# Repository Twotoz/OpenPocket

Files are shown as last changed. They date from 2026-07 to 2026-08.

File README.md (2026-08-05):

<p align="center">
  OpenPocket — an ESP32-S3 handheld FPV controller with an AMT630A display
</p>

<p align="center">
  
  
  
  
  
  
</p>

<p align="center">
  <strong>A compact all-in-one ESP32-S3 handheld PCB combining RivetTX, ExpressLRS, RX5808 video, AT7456E OSD, and an AMT630A-driven 5-inch TFT.</strong>
</p>

<p align="center">
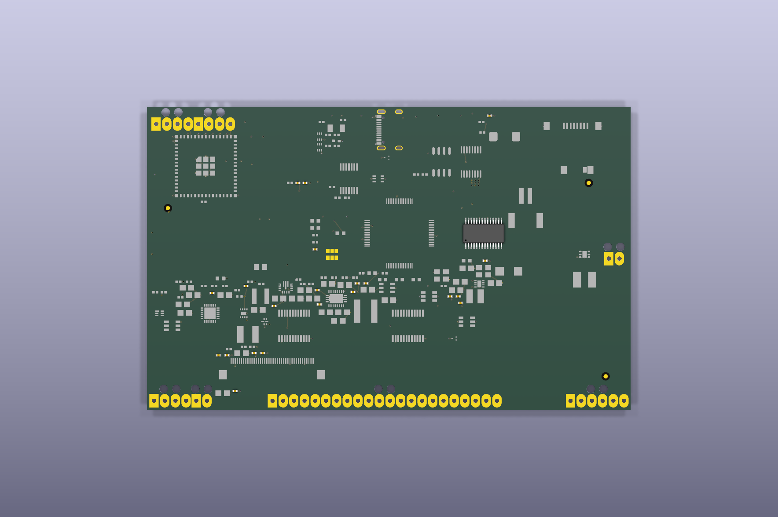
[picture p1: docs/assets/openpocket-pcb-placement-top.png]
OpenPocket Revision-A top-side component placement without board text or signal traces
  
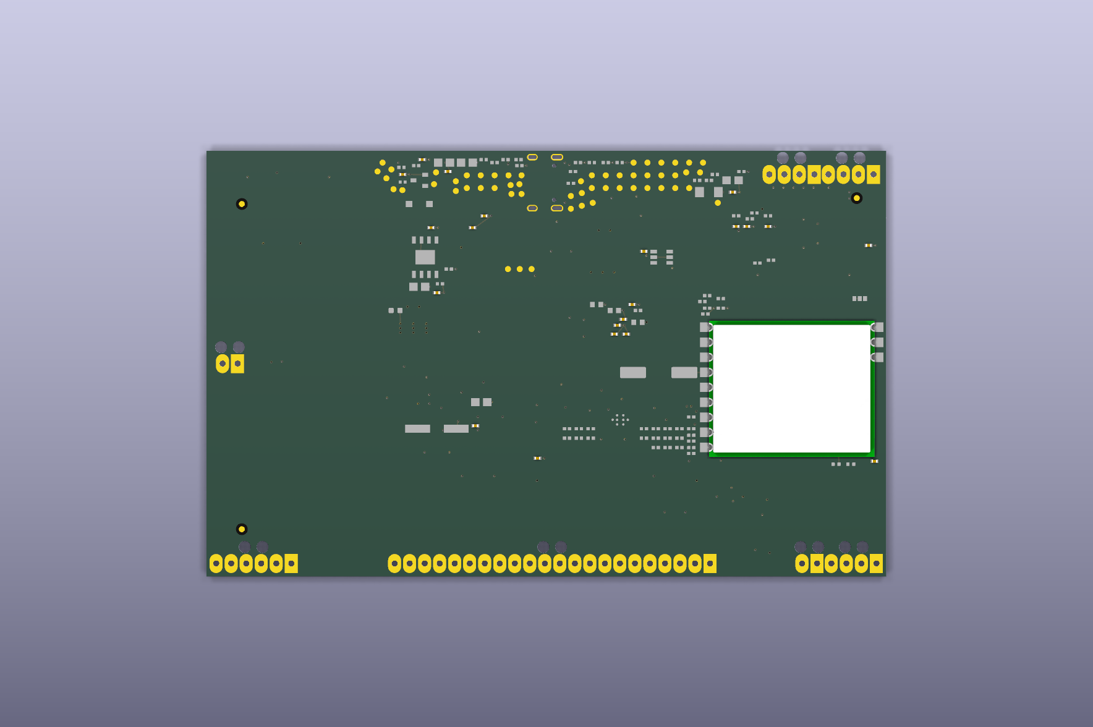
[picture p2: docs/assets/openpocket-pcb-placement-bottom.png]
OpenPocket Revision-A bottom-side component placement without board text or signal traces
  
</p>

<p align="center"><em>Revision-A top and bottom placement previews — production-board text and signal routing intentionally omitted.</em></p>

<p align="center">
  <a href="#why-openpocket">Why OpenPocket</a> ·
  <a href="#architecture">Architecture</a> ·
  <a href="#hardware">Hardware</a> ·
  <a href="#build-path">Build path</a> ·
  <a href="#firmware">Firmware</a> ·
  <a href="#documentation">Documentation</a>
</p>

> [!CAUTION]
> OpenPocket is an engineering prototype, not a flight-proven product. Build
> the first revision on a current-limited bench supply. Keep propellers removed
> and mechanisms safe until your exact transmitter, failsafe, power system,
> RF link, and video chain have passed hardware-in-the-loop validation.

## Why OpenPocket

OpenPocket puts the controls, live analog FPV picture, and transmitter menus in
one compact handheld. It uses the existing RivetTX OpenPocket character
compositor unchanged and connects it to a physical AT7456E video-overlay
backend. The ESP32 never has to capture or process video pixels.

| | |
|---|---|
| **One handheld** | Gimbals, switches, ExpressLRS control, telemetry, video, and menus in a single enclosure. |
| **Purpose-built MCU** | ESP32-S3 provides the GPIO, native USB, and task separation needed by the complete controller. |
| **Low-latency video** | RX5808 composite video passes through the AT7456E into an AMT630A TFT controller without digital capture. |
| **Integrated snow-screen display** | The PCB-installed AMT630A keeps weak or lost analog video visible as noise instead of hiding it behind a blue screen. |
| **Native analog OSD** | PAL/NTSC autodetection, a 30×16 character grid, custom glyphs, delta updates, and video-loss recovery. |
| **Bounded background work** | OSD and receiver services cannot delay control, CRSF, or telemetry processing. |
| **Open development path** | Wiring, BOM decisions, bring-up evidence, and future KiCad sources live in this repository. |

## Architecture

The flight-control path stays short while video and presentation work run as
bounded services.

```mermaid
flowchart LR
    A[Gimbals + switches] --> B[ESP32-S3<br/>RivetTX]
    B --> C[CRSF UART]
    C --> D[ExpressLRS<br/>TX module]

    E[5.8 GHz antenna] --> F[RX5808]
    F -->|composite video| G[AT7456E]
    G -->|internal PCB trace| H[AMT630A<br/>on the same PCB]
    H -->|24-bit RGB + sync| I[AT050TN33 V.1<br/>40-pin TFT]

    B -->|tune + RSSI| F
    B -->|bounded SPI| G
    D -->|telemetry| B

    classDef control fill:#102a43,stroke:#38bdf8,color:#f8fafc;
    classDef video fill:#26163f,stroke:#a78bfa,color:#f5f3ff;
    class A,B,C,D control;
    class E,F,G,H,I video;
```

The 250 Hz control task owns channel output and safety. The OSD driver advances
a non-blocking state machine and writes only changed character runs. Video
loss, PAL/NTSC changes, or an absent OSD chip must never hold up the control
path.

## Hardware

| Component | Role |
|---|---|
| ESP32-S3-MINI-1U-N8 | PCB-installed RivetTX MCU, native USB, 8 MiB flash, no PSRAM |
| user-installed ExpressLRS nano receiver | four-wire full-duplex CRSF control and telemetry link |
| PCBWay-installed RX5808 module | tunable 5.8 GHz analog receiver, internal composite video, and RSSI |
| PCB-installed AT7456E | PAL/NTSC character overlay in the internal video path |
| PCB-installed AMT630A and flash | PAL/NTSC composite decoding and direct 24-bit RGB panel drive |
| AT050TN33 V.1-compatible TFT | user-plugged 40-pin panel; arbitrary 40-pin TFTs are unsupported |
| two dual-axis gimbals | four primary analog control axes |
| switches, menu buttons, and optional encoder | arming, AUX controls, navigation, and editing |
| validated regulators and protection | clean supplies sized for RF, display, video, and logic peaks |

The ESP32-S3 is the OpenPocket target. RivetTX may support smaller ESP32-C3
transmitters, but the C3 is not the reference platform for this handheld. See
[ADR-0001](docs/decisions/0001-esp32-s3.md) for the decision record.

## Analog OSD

The existing RivetTX compositor produces a hardware-independent 30-column by
16-row character frame. The AT7456E backend then provides:

- PAL/NTSC autodetection and safe standard changes without a reboot
- all 30×16 cells in PAL, with essential content held inside 30×13 for NTSC
- custom character uploads for icons, selection markers, and warnings
- shadow-frame comparison so unchanged cells generate no SPI traffic
- bounded asynchronous transfers instead of full-screen blocking redraws
- communication retry/backoff and redraw after video loss or recovery

The RX5808 feeds baseband video to the AT7456E over an internal PCB trace; the
AT7456E overlays text and passes it internally to the AMT630A, which drives the
edge-connected TFT directly. The user never wires composite video. The
AMT630A's internal OSD is not used for OpenPocket menus. See the
[complete wiring guide](docs/wiring.md).

## Build path

Bring up one subsystem at a time:

1. Review the [Revision-A engineering package](hardware/rev-a/README.md) and
   resolve every machine-readable release blocker.
2. Complete independent schematic, layout, sourcing, and Gerber reviews.
3. Assemble first articles through PCBWay with the RX5808 consigned/manual
   operation and no unapproved substitutions.
4. Power the board from a current-limited source and validate rails before
   inserting the TFT, battery, or ExpressLRS receiver.
5. Complete the factory and HIL gates before any propeller-on use.

The [bench build guide](docs/build-guide.md) contains the full sequence and
stop conditions. Do not order from provisional files or bypass the release
gate in `hardware/rev-a`.

## Firmware

OpenPocket runs the `main` branch of
[Twotoz/RivetTX](https://github.com/Twotoz/RivetTX):

```bash
git clone https://github.com/Twotoz/RivetTX.git
cd RivetTX
idf.py set-target esp32s3
idf.py menuconfig
idf.py build
idf.py flash monitor
```

Use RivetTX's checked-in `sdkconfig.openpocket-rev-a.defaults`; it contains the
authoritative no-PSRAM, 8 MiB flash configuration and GPIO map matching this
board. See the [firmware guide](docs/firmware.md) for the complete configuration.

## Documentation

| Document | Contents |
|---|---|
| [Bill of materials](docs/bom.md) | prototype parts, electrical requirements, and unresolved selections |
| [Wiring](docs/wiring.md) | ESP32-S3, RX5808, AT7456E, AMT630A, TFT, and ExpressLRS interconnects |
| [Bench build guide](docs/build-guide.md) | staged assembly sequence and stop conditions |
| [Firmware](docs/firmware.md) | ESP32-S3 target setup and RivetTX OSD configuration |
| [Bring-up checklist](docs/bring-up.md) | electrical, control, PAL/NTSC, failure-recovery, and endurance tests |
| [Architecture](docs/architecture.md) | task boundaries, character presentation, and video path |
| [ESP32-S3 decision](docs/decisions/0001-esp32-s3.md) | why OpenPocket standardizes on the S3 |
| [AMT630A display decision](docs/decisions/0002-amt630a-snow-screen.md) | why the display stage uses a snow-screen AMT630A board |
| [Hardware sources](hardware/README.md) | scope and release policy for future KiCad and production files |
| [Revision-A package](hardware/rev-a/README.md) | integrated board constraints, GPIO, power, BOM, factory test, and release gates |
| [AMT630A firmware](display/amt630a/README.md) | target behavior, provenance requirements, and deterministic build gate |

## Project status

RivetTX contains the character OSD and physical RX5808/AT7456E services, with
host coverage for PAL, NTSC, UI, tuning, scanning, RSSI, delta updates, glyphs,
loss/recovery, and failure isolation. Revision-A startup ordering, board power
policy, and the no-PSRAM pin/partition profile are under review.

No PCB order package is released yet. The exact panel datasheet, AMT630A
firmware rights/provenance, selected RX5808 consigned module, sourcing review,
KiCad ERC/DRC, Gerber inspection, and physical HIL evidence remain open. This
is intentionally an engineering prototype, not a production-ready product.

## Contributing

Issues, schematic reviews, module measurements, and focused pull requests are
welcome. Hardware findings must identify the exact module revision, voltage,
firmware commit, measurement point, and PAL/NTSC source. See
[CONTRIBUTING.md](CONTRIBUTING.md).

## License

OpenPocket documentation and future hardware sources are released under the
[MIT License](LICENSE). RivetTX is maintained in its own repository under its
own license.

---

<p align="center">
  <sub>Built for open hardware experimentation, low-latency analog FPV, and careful validation.</sub>
</p>

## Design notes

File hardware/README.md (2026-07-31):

# Hardware sources

The [Revision-A engineering package](rev-a/README.md) is the authoritative
location for the integrated board's requirements, controlled selections, and
release evidence. It will contain the releasable sources for:

- KiCad schematic and PCB files
- controlled BOM with manufacturer part numbers
- integrated AMT630A circuit, licensed flash revision, and matched TFT panel
- Gerber, drill, and pick-and-place files
- mechanical drawings and enclosure interfaces
- test points and fixture documentation

No production files have been released yet. `rev-a/tools/release_gate.py`
refuses artifact generation while primary-source, sourcing, review, or HIL
evidence is missing. Use first articles only on a current-limited bench until
all formal and physical gates pass.

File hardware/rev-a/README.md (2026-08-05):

# OpenPocket Revision A — Engineering Prototype

Revision A is a 115 mm × 72 mm, eight-layer, all-in-one transmitter board based
on the ESP32-S3-MINI-1U-N8. The intended assembled signal path is:

```text
5.8 GHz antenna -> RX5808 -> AT7456E -> AMT630A -> 40-pin ER-TFT050A3-2
```

Composite video never leaves the PCB. JLCPCB Standard PCBA is the primary
assembly target, with pre-order and consigned-RX5808 variants; the design is
vendor-neutral. The user installs
only the TFT panel, controls, one wired protected 1S battery connection,
antennas, a pre-flashed ExpressLRS nano receiver, and the enclosure.

## Release state

This directory is an engineering-review package, not an order package. The
release script intentionally refuses to generate Gerbers or a manufacturing
ZIP until every blocking item in `release-status.json` is resolved with a
reviewed source artifact.

The generated KiCad draft has a clean ERC and a completed L2 ground fanout,
but signal routing and final DRC remain incomplete. It is therefore not a
fabrication/order package. The source-built AMT630A firmware and circuit
research may be reviewed independently, but they do not waive schematic,
layout, Gerber and first-article gates. Software tests are not hardware
validation.

## Design constraints

- 115 mm × 72 mm fixed outline.
- Eight layers, 1.0 mm finished thickness, 1 oz copper, ENIG.
- L1/L8 components and critical routing, uninterrupted L2/L7 ground, and six
  available routing layers for signals and width-controlled power routes.
- RX5808 on the bottom side with shield, solder-joint, antenna and inspection
  clearances; J11 U.FL/MHF1 is also bottom-side for a via-free 5.8 GHz feed.
- AMT630A next to the edge-mounted TFT connector; AT7456E on the short analog
  path between RX5808 and AMT630A.
- Backlight switching and power converters stay outside the analog/RF region.
- Separate ESP32, ELRS 2.4 GHz, and RX5808 5.8 GHz antenna regions.
- Dedicated user-accessible push-push microSD at 1-bit/20 MHz maximum, with
  switched power and enclosure finger/eject clearance.
- Board marking: `OpenPocket Rev A` and `Engineering Prototype`.

## Contents

| File | Purpose |
|---|---|
| `gpio-map.md` | authoritative ESP32 and expander allocation |
| `microsd.md` | SDMMC circuit, socket audit, limits and acceptance tests |
| `wiring.md` | internal and user-installed connections |
| `power-budget.md` | preliminary worst-case and thermal calculations |
| `routing-constraints.md` | KiCad netclasses, widths, vias and routing order |
| `stackup.md` | nominal 1.0 mm eight-layer construction and impedance sign-off gate |
| `bom.csv` | controlled component selection and verification state |
| `dnp.csv` | optional/DNP items |
| `consigned-parts.csv` | RX5808 manual-assembly requirement |
| `release-status.json` | machine-readable evidence and blockers |
| `factory-test.md` | pass/fail protocol and first-article sequence |
| `pcbway-notes.md` | stack-up, assembly, inspection, and substitution rules |
| `tools/release_gate.py` | refuses an unsafe manufacturing release |

Fabrication outputs and a versioned release ZIP must only be generated after
the KiCad sources pass review, ERC, DRC and independent Gerber inspection.

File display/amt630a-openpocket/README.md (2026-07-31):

# OpenPocket AMT630A firmware

This directory contains an original MIT-licensed SDCC/mcs51 firmware for the
AMT630A used by OpenPocket Revision A. It is built from register documentation,
the AMT630A product specification, and public reference-circuit observations;
it is not a monitor-board dump and contains no vendor firmware.

`make test` builds a deterministic 64 KiB W25X05 image and verifies panel
timing, PAL/NTSC state handling, sync-loss recovery, CVBS1 selection, RGB pin
muxing, and that documented snow/blue-substitution controls are disabled. The
controller keeps TFT timing active during video loss and pulses decoder resync
until video returns. Whether a particular weak RF signal visibly produces the
desired snow texture remains a first-article acceptance measurement.

The RivetTX factory service holds AMT RESET low, selects the ESP32 side of U19
(SN74CB3Q3257PWR), checks JEDEC ID `EF 30 10`, erases/programs/reads every byte,
compares SHA-256, restores AMT ownership, releases reset, then waits for I2C
status before enabling the backlight.

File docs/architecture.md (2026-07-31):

# Architecture

OpenPocket separates flight-critical control from slower presentation and
hardware services.

```text
high priority: inputs -> mixer -> safety -> CRSF channels -> ExpressLRS
low priority:  UI snapshots -> character compositor -> AT7456E SPI
low priority:  RX5808 tune/scan + RSSI
services:      telemetry, storage, audio, USB, and maintenance
```

The 250 Hz control task owns channel output and the watchdog. OSD, video scan,
file I/O, and network services must not block that task. The AT7456E driver is
therefore a bounded state machine that starts or completes at most one short
SPI transaction per tick.

## Presentation

RivetTX provides a hardware-independent grid of 30 columns and 16 rows. The
AT7456E backend detects PAL/NTSC, maintains a shadow frame, and writes only
changed runs. PAL uses all 16 rows; NTSC uses the safe first 13 rows. Character
uploads are maintenance operations and are not written to NVM on every boot.

## Video

The RX5808 produces baseband composite video. The AT7456E separates sync and
mixes in characters. Its composite output enters the selected AMT630A
snow-screen controller board, which decodes and scales the picture for its
matched parallel-RGB TFT panel. The ESP32 does not process pixels and is not
part of the analog video path.

The AMT630A's built-in OSD is not part of the OpenPocket presentation path.
RivetTX continues to render through the AT7456E so menus have one compositor,
one character set, and one tested failure model. The display board must be a
no-blue-screen firmware variant: weak or absent RX5808 video remains visible as
noise rather than being hidden by a solid fallback color.

## Open design work

- exact ESP32-S3 module and GPIO map
- RX5808 revision, tuning interface, and RSSI calibration
- power tree, charger, battery protection, and power latch
- exact AMT630A board revision, matching TFT panel, and connectors
- KiCad schematic, PCB zones, and mechanical integration
- production test points and HIL fixture

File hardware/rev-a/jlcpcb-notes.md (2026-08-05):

# JLCPCB Standard PCBA order notes

Product marking: **OpenPocket Rev A — Engineering Prototype**.

- PCB: 115.00 mm × 72.00 mm, eight layers, 1.0 mm finished thickness, 1 oz on
  every copper layer, ENIG, green solder mask unless the quote specifies
  another colour.
- L2 and L7 are uninterrupted ground references. Do not substitute split
  planes. Request JLC's controlled-impedance review for
  native USB and the short 50 Ω RX5808 antenna feed before order approval.
- Assembly service: Standard PCBA, both sides. No substitutions are permitted
  for power ICs, AT7456E, AMT630A, translators, crystals, display connector,
  protection IC/MOSFET, buzzer or speaker amplifier without a schematic-owner
  ECO.
- Use either `OPENPOCKET-REV-A-JLC-PREORDER` with RX5808 `C2908157`, or
  `OPENPOCKET-REV-A-JLC-CONSIGNED-RX5808`. Both variants use the same PCB.
- For the consigned variant, MOD1 must already have the documented RTC6715 SPI
  enable modification. Align pin 1 and shield outline, use the fixture/manual
  placement drawing, inspect every elongated joint, and continuity-test DATA,
  LE, CLK, RSSI, VIDEO, 5 V and all grounds before electrical test.
- JP1 is a hand-soldered diagnostic feature. Factory NORMAL state bridges
  pads 1–2 and 4–5 only. Never bridge BYPASS without cutting both NORMAL
  bridges. This prevents driver contention and removes the OSD input
  termination in bypass mode.
- Do not populate DNP designators. Integral user solder pads and ENIG test
  pads appear in the DNP list but are PCB features, not missing components.
- Program the ESP32 factory image over native USB-C using the supplied flash
  arguments. It verifies/programs the approved AMT630A image through the
  isolated flash mux while AMT reset is asserted, then reports newline-delimited
  JSON. Ship only a unit whose mandatory summary record is `passed:true`.
- J1 is a bottom-contact FH12-40S-0.5SH(55). Inspect pin 1, actuator operation,
  FPC insertion direction and absence of solder bridges at 20× magnification.
- Populate J11 (Hirose U.FL-R-SMT-1(10)) on the bottom side. Inspect its centre
  contact and ground tabs at magnification; J10 intentionally does not exist,
  because a second antenna branch would form a 5.8 GHz stub.
- Keep RX5808, ESP32 U.FL/coax, ELRS and buzzer/speaker acoustic regions free of
  labels, fixture clamps, adhesive and packing material.

The release ZIP is also vendor-neutral. PCBWay or another assembler can use
the generic BOM/position files and the same Gerbers without schematic changes.

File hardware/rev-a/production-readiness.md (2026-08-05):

# OpenPocket Revision-A production-readiness review

Review date: 2026-08-05
Classification: **engineering prototype — manufacturing release blocked**

This document records the pre-fabrication checks performed on the generated
KiCad 9 sources. It is not an order approval. release_gate.py remains the
authoritative fail-closed release control.

## Release decision

Revision A is not yet production-ready. The current 115 x 72 mm eight-layer
PCB contains deterministic L2/L7 ground fanout, but the new signal route has
not yet been accepted. KiCad still reaches its 499-item unconnected-report
limit on this clean routing seed. L2 and L7 are explicit uninterrupted ground
planes; F.Cu, SIG1-SIG4, and B.Cu are available for routing. Earlier four- and
six-layer experiments were not imported.

Do not upload the generated Gerbers to a fabricator until routing, impedance,
mechanical, independent schematic/layout, custom-part, and first-article gates
are closed.

## Verified results

| Check | Result | Evidence / disposition |
|---|---:|---|
| KiCad 9 ERC | 0 errors, 0 warnings | kicad-cli sch erc |
| KiCad 9 geometric DRC | 0 errors, 1 warning | One location-less F.Cu copper-sliver warning; connectivity separately reaches the 499-item report limit |
| PCB stack | 8 copper layers, 1.0 mm, 115 x 72 mm | KiCad PCB source and Gerber job data |
| Assembly fiducials | 3 top, 3 bottom | 1.0 mm copper / 2.0 mm mask opening |
| Exposed-pad thermal vias | U2: 9, U11: 9, U21: 9 | 0.45/0.20 mm tented, footprint-embedded vias to GND |
| L2/L7 ground fanout | stored pad fanout plus two plane fills, 0 open GND items | No signal copper is permitted on L2/L7 |
| BOM completeness | 229 populated components, 95 populated line items | Every populated line has manufacturer, MPN, LCSC code, and package |
| BOM/CPL population set | exact match | DNP entries are excluded from assembly placement |
| LCSC snapshot | 85 exact matches with stock; 2 custom codes unresolved | 87 unique non-CONS codes checked against the LCSC/JLC search API |
| AMT firmware tests | 5 passed | deterministic rebuild, manifest, timing, register integrity, state machine |
| Manufacturing generator | completed | Gerbers, drill, BOM/CPL, drawings, board-only STEP, firmware, checksums, and ZIPs |
| ZIP integrity | passed | JLCPCB and PCBWay ZIPs tested with unzip -t |

The two unresolved supplier codes are C2908157 (modified RX5808 module) and
C9900018923 (AMT630A). They are intentionally covered by preorder/consigned
assembly instructions; current API lookup did not return either code.

## Analyzer results and limits

- Full PCB analysis: 370 findings — 234 errors, 18 warnings, and 118 information
  items. Of the errors, 233 are the unrouted-net findings; the remaining
  board-edge finding is the intentional edge-mounted microSD connector and
  still requires enclosure/mechanical sign-off.
- EMC pre-compliance analysis: score 79.0/100, with 0 errors and 19 warnings.
  The warnings concern decoupling-via proximity and heuristic switching
  regulator/filter estimates. The report has low trust because extracted
  datasheet coverage is absent and 233 signal nets are not routed.
- Gerber analysis: 0 errors and 1 alignment warning. Copper/edge extents differ
  while routing copper is absent, so this is not a fabrication approval.
- Schematic analysis: 5 heuristic voltage-domain errors and 27 warnings.
  Four domain findings are around the intentional SN74AHCT125 3.3 V-to-5 V
  input stage; the backlight PWM finding also needs datasheet-backed review.
  These findings are not closed merely because ERC passes.
- Thermal analysis was skipped by the analyzer because no extracted
  per-MPN power/thermal dataset was available.
- SPICE validation was not run because ngspice, Xyce, and LTspice were not
  installed in the review environment.
- The LCSC-only lifecycle audit returned unknown for all 87 unique MPNs by
  construction; it is a stock lookup source, not lifecycle evidence.

## Required work before release

1. Route every net and hand-review USB, RX5808 RF, analog video, switching
   nodes, high-current paths, clocks, RGB, and return paths.
2. Obtain clean KiCad DRC with zero unconnected items; rerun PCB, cross-domain,
   EMC, thermal, Gerber, BOM/CPL, and release-gate checks on that exact route.
3. Perform the ER-TFT050A3-2 flex pin-1 and enclosure-stack overlay and approve
   the edge-mounted USB-C and microSD mechanical clearances.
4. Complete independent pin-by-pin schematic and layout reviews.
5. Obtain assembler acceptance for AMT630A and modified RX5808
   preorder/consignment, including the SPI-enable work instruction and an
   inspected sample.
6. Complete the independent AMT630A clean-room/license review.
7. Approve the final JLCPCB/PCBWay stack-up and controlled-impedance geometry.
8. Build and electrically validate first articles using factory-test.md and
   first-power-up.md; only then update release-status.json.

Generated manufacturing output is deliberately ignored by Git. Regenerate it
from the reviewed source with:

~~~sh
python3 hardware/rev-a/tools/generate_manufacturing.py
python3 hardware/rev-a/tools/release_gate.py
~~~

The second command must remain blocked until all evidence above is attached
and every release-status gate is explicitly resolved.

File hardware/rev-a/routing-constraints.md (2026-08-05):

# Revision-A routing constraints

These KiCad netclasses are mandatory engineering constraints for placement and
routing. They prevent a generic-width autoroute from being confused with a
reviewed layout. Widths for USB and RF are preliminary until the assembler
confirms the exact 1.0 mm eight-layer stack-up and returns an impedance review.

L2 (`GND1`) and L7 (`GND2`) are uninterrupted reference planes and must never
carry signal tracks. Ordinary signals and width-controlled power routes may
use F.Cu, SIG1, SIG2, SIG3, SIG4, and B.Cu subject to the critical-route order
below.

| Netclass | Clearance | Track | Via / drill | Intended use |
|---|---:|---:|---:|---|
| `FinePitch` | 0.10 mm | 0.12 mm | 0.45 / 0.20 mm | AMT630A RGB escape and panel bus |
| `DigitalFast` | 0.12 mm | 0.15 mm | 0.50 / 0.25 mm | SPI, SDMMC, I2S and RX control |
| `USB_Preliminary` | 0.15 mm | 0.15 mm | 0.45 / 0.20 mm | native USB D+/D-; hand-route as a pair |
| `AnalogVideo` | 0.15 mm | 0.25 mm | 0.60 / 0.30 mm | RX5808, AT7456E and AMT630A CVBS path |
| `RF_Preliminary` | 0.30 mm | 0.25 mm | 0.60 / 0.30 mm | short RX5808-to-coax feed; hand-route |
| `PowerLogic` | 0.15 mm | 0.40 mm | 0.70 / 0.35 mm | 3.3 V domains, speaker and local rails |
| `Power` | 0.15 mm | 0.80 mm | 0.80 / 0.40 mm | switched 5 V distribution |
| `HighCurrent` | 0.20 mm | 1.20 mm | 1.00 / 0.50 mm | battery, USB, charger and main rails |
| `SwitchNode` | 0.20 mm | 0.80 mm | 0.80 / 0.40 mm | converter switch loops; keep short |
| `BacklightHV` | 0.20 mm | 0.40 mm | 0.70 / 0.35 mm | boosted LED anode/cathode path |
| `Ground` | 0.10 mm | 0.50 mm | 0.70 / 0.35 mm | L2/L7 plane fan-out and stitching |
| `Default` | 0.10 mm | 0.20 mm | 0.60 / 0.30 mm | low-speed control and sensing |

## Routing order

1. Lock the reviewed component placement and mechanical keep-outs.
2. Hand-route switch loops, crystal loops, CVBS, RX RF and USB.
3. Route main power and ground fan-out, then verify return paths on L2/L7.
4. Route RGB, SDMMC, SPI/I2S and remaining low-speed controls.
5. Add ground stitching without breaking the RF, video or USB return paths.
6. Refill zones and require clean KiCad ERC/DRC with zero unconnected pads.

Autorouting may be used only as a seed for non-critical nets. Its imported
session must preserve these netclasses and is never evidence of impedance,
thermal, EMI or manufacturing approval by itself.

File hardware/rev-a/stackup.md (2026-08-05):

# Revision-A eight-layer stack-up

The KiCad source and Gerber job file carry this symmetric nominal 1.00 mm
construction. It is an order target; the fabricator must substitute its
available pressed materials while preserving 1.00 mm finished thickness and
confirming the impedance geometries before fabrication.

| Order | Layer/material | Nominal thickness |
|---:|---|---:|
| 1 | Top solder mask, green | 0.010 mm |
| 2 | L1 `F.Cu`, 1 oz | 0.035 mm |
| 3 | FR-4 prepreg | 0.100 mm |
| 4 | L2 `GND1`, 1 oz, continuous reference | 0.035 mm |
| 5 | FR-4 core | 0.100 mm |
| 6 | L3 `SIG1`, 1 oz | 0.035 mm |
| 7 | FR-4 prepreg | 0.100 mm |
| 8 | L4 `SIG2`, 1 oz | 0.035 mm |
| 9 | FR-4 core | 0.100 mm |
| 10 | L5 `SIG3`, 1 oz | 0.035 mm |
| 11 | FR-4 prepreg | 0.100 mm |
| 12 | L6 `SIG4`, 1 oz | 0.035 mm |
| 13 | FR-4 core | 0.100 mm |
| 14 | L7 `GND2`, 1 oz, continuous reference | 0.035 mm |
| 15 | FR-4 prepreg | 0.100 mm |
| 16 | L8 `B.Cu`, 1 oz | 0.035 mm |
| 17 | Bottom solder mask, green | 0.010 mm |

Nominal total: `2 × 0.010 + 8 × 0.035 + 7 × 0.100 = 1.000 mm`.
Surface finish is ENIG. L2 and L7 are uninterrupted ground-reference planes
and must not carry signal tracks. Signal and routed power distribution may use
L1/L3/L4/L5/L6/L8 subject to the netclass widths and return-path review.

Before order approval, request and record:

- the fabricator's exact low-cost 8-layer/1.0 mm pressed stack and tolerance;
- 90 ohm differential geometry for USB D+/D- on L1 referenced to L2;
- 50 ohm grounded-coplanar geometry for `RX_RF` on L1 referenced to L2;
- any required width/spacing ECO, followed by KiCad DRC and fresh Gerbers.

Manufacturer references checked on 2026-08-05:

- JLCPCB PCB capabilities: <https://jlcpcb.com/capabilities/Capabilities?type=1>
- JLCPCB multilayer overview: <https://jlcpcb.com/resources/multiple-layer-pcb>
- JLCPCB impedance-calculator guide:
  <https://jlcpcb.com/help/article/user-guide-to-the-jlcpcb-impedance-calculator>

JLCPCB lists FR-4 thicknesses including 1.0 mm and multilayer production, but
the order configurator/fabricator review remains authoritative for the exact
8-layer stack code. Do not freeze controlled-impedance widths without that
order-specific confirmation.

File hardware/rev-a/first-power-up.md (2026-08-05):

# Revision-A first power-up and acceptance limits

This procedure is for `OpenPocket Rev A — Engineering Prototype`. It defines
the measurements to perform on every first article; it does not claim that an
unbuilt board has passed them.

## Equipment and initial state

Use a current-limited 5.00 V laboratory supply or USB current injector, a
4-channel oscilloscope of at least 200 MHz with short ground springs, a DMM,
thermal camera, programmable 0–4.2 V battery emulator, PAL/NTSC pattern source,
and an electronic load. Fit no cell, TFT, ELRS receiver or antenna for the
first stage. Leave the external latching power switch open.

Before applying power, microscope-inspect polarity and pin 1 on U2/U3/Q1/U5/
U6/U10/U11/U14/U17/U20, both crystals, J1 and MOD1. Resistance from VBUS_USB,
SYS_ALWAYS, SYS_SWITCHED, 3V3_LOGIC and SYS_SWITCHED_5V to ground must exceed
10 kΩ after capacitors charge; any steady reading below 100 Ω is a hard fail.

## Controlled sequence

1. Set 5.00 V, 100 mA current limit and apply USB with the master switch open.
   `SYS_ALWAYS` must rise to 3.50–4.55 V within 100 ms, while `SYS_SWITCHED`,
   `3V3_LOGIC` and `SYS_SWITCHED_5V` remain below 0.20 V. Expected settled USB
   current is 1–10 mA; reaching the limit is a fail.
2. Raise the limit to 500 mA and close the master switch. `POWER_GOOD` must go
   high after the TPS22992 controlled rise, `3V3_LOGIC` must be 3.20–3.40 V,
   and native USB must enumerate within 3 s. Expected ESP32 boot current is
   40–300 mA from USB; a sustained value above 400 mA with all 5 V domains off
   is a fail.
3. The safe boot state is `5V_VIDEO`, `5V_DISPLAY`, `5V_ELRS`, `3V3_SD`,
   `LCD_DISP`, backlight PWM, NS4168 enable and buzzer PWM all low. AMT reset is
   asserted until display power is valid. Any enabled RF rail or audible output
   before firmware requests it is a fail.
4. Raise the supply limit to 2.5 A. Enable video, then display logic, release
   AMT reset, assert DISP, and finally ramp backlight. Nominal delays are
   10 ms after a load-switch rise, 20 ms after display 3.3 V Power Good,
   100 ms maximum for AMT ready, and at least 20 ms from valid panel timing to
   the first non-zero backlight PWM. Shutdown is the reverse order.
5. Enable ELRS only after simulator mode is confirmed off and ARM/CH5 is low.
   The factory image never enables ELRS automatically.

## Test-point limits

| Test point | Expected enabled voltage | Ripple/step limit | Disabled limit |
|---|---:|---:|---:|
| `SYS_ALWAYS` | 3.50–4.55 V | 150 mV p-p | present for charging |
| `SYS_SWITCHED` | within 100 mV of SYS_ALWAYS | 150 mV p-p | <0.20 V |
| `3V3_LOGIC` | 3.20–3.40 V | 75 mV p-p | <0.20 V |
| `SYS_SWITCHED_5V` | 4.85–5.15 V | 100 mV p-p | <0.20 V |
| `5V_VIDEO` | 4.80–5.15 V | 75 mV p-p | <0.20 V |
| `5V_DISPLAY` | 4.80–5.15 V | 100 mV p-p | <0.20 V |
| `5V_ELRS` | 4.75–5.15 V | 150 mV p-p | <0.20 V |
| `DISPLAY_3V3` | 3.20–3.40 V | 50 mV p-p | <0.20 V |
| `PANEL_3V3` | 3.15–3.40 V | 50 mV p-p | <0.20 V |
| `3V3_SD` | 3.135–3.465 V | 100 mV p-p | <0.20 V |
| `BL_LED_A` | 15–22 V with panel | 300 mV p-p | <1.0 V |

Use the adjacent ground test point and a ground spring for every ripple test.
No switch node may overshoot its component absolute maximum. Backlight LED
current must be 38.4–41.6 mA at 100% command; 42 mA is the production stop
limit. The hardware 4.99 Ω feedback resistor, not firmware, sets the ceiling.

## Subsystem current increments

At 5.0 V, expected current added by video is 190–300 mA, display logic
120–300 mA, 100% backlight 160–230 mA, ELRS 50–500 mA depending on its declared
power table, buzzer 60–110 mA while sounding, and the optional 8 Ω/1 W speaker
up to 280 mA. An increment outside its interval is a fail and the affected
load switch must be disabled immediately. The firmware prevents simultaneous
full-power speaker and continuous buzzer operation and limits Revision-A PCM
output to 1 W nominal.

## Fault response

A missing video, display, SD or ELRS subsystem produces a bounded timeout,
disables only its rail, records a machine-readable fault and leaves controls/
CRSF running. A rail short must trip the bench limit or local load protection;
firmware then latches that domain off until an explicit factory retry. A short
on `SYS_SWITCHED`, 3.3 V or main 5 V is a whole-board fail. USB removal while a
battery is present and battery insertion/removal while USB is present must not
reset the controller or pulse ELRS/backlight on. Repeated brownout booting is a
fail; low battery instead disables ELRS, dims the backlight and performs the
documented orderly shutdown.

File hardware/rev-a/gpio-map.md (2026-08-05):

# Revision-A GPIO allocation

Target module: ESP32-S3-MINI-1U-N8, 8 MiB flash, no PSRAM. GPIO19/20 are native
USB. GPIO0 is retained as a boot/recovery strap and is available at an ENIG
factory test point; ESP_EN/RESET is exposed the same way. The attached NS4168
I2S inputs are high impedance while GPIO45/GPIO46 strap levels are sampled,
then become ordinary I2S outputs after boot. Analog controls
and RX5808 RSSI use ADC1 only.

| GPIO | Direction | Function | Electrical notes |
|---:|---|---|---|
| 0 | input/strap | ESP boot/recovery | external 10 kΩ pull-up; accessible ENIG test pad |
| 1 | input | left gimbal X | ADC1, 3.3 V maximum, RC filter |
| 2 | input | left gimbal Y | ADC1, 3.3 V maximum, RC filter |
| 3 | input | right gimbal X | ADC1, 3.3 V maximum, RC filter |
| 4 | input | right gimbal Y | ADC1, 3.3 V maximum, RC filter |
| 5 | input | RX5808 RSSI | ADC1, filtered and clamped |
| 6 | output | NS4168 enable | direct, hardware default-low |
| 7 | output | RX5808 DATA | 3.3 V RTC6715 SPI-like bus |
| 8 | output | RX5808 LE | latch enable |
| 9 | output | RX5808 CLK | bounded GPIO state machine |
| 10 | input | TCA9535 INT | active low, 3.3 V pull-up |
| 11 | output | AT7456E SCLK | through SN74AHCT125 |
| 12 | output | AT7456E MOSI | through SN74AHCT125 |
| 13 | input | AT7456E MISO | guaranteed 5 V-to-3.3 V translator |
| 14 | output | AT7456E CS | through SN74AHCT125; hardware pull-up |
| 15 | bidirectional | board I2C SDA | BQ25895, MAX17048, two TCA9535 |
| 16 | output | board I2C SCL | 400 kHz maximum |
| 17 | output | ELRS_RX | ESP32 CRSF TX through series resistor |
| 18 | input | ELRS_TX | ESP32 CRSF RX through series resistor |
| 19 | bidirectional | USB D- | native USB only |
| 20 | bidirectional | USB D+ | native USB only |
| 21 | output | AT7456E RESET | active low, level shifted |
| 26 | output | AMT flash CS | factory/recovery ownership only |
| 33 | output | AMT flash CLK | factory/recovery ownership only |
| 34 | output | AMT flash MOSI | factory/recovery ownership only |
| 35 | output | buzzer/haptic driver | transistor input, not direct load |
| 36 | output | AMT flash ownership | break-before-make bus switch control |
| 37 | input | AMT flash MISO | factory/recovery ownership only |
| 38 | output | AMT630A RESET | active low |
| 39 | output | NS4168 I2S BCLK | direct DMA-driven I2S |
| 40 | output | SD_CLK | native SDMMC, 27 Ω source resistor |
| 41 | bidirectional | SD_CMD | native SDMMC, 27 Ω source resistor |
| 42 | bidirectional | SD_D0 | native SDMMC 1-bit, 27 Ω source resistor |
| 43 | input | BQ25895 INT | active low |
| 44 | input | MAX17048 ALERT | active low |
| 45 | output | NS4168 I2S WS | direct DMA-driven I2S |
| 46 | output | NS4168 I2S DATA | direct DMA-driven I2S |
| 47 | output | TPS61165 PWM/EN | 20 kHz, default off |
| 48 | input | USB VBUS sense | protected resistor divider |

## TCA9535 control allocation

Both expanders are assembler-installed on the board I2C bus. Inputs are active
low with external pull-ups. Their I2C reads occur in `board_io_task`; the 250 Hz
control task consumes only the cached atomic snapshot.

| Snapshot bit | Input |
|---:|---|
| 0–3 | UP, DOWN, ENTER, BACK |
| 4 | ARM / AUX1 |
| 5–6 | AUX2 high / low |
| 7–8 | AUX3 high / low |
| 9–10 | AUX4 high / low |
| 11 | encoder press |
| 12–19 | AIL-, AIL+, ELE-, ELE+, THR-, THR+, RUD-, RUD+ |
| 20–21 | encoder A / B |
| 22 | microSD card detect, active low; inserted card closes switch to GND |
| 23 | `3V3_SD` TPS22918 enable, active high, external 100 kΩ pull-down |
| 24 | `5V_VIDEO` enable, active high, external pull-down |
| 25 | `5V_DISPLAY` enable, active high, external pull-down |
| 26 | `5V_ELRS` enable, active high, external pull-down |
| 27 | TFT `DISP`, active high; held low until AMT630A timing is ready |
| 28–31 | spare test capacity |

The matching firmware defaults are maintained in RivetTX
`sdkconfig.openpocket-rev-a.defaults`. Pin duplication, invalid outputs, and
RX5808 conflicts fail startup validation.

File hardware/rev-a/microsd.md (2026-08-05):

# Revision-A microSD subsystem

Revision A uses the SOFNG TF-001A-P3 push-push socket (`J12`, JLC/LCSC
`C3021282`) in dedicated ESP32-S3 SDMMC 1-bit mode. It is not connected to the
AT7456E SPI bus or AMT630A flash mux. The card ejects toward the top enclosure
edge; the card body, locked/ejected positions, finger access and push-push
travel are mechanical keep-outs.

## Electrical implementation

| Item | Selection / limit |
|---|---|
| Socket | SOFNG TF-001A-P3, 14.55 × 15.80 × 1.9 mm maximum envelope, normally-open card switch |
| Power switch | `U22` TPS22918DBVR, JLC/LCSC `C131941`, VIN=`3V3_LOGIC`, VOUT=`3V3_SD` |
| Card transient allowance | 300 mA minimum |
| Local capacitance | `C24` 100 nF 10 V 0402 + `C25` 10 µF 25 V 0805 + optional `C26` 47 µF 10 V 1206 |
| SD pull-ups | 10 kΩ to `3V3_SD` on CMD and DAT0/DAT1/DAT2/DAT3 |
| Card detect | socket switch to GND, 10 kΩ to `3V3_LOGIC`; logic 0 = card fully inserted |
| Series damping | 27 Ω on CLK, CMD and DAT0, placed at the ESP32 end |
| ESD | two TI TPD4E001DRLR arrays, JLC `C527516`, 1.5 pF/channel |
| Bus mode | SDMMC, 1-bit (`slot.width = 1`) |
| Clock | 400 kHz identification; 20 MHz maximum for Revision A |

TPS22918 worst-case room-temperature on-resistance is budgeted at 52 mΩ. At
300 mA this gives 15.6 mV drop and 4.7 mW dissipation. The 47 µF footprint is
provided because the effective capacitance of X5R MLCCs falls under DC bias;
with a conservative 33 µF combined effective capacitance, a 100 mA/10 µs load
edge produces approximately 30 mV capacitive droop before regulator response.
The acceptance limit at `TP_3V3_SD` is 3.135–3.465 V steady-state and less than
100 mV peak-to-peak ripple/step excursion during initialization and writes.

The 27 Ω resistors plus the ESP32 output impedance provide source damping for
the short 20 MHz traces. CLK/CMD/DAT0 must each be under 45 mm, remain on L1
over continuous L2 ground, use no stubs other than the adjacent ESD/test pad,
and avoid vias where possible. They must stay outside the CVBS, RSSI,
TPS61165, class-D, USB and all antenna exclusion regions. The 1.5 pF ESD load
adds roughly 75 ps at a 50 Ω source and is acceptable at the capped clock;
40 MHz remains firmware-disabled pending first-article eye/edge testing.

Test points are `TP_3V3_SD`, `TP_SD_CLK`, `TP_SD_CMD`, `TP_SD_D0`,
`TP_SD_DETECT`, and an adjacent ground pad. The socket shell uses four short
ground pads with local stitching into the uninterrupted L2 plane.

## Socket pin audit

| Socket pin | microSD function | Revision-A net |
|---:|---|---|
| 1 | DAT2 | `SD_DAT2`, 10 kΩ pull-up, ESD, no ESP32 connection |
| 2 | DAT3 / CS | `SD_DAT3`, 10 kΩ pull-up, ESD, no ESP32 connection |
| 3 | CMD | `SD_CMD`, GPIO41 through 27 Ω, 10 kΩ pull-up, ESD |
| 4 | VDD | `3V3_SD` |
| 5 | CLK | `SD_CLK`, GPIO40 through 27 Ω, ESD |
| 6 | VSS | GND |
| 7 | DAT0 | `SD_D0`, GPIO42 through 27 Ω, 10 kΩ pull-up, ESD |
| 8 | DAT1 | `SD_DAT1`, 10 kΩ pull-up, ESD, no ESP32 connection |
| 9 | card switch | `SD_CARD_DETECT`, closes to GND when inserted |
| shell | shield/retention | GND at four short pads |

The custom KiCad land pattern is derived from the SOFNG vertical-view drawing:
P1–P8 use 0.80 mm pitch, P9 is the independent card-switch pad, and all four
retention pads are present. Before fabrication release, the plotted pads and
card/eject outlines must be overlaid 1:1 against that drawing and inspected in
the enclosure STEP assembly.

## Factory and first-article acceptance

Use a 500 MHz or faster oscilloscope with a short ground spring and a
current-limited supply. With the radio master switch closed:

1. No card: detect high, `3V3_SD` below 0.20 V, radio controls and CRSF run for
   ten minutes with zero deadline misses.
2. Insert card: detect goes below 0.30 V and remains stable for the 80 ms
   debounce interval; `3V3_SD` reaches 90% within 5 ms and stays within
   3.135–3.465 V.
3. Initialization/write: rail excursion below 100 mV p-p, CLK has no
   overshoot above 3.6 V or below -0.3 V, and the card mounts as FAT32 at
   20 MHz or below.
4. Removal during continuous telemetry logging: the service unmounts and
   disables `3V3_SD`; control remains at 250 Hz, CRSF has no missed frame, and
   re-insertion recovers without reboot.
5. Corrupt BPB, FAT16, exFAT and unreadable media: no automatic format, update
   or flash action; the UI reports unavailable/corrupt and radio safety is
   unchanged.
6. Power-cycle the card 100 times and run 10,000 bounded log writes without a
   control deadline miss or a boot-critical configuration change.

Required card matrix (FAT32, one specimen each) is SanDisk Industrial 8 GB
`SDSDQAF3-008G-I`, Kingston Canvas Select Plus 16 GB `SDCS2/16GB`, and Samsung
PRO Endurance 32 GB `MB-MJ32KA`. Compatibility is not claimed until these
exact tests run on first articles; exFAT and arbitrary cards are outside the
Revision-A claim.

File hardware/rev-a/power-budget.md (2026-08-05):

# Revision-A power, ripple and runtime design budget

All values below are pre-fabrication calculations and conservative electrical
acceptance limits. First-article measurements must meet the already frozen
limits in `first-power-up.md`; they are not represented here as measured data.

## Load allocation

| Load | Rail | Normal | Design peak | Power at peak |
|---|---:|---:|---:|---:|
| RX5808 | 5V_VIDEO | 170 mA | 200 mA | 1.00 W |
| AT7456E + translators | 5V_VIDEO | 60 mA | 100 mA | 0.50 W |
| AMT630A + flash | DISPLAY_3V3 | 100 mA | 150 mA | 0.50 W |
| ER-TFT050A3-2 logic | PANEL_3V3 | 120 mA | 220 mA | 0.73 W |
| backlight, 2P6S | 5V_DISPLAY | 185 mA | 230 mA | 1.15 W |
| ELRS receiver-as-TX | 5V_ELRS | 100 mA | 500 mA | 2.50 W |
| PCB buzzer | switched 5 V | intermittent | 110 mA | 0.55 W |
| optional NS4168, 8 Ω/1 W limit | switched 5 V | off | 280 mA | 1.40 W |
| ESP32-S3 + board logic | 3V3_LOGIC | 180 mA | 800 mA | 2.64 W |
| microSD | 3V3_SD | 40 mA | 300 mA | 0.99 W |

The firmware keeps the speaker off unless explicitly requested, disables ELRS
in simulator mode, and does not schedule a continuous buzzer tone with maximum
speaker output. The 5 V continuous design point is 2.0 A and the bounded
transient point is 2.5 A. At 5 V/2.0 A plus a simultaneous 3.3 V/0.8 A load,
90% and 88% conversion efficiencies respectively, a 3.0 V cell supplies
approximately 4.33 A. The 2.5 A 5 V transient would reach 5.25 A and is limited
to converter/load transient duration; supported cells are rated at least 5 A
continuous with welded tabs and low-resistance wiring.

## Converter calculations

### TPS61088 main 5 V boost

R20=316 kΩ and R21=100 kΩ with the 1.204 V feedback reference produce
`1.204 × (1 + 316/100) = 5.008 V`. R51=330 kΩ selects approximately 1 MHz.
L3 is Coilcraft XAL6030-182MEC, 1.8 µH, 10 A-class shielded inductor. At
VIN=3.0 V, VOUT=5.008 V, IOUT=2.0 A and 90% efficiency, average input current
is 3.71 A, duty cycle is 40.1%, and ideal inductor ripple is about 0.67 A p-p;
the calculated peak is 4.05 A. This leaves more than 2:1 margin to the selected
inductor's saturation class and substantial margin to the programmed/device
switch limit. Six 22 µF/10 V output MLCCs are budgeted as at least 55 µF total
effective capacitance after 5 V DC bias. Capacitive ripple is about 15 mV p-p;
including ESR/layout/transient allowance, the release limit is 100 mV p-p.

### TPS63070 3.3 V logic buck-boost

R22=1.00 MΩ and R23=316 kΩ produce approximately 3.332 V. L2 is
SWPA4020S1R0MT, 1.0 µH. At 3.0 V input, 3.3 V/0.8 A output and 88% efficiency,
average input current is 1.00 A. At the approximately 2.4 MHz switching rate,
ideal ripple is 0.12 A p-p and peak inductor current is about 1.06 A, below the
device's 3.05 A minimum positive average-current limit and below the selected
inductor rating. Two 22 µF/10 V output capacitors are treated as 20 µF total
effective minimum; ripple plus load-step acceptance is 75 mV p-p.

### TPS62162 display 3.3 V buck

U10 is the fixed 3.3 V variant and uses L5 SWPA3015S2R2MT, 2.2 µH, with
22 µF output capacitance. From 5.0 V at the 2.25 MHz nominal frequency and
370 mA worst-case display load, ideal inductor ripple is about 0.10 A p-p and
peak current about 0.42 A. This is inside the 1 A converter rating and the
inductor margin. The display-domain limit is 50 mV p-p. FB2/FB3/FB4 isolate
AMT analog, AMT digital and panel return-current loops without splitting L2.

### TPS61165 backlight

The panel is two parallel strings of six LEDs. At the 19.6 V cold maximum and
40.08 mA set by `200 mV / 4.99 Ω`, LED output is 0.786 W. At 85% efficiency,
5 V input current is 185 mA. With 1.2 MHz, L4=10 µH and about 74.5% boost duty,
ideal input/inductor current is 0.185 A and ripple approximately 0.31 A p-p;
peak is about 0.34 A, well below the 1.2 A switch limit and selected inductor
saturation rating. D1 is B240A-13-F (40 V/2 A). Two 1 µF/50 V output MLCCs
provide DC-bias margin; permitted output ripple is 300 mV p-p. The 4.99 Ω,
1% resistor fixes normal current below the 42 mA production stop limit even at
100% PWM. CTRL is hardware pulled off during reset.

### BQ25895 power path and charging

R42=750 Ω sets an ILIM hardware ceiling near 2 A; firmware also applies the
negotiated/input register limit and never commands more than 1 A charge. The
device supports a 3.25 A programmable input limit, but Revision A budgets 2 A
at a 5 V USB source unless the factory fixture explicitly advertises more.
Charge current is reduced to 500 mA when display/video is active and to zero
when measured system demand, input droop or temperature would exceed the
budget. USB-only startup is therefore supported with ELRS hard-gated and
display/video optional. The charger exposed pad and recommended copper/vias
are mandatory; a calculated 0.8 W worst local dissipation at θJA=45 °C/W on
the implemented copper implies about 36 °C junction rise. Firmware begins
thermal reduction at 75 °C reported die temperature and disables charging at
90 °C or on NTC fault.

### Protection and physical switch

U3 is the fixed BQ29700DSER: 4.275 V overvoltage and 2.8 V undervoltage
thresholds, suitable for a 4.2 V Li-ion cell. Q1 is the dual FS8205A; the
back-to-back topology provides charge/discharge/short isolation. U20
TPS22992SRXNR disconnects all radio electronics while charger, protection and
gauge remain alive. C23=10 nF controls the rise; factory acceptance requires
no SYS_SWITCHED overshoot and peak inrush below 2.5 A. Off leakage at the
switched rails must keep each below 0.20 V.

## Thermal allocation

With recommended copper and thermal vias, pre-fabrication dissipation limits
are 0.8 W BQ25895, 0.75 W TPS61088, 0.35 W TPS63070, 0.20 W TPS62162, 0.15 W
TPS61165, 0.20 W Q1, and 0.10 W per load switch. At 40 °C ambient the predicted
worst junction values are respectively below 116, 95, 62, 53, 72, 70 and
55 °C using datasheet board-level θJA values and the implemented copper area.
The first-article stop limits are 110 °C IC case estimate, 85 °C PCB surface,
and 70 °C touch-accessible enclosure surface; exceeding one disables charging
and the affected load and requires an ECO, not a firmware-limit increase.

## Runtime model

The model reserves 15% of nameplate capacity for cutoff, ageing and gauge
uncertainty and uses 3.6 V nominal cell energy. Representative battery-input
powers are: simulator 1.0 W; video/50% backlight/10 mW ELRS 4.9 W;
video/100%/10 mW 5.5 W; video/100%/100 mW 6.2 W; scanning 5.8 W; Wi-Fi
maintenance with video off 2.0 W. Estimated 3000 mAh/new-cell runtimes are
9.2 h, 1.87 h, 1.67 h, 1.48 h, 1.58 h and 4.59 h respectively. Scale by
0.833/1.167 for 2500/3500 mAh; an 80%-health cell yields 80% of those values.
Cold-operation planning applies a further 20% reduction. These figures are
engineering estimates; the endurance mode records real rail states, voltage,
SOC, resets, deadline misses, brightness and RX channel for first-article
comparison.

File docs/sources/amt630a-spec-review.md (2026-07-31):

# AMT630A source review

- Filename: `AMT630A_Spec_V1.2.pdf`
- Internal document revision: Version 1.1, 2014-10
- SHA-256: `4647d609b51416862bd7e3913a625b21d66032c5ab3abe157a4e034b1ce215f7`
- Reviewed pages: all supplied pages (PDF pages 1–9)

The source PDF is not redistributed by this repository.

## Independently derived pin table

| Pin | Function | Pin | Function | Pin | Function | Pin | Function |
|---:|---|---:|---|---:|---|---:|---|
| 1 | CVBS1 | 17 | SPI_CS | 33 | G1 | 49 | B6 |
| 2 | CVBS2 | 18 | SPI_SI | 34 | G2 | 50 | B7 |
| 3 | CVBS3 | 19 | SPI_SO | 35 | G3 | 51 | DCLK |
| 4 | VCOM_ADC | 20 | SPI_CLK | 36 | G4 | 52 | DE |
| 5 | AVSS_ADC | 21 | DVDD 3.3 V | 37 | G5 | 53 | HSYNC |
| 6 | P0.3 / remote | 22 | internal 1.2 V regulator output | 38 | G6 | 54 | VSYNC |
| 7 | SAR2 | 23 | GND | 39 | G7 | 55 | PWM/diagnostic |
| 8 | SAR1 | 24 | R0 | 40 | DVDD 3.3 V | 56 | PWM/diagnostic |
| 9 | SAR0 | 25 | R1 | 41 | internal 1.2 V regulator output | 57 | UART/diagnostic |
| 10 | DVDD 3.3 V | 26 | R2 | 42 | GND | 58 | UART/diagnostic |
| 11 | internal 1.2 V regulator output | 27 | R3 | 43 | B0 | 59 | diagnostic |
| 12 | GND | 28 | R4 | 44 | B1 | 60 | SDA |
| 13 | AGND | 29 | R5 | 45 | B2 | 61 | SCL |
| 14 | XTAL_OUT | 30 | R6 | 46 | B3 | 62 | DVDD 3.3 V |
| 15 | XTAL_IN | 31 | R7 | 47 | B4 | 63 | RESET |
| 16 | AVDD 3.3 V | 32 | G0 | 48 | B5 | 64 | AVDD_ADC 3.3 V |

## Schematic conclusions

- Pins 11, 22, and 41 are decoupled internal core-regulator outputs. They are
  not driven by an external rail.
- Digital 3.3 V feeds pins 10, 21, 40, and 62. Filtered analog 3.3 V feeds
  pins 16 and 64. All returns use the continuous L2 ground plane; analog return
  current is controlled by placement and filtering rather than a split plane.
- CVBS1 is the normal AT7456E output input. CVBS2, CVBS3, and pins 6–9 are
  diagnostic-only and do not select an alternate production signal path.
- Pins 17–20 connect to the W25X05 through a default-to-AMT four-channel mux.
  AMT reset is asserted before the ESP32 may select the recovery side.
- Pins 24–54 connect directly to the panel RGB888/TCON interface. Pins 55–59
  terminate only at diagnostic pads. Pins 60–61 provide runtime status I2C.
- The 27 MHz crystal network is separately calculated from the selected
  crystal load capacitance; it is not copied from the AT7456E network.
- The supplied excerpt is authoritative for package pinout and electrical
  domains. Public register notes are separately cited in `registers.md`; no
  firmware dump or executable reverse-engineering tool is included.

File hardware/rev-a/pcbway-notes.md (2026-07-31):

# PCBWay quote and assembly notes

Classification: **OpenPocket Rev A — Engineering Prototype**.

- Fabrication: four copper layers, 1.0 mm finished thickness, 1 oz all layers,
  ENIG, controlled USB differential pair, impedance coupon/report requested.
- L2 is a continuous ground plane. Do not split or remove ground beneath USB,
  video, RGB clock, or converters except documented RF antenna keep-outs.
- No component substitutions without written approval. Manufacturer part
  numbers, not descriptive values, control procurement.
- Standard assembly includes every electronic component except TFT panel,
  ExpressLRS receiver, gimbals, buttons/switches, battery, antennas, and
  enclosure.
- MOD1 is consigned/manual assembly. PCBWay performs and documents the selected
  SPI-enable resistor removal before installation. Return one modified loose
  witness module and microscope photographs with the lot.
- Program U16 only from the released AMT630A image and verify the published
  SHA-256. Do not use a monitor-board factory dump.
- Default analog-video jumper is NORMAL. BYPASS remains open.
- Backlight is hardware default-off. All 5 V load-switch enables have physical
  pull-downs. AMT630A and AT7456E resets have deterministic boot states.
- Verify J1 pin 1 with the assembly drawing and inspected panel flex before
  population. Connector is bottom contact with direct flex insertion.
- X-ray or microscope inspect exposed pads, charger/converter QFNs, fine-pitch
  AMT630A, AT7456E EP, USB-C anchors, J1 contacts, and MOD1 shield/pads.
- Mark the PCB `OpenPocket Rev A` and `Engineering Prototype`; include the
  manufacturing release ID and source commit in copper or permanent silk.

Quote is not accepted until PCBWay confirms the exact module/IC sourcing,
consigned MOD1 operation, no-substitution list, panel-connector footprint,
stack-up, impedance, and programmed-flash procedure in writing.

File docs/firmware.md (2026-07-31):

# RivetTX firmware for OpenPocket

OpenPocket uses the `main` branch of
[Twotoz/RivetTX](https://github.com/Twotoz/RivetTX).

## Build

Install and activate ESP-IDF 5.5.2:

```bash
git clone https://github.com/Twotoz/RivetTX.git
cd RivetTX
idf.py set-target esp32s3
idf.py menuconfig
```

Open this menu:

```text
Component config
└── RivetTX hardware
    ├── Use OpenPocket AT7456E analog OSD instead of SSD1306 = enabled
    ├── AT7456E SPI clock GPIO
    ├── AT7456E SPI MOSI / SDIN GPIO
    ├── AT7456E SPI MISO / SDOUT GPIO
    ├── AT7456E active-low chip-select GPIO
    └── AT7456E active-low reset GPIO
```

Configure CRSF, gimbals, buttons, switches, encoder, trims, battery ADC, and
buzzer from the pin table for your board. The OSD pins intentionally have no
universal defaults.

```bash
idf.py build
idf.py flash monitor
```

## Expected behavior

- PAL uses all 30×16 character cells.
- Essential content stays within 30×13 for NTSC.
- Only changed cells are written to the AT7456E.
- Video loss and PAL/NTSC changes trigger a safe redraw.
- SPI and character-NVM work runs outside control, CRSF, and telemetry.
- SSD1306 and AT7456E presentation backends never start together.

The AMT630A snow-screen board is an autonomous composite-to-TFT stage. It does
not require an ESP32 driver in the first hardware revision. Its onboard OSD is
used only for display setup; RivetTX continues to render every OpenPocket menu
through the AT7456E.

## Firmware boundary

The AT7456E backend is implemented. The physical RX5808 target driver, exact
AMT630A board/panel pair, and final OpenPocket pin assignment remain open until
the selected modules and reference schematic have been reviewed.

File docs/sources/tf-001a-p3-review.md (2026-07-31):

# TF-001A-P3 source review

- Reviewed filename: `TF-001A-P3.pdf` (downloaded as the public LCSC
  `C3021282` datasheet; not redistributed here)
- Manufacturer: SOFNG Electronic Technology Co., Ltd.
- Product: TF-001A-P3 push-push microSD socket
- SHA-256: `4bbff766385a2d4da414b91257904be0da96f1dc7bc8d545a459b4039cbfa012`
- Internal drawing identification: `TF-001A-P3`, 8+1 card-detect,
  normally-open, consumer-electronics revision shown by the public two-page
  drawing
- Reviewed pages: 1–2

## Independently derived conclusions

- P1 DAT2, P2 DAT3, P3 CMD, P4 VDD, P5 CLK, P6 VSS, P7 DAT0, P8 DAT1.
- The ninth electrical pad is a normally-open mechanical card-detect switch;
  a fully inserted card connects it to the grounded shell contact.
- P1–P8 are on 0.80 mm pitch. The footprint includes P9 and all four shell/
  retention lands shown in the vertical-view PCB drawing.
- The maximum body envelope used for collision checking is 14.55 mm wide,
  15.80 mm deep and 1.9 mm high.
- Push-in, locked and pushed-out offsets are 0.51 mm, 1.35 mm and 4.47 mm,
  respectively; the ejected position therefore extends 3.12 mm beyond the
  locked position.
- Contact rating is 50 mA at 24 V DC; this is a signal-contact rating, not a
  statement of the microSD card's transient supply demand. Revision A budgets
  the `3V3_SD` power path separately for at least 300 mA.

The final fabrication gate requires a 1:1 overlay of the plotted footprint,
card outlines and shell pads against this drawing. That overlay has not yet
passed while the parent PCB remains unrouted and fails DRC.

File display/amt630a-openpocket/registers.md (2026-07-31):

# Register derivation

The immutable table in `src/registers.c` selects the 480×272 24-bit RGB+DE
output (`FC00=00`, `FD34..FD43=22`, `FD50=0F`), the documented 480×272 PLL
tuple (`FD0A=A8`, `FD0F=09`, `FD16=0A`), CVBS1, and separate PAL/NTSC scaler
timings. `FED7[7,6,1,0]` and `FEDC[7,6,4]` remain clear: those documented bits
disable snow or request a blue/background substitute.

The selected input sequence is the older-reference CVBS1 mapping:
`FED7[4:3]=0`, `FED8[7:6]=2`, `FEDC[5:4]=0`, then `FED7[4:3]=3`. A fixture
test must confirm that CVBS1 corresponds to physical pin 1 on the assembled
AMT630A; this is an execution check against an already frozen circuit, not an
unresolved architecture choice.

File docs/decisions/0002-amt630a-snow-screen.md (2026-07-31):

# ADR-0002: AMT630A snow-screen display controller

- Status: accepted
- Date: 2026-07-31

## Decision

OpenPocket uses an AMT630A composite-to-TFT controller board after the
AT7456E. The selected board must run a no-blue-screen, or “snow-screen,”
firmware variant and must be supplied with a verified matching TFT panel.

The video chain is:

```text
RX5808 VIDEO OUT -> AT7456E VIN/VOUT -> AMT630A CVBS IN -> matched TFT
```

## Rationale

- the AMT630A accepts composite PAL and NTSC and drives small parallel-RGB TFTs
- a snow-screen variant preserves weak analog information instead of masking
  it with a blue or black no-signal screen
- keeping the AT7456E in front of the display board preserves the existing
  RivetTX 30×16 compositor, custom glyphs, delta updates, and failure handling
- the ESP32-S3 does not need to capture, scale, buffer, or output video pixels

## Constraints

- “AMT630A” is a controller IC, not a complete board specification
- input voltage, CVBS connector, panel pinout, backlight circuit, and flash
  firmware must be verified for the exact PCB revision
- the board and panel are a matched set; a similar 40-pin FFC is not proof of
  electrical or timing compatibility
- the board must demonstrate PAL/NTSC lock, snow on signal loss, prompt video
  recovery, acceptable latency, and clean AT7456E character rendering
- OpenPocket does not control or replace the AMT630A firmware in the first
  hardware revision

## References

- [AMT630A product specification v1.1](https://www.8bcraft.com/wp-content/uploads/2019/06/AMT630A_Brief_Spec_v1.1.pdf)
- [RivetTX AT7456E hardware guide](https://github.com/Twotoz/RivetTX/blob/main/docs/hardware.md)

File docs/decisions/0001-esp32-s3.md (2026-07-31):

# ADR-0001: ESP32-S3 as the main controller

- Status: accepted
- Date: 2026-07-31

## Decision

OpenPocket uses the ESP32-S3 as its main controller. RivetTX continues to
support the C3 for smaller standalone transmitters, but the C3 is not the
target platform for OpenPocket hardware.

## Rationale

- more GPIO for four to eight analog axes, switches, trims, and an encoder
- independent lines for CRSF, RX5808, and AT7456E
- dual-core separation between the control task and UI/services
- native USB for simulator/HID work and maintenance
- headroom for future display, storage, and diagnostic tooling

## Consequences

- firmware is built with `idf.py set-target esp32s3`
- the PCB must respect flash/PSRAM, USB, and strapping restrictions for the
  chosen ESP32-S3 module
- no GPIO map becomes final before the schematic and exact module variant are
  reviewed

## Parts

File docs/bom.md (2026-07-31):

# Bill of materials

This BOM describes a **bench prototype**. Do not order a PCB batch or battery
pack from this list. Exact connectors, regulator ratings, and mechanical
dimensions must follow from the reviewed schematic and enclosure.

## Core components

| Quantity | Component | Minimum requirement | Status / note |
|---:|---|---|---|
| 1 | ESP32-S3 development board or module | enough exposed GPIO, native USB, and at least 8 MB flash recommended | MCU family fixed; exact board still open |
| 1 | RX5808 5.8 GHz receiver module | VIDEO OUT, RSSI, and programmable DATA/LE/CLK available | verify the exact PCB revision and pinout |
| 1 | AT7456E OSD module | 30×16 character OSD, SPI, VIDEO IN/OUT, 27 MHz clock, and video passives fitted | module recommended for the first prototype |
| 1 | AMT630A snow-screen controller board | CVBS input, PAL/NTSC autodetection, no blue-screen squelch, and firmware matched to the panel | fixed display-controller family; record the exact PCB revision |
| 1 | matched TFT panel | exact resolution, RGB format, FFC pinout, voltage, and timing required by the AMT630A board firmware | never assume two 40-pin panels are interchangeable |
| 1 | AMT630A key board or resistor-button network | access to brightness, contrast, aspect, and factory-safe display settings | optional after settings are validated |
| 1 | ExpressLRS TX module | full-duplex, non-inverted 3.3 V CRSF UART | a normal ELRS receiver is not sufficient |
| 2 | dual-axis gimbal | analog outputs compatible with conditioned ESP32 ADC inputs | four primary axes total |
| 1 | dedicated ARM switch | maintained, two-position | never share it with menu controls |
| 3 | AUX switches | two- or three-position | optional for the first bench test |
| 4 | menu buttons | UP, DOWN, ENTER, and BACK | active-low GPIO with pull-up |
| 1 | pressable rotary encoder | quadrature A/B plus switch contact | optional but recommended |
| 1 | suitable 5.8 GHz antenna | 50 Ω with the correct connector and polarization | never test with a damaged or open RF connector |

## Power and signal integrity

| Quantity | Component | Purpose |
|---:|---|---|
| 1 | current-limited 5 V bench supply, at least 2 A | first bring-up without a battery |
| 1 | 3.3 V regulator if absent from the S3 board | ESP32-S3 and 3.3 V logic |
| 1 | 74AHCT125 or equivalent 3.3 V-to-5 V buffer | SCLK, MOSI/SDIN, and CS into bare 5 V OSD logic |
| 1 | unidirectional 5 V-to-3.3 V buffer | AT7456E SDOUT/MISO into the ESP32-S3 |
| 1 | open-drain transistor stage | optional AT7456E RESET control |
| several | 100 nF ceramic capacitors | each digital and analog supply pin |
| several | 10–470 µF low-ESR bulk capacitors | local to OSD, AMT630A board, panel backlight, RX5808, and ELRS, sized from measured peak load |
| several | 22–100 Ω series resistors | optional digital edge damping after measurement |
| 1 | fuse or resettable PTC | prototype supply fault limiting |

A ready-made AT7456E module may already contain level shifting, the clock, and
video passives. Verify its schematic; do not trust the product title alone.

AMT630A controller boards are sold with different input regulators, panel
timings, connectors, and SPI-flash images. “AMT630A” alone does not identify a
safe power input or a compatible panel. Buy the board and TFT as a verified
pair, and confirm that its firmware shows snow rather than a blue or black
screen when composite sync disappears.

## Mechanical and later product work

- shielded or carefully routed composite-video cable
- strain-relieved connectors for gimbals, TFT panel, and RF module
- main switch and controlled power latch
- protected battery, charger, cell monitoring, and suitable fuse
- passive piezo or haptic warning device
- enclosure, controls, sticks, neck-strap point, and antenna mount
- KiCad PCB with deliberate RF, video, digital, and power return paths

Battery chemistry, charger, and power architecture are deliberately not fixed.
That choice requires a separate thermal, charging, and fault analysis.

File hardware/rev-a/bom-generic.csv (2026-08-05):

Designator | Value | Manufacturer | MPN | LCSC | Package | Qty | DNP | Notes
U1 | ESP32-S3-MINI-1U-N8 | Espressif | ESP32-S3-MINI-1U-N8 | C2980299 | ESP32-S3-MINI-1U | 1 | no
J2 | USB-C | GCT | USB4105-GF-A | C3020560 | USB4105-GF-A | 1 | no
ESD1 | USB ESD | Texas Instruments | TPD2EUSB30DRTR | C97502 | SOT-9X3-3 | 1 | no
F1 | USB VBUS resettable fuse | Littelfuse | 1206L200PR | C151163 | 1206 | 1 | no
TVS1 | USB VBUS TVS | onsemi | ESD5Z5.0T1G | C82044 | SOD-523 | 1 | no
U2 | 1S charger/power path | Texas Instruments | BQ25895RTWR | C80200 | WQFN-24-EP | 1 | no
U3 | 1S protector | Texas Instruments | BQ29700DSER | C183096 | WSON-6 | 1 | no
Q1 | dual protection FET | FUXINSEMI | FS8205A | C908265 | SOT-23-6 | 1 | no
U4 | fuel gauge | Analog Devices | MAX17048G+T10 | C2682616 | TDFN-8-EP | 1 | no
U20 | master load switch | Texas Instruments | TPS22992SRXNR | C3229354 | WQFN-8 | 1 | no
U5 | 3V3 buck-boost | Texas Instruments | TPS63070RNMR | C109322 | VQFN-15 | 1 | no
U6 | 5V boost | Texas Instruments | TPS61088RHLR | C87357 | VQFN-20-EP | 1 | no
U7 | 5V_VIDEO load switch | Texas Instruments | TPS22918DBVR | C131941 | SOT-23-6 | 1 | no
U8 | 5V_DISPLAY load switch | Texas Instruments | TPS22918DBVR | C131941 | SOT-23-6 | 1 | no
U9 | 5V_ELRS load switch | Texas Instruments | TPS22918DBVR | C131941 | SOT-23-6 | 1 | no
U10 | display 3V3 buck | Texas Instruments | TPS62162DSGR | C40256 | WSON-8-EP | 1 | no
MOD1 | RX5808 SPI receiver | WREKD | RX5808 SPI-modified | C2908157 | SMD-12_23.0X28.0X2.54P | 1 | no | pre-order or consigned
U11 | analog OSD | Zhongkewei | AT7456E | C82351 | TSSOP-28-EP | 1 | no
U12 | OSD 3V3-to-5V | Texas Instruments | SN74AHCT125PWR | C36365 | TSSOP-14 | 1 | no
U13 | OSD 5V-to-3V3 | Texas Instruments | SN74LVC1T45DCKR | C9382 | SC70-6 | 1 | no
U14 | CVBS TFT controller | Actions Microelectronics | AMT630A | C9900018923 | LQFP-64_14x14_P0.4 | 1 | no
U15 | AMT boot flash | Winbond | W25X05CLSNIG | C2641187 | SOIC-8 | 1 | no
U16 | AMT flash mux | Texas Instruments | SN74CB3Q3257PWR | C397142 | TSSOP-16 | 1 | no
J1 | ER-TFT050A3-2 FFC | Hirose | FH12-40S-0.5SH(55) | C202114 | FH12-40S-0.5SH(55) | 1 | no
U17 | backlight boost | Texas Instruments | TPS61165DRVR | C122568 | WSON-6-EP | 1 | no
U18 | GPIO expander 0x20 | Texas Instruments | TCA9535PWR | C130204 | TSSOP-24 | 1 | no
U19 | GPIO expander 0x21 | Texas Instruments | TCA9535PWR | C130204 | TSSOP-24 | 1 | no
BZ1 | passive magnetic buzzer | Fengming | YS-SBZ7525C05R30 | C7421675 | SMD-7.5x7.5 | 1 | no
Q2 | Q_BUZZ buzzer MOSFET | Alpha & Omega | AO3400A | C20917 | SOT-23 | 1 | no
D2 | D_BUZZ buzzer flyback | LGE | 1N4148W | C81598 | SOD-123 | 1 | no
U21 | I2S speaker amplifier | Nsiway | NS4168 | C910588 | ESOP-8-EP | 1 | no
J4 | speaker connector | JST | S2B-PH-SM4-TB(LF)(SN) | C295747 | JST-PH-2-SMD | 1 | no
J13 | speaker solder pads | OpenPocket | SOLDER-PADS-2 | CONS | EDGE-PADS-2 | 1 | yes | integral differential speaker pads; neither pad is ground
U22 | 3V3_SD load switch | Texas Instruments | TPS22918DBVR | C131941 | SOT-23-6 | 1 | no
J12 | push-push microSD | SOFNG | TF-001A-P3 | C3021282 | TF-001A-P3 | 1 | no | card detect active-low; card ejects toward top edge
ESD2 | microSD ESD array A | Texas Instruments | TPD4E001DRLR | C527516 | SOT-563 | 1 | no
ESD3 | microSD ESD array B | Texas Instruments | TPD4E001DRLR | C527516 | SOT-563 | 1 | no
TP1 | 3V3_SD test pad | OpenPocket | PCB-TEST-PAD-1.0MM | N/A | TEST-PAD-1.0MM | 1 | yes | bare ENIG copper test feature; not an assembled component
TP2 | SD_CLK test pad | OpenPocket | PCB-TEST-PAD-1.0MM | N/A | TEST-PAD-1.0MM | 1 | yes | bare ENIG copper test feature; not an assembled component
TP3 | SD_CMD test pad | OpenPocket | PCB-TEST-PAD-1.0MM | N/A | TEST-PAD-1.0MM | 1 | yes | bare ENIG copper test feature; not an assembled component
TP4 | SD_D0 test pad | OpenPocket | PCB-TEST-PAD-1.0MM | N/A | TEST-PAD-1.0MM | 1 | yes | bare ENIG copper test feature; not an assembled component
TP5 | SD_CARD_DETECT test pad | OpenPocket | PCB-TEST-PAD-1.0MM | N/A | TEST-PAD-1.0MM | 1 | yes | bare ENIG copper test feature; not an assembled component
TP6 | GND test pad | OpenPocket | PCB-TEST-PAD-1.0MM | N/A | TEST-PAD-1.0MM | 1 | yes | bare ENIG copper test feature; not an assembled component
J3 | battery/NTC | OpenPocket | SOLDER-PADS-4 | CONS | EDGE-PADS-4 | 1 | yes | integral solder pads; user-wired, not an assembly item
J5 | master switch | OpenPocket | SOLDER-PADS-2 | CONS | EDGE-PADS-2 | 1 | yes | integral solder pads; user-wired, not an assembly item
J6 | ELRS | OpenPocket | SOLDER-PADS-6 | CONS | EDGE-PADS-6 | 1 | yes | integral solder pads; user-wired, not an assembly item
ESD4 | ELRS UART ESD | Texas Instruments | TPD2EUSB30DRTR | C97502 | SOT-9X3-3 | 1 | no
J7 | left gimbal | OpenPocket | SOLDER-PADS-4 | CONS | EDGE-PADS-4 | 1 | yes | integral solder pads; user-wired, not an assembly item
J8 | right gimbal | OpenPocket | SOLDER-PADS-4 | CONS | EDGE-PADS-4 | 1 | yes | integral solder pads; user-wired, not an assembly item
J9 | controls | OpenPocket | SOLDER-PADS-22 | CONS | EDGE-PADS-22 | 1 | yes | integral solder pads; user-wired, not an assembly item
J11 | 5.8 GHz antenna U.FL | Hirose | U.FL-R-SMT-1(10) | C88373 | U.FL | 1 | no | populate on bottom; accepts U.FL/MHF1 plug vertically; secure cable to enclosure
R1 | 5.1k | Yageo | RC0402FR-075K1L | C105872 | 0402 | 1 | no
R2 | 5.1k | Yageo | RC0402FR-075K1L | C105872 | 0402 | 1 | no
R3 | 10k | Yageo | RC0402FR-0710KL | C60490 | 0402 | 1 | no
R4 | 10k | Yageo | RC0402FR-0710KL | C60490 | 0402 | 1 | no
R5 | 100k | Yageo | RC0402FR-07100KL | C60491 | 0402 | 1 | no
R6 | 100 | Yageo | RC0402FR-07100RL | C106232 | 0402 | 1 | no
R7 | 100k | Yageo | RC0402FR-07100KL | C60491 | 0402 | 1 | no
R8 | 100k | Yageo | RC0402FR-07100KL | C60491 | 0402 | 1 | no
R9 | 4.99 | Yageo | RC0603FR-074R99L | C137704 | 0402 | 1 | no
R10 | 18 | Yageo | RC0603FR-0718RL | C245924 | 0402 | 1 | no
R11 | 56 | Yageo | RC0603FR-0756RL | C126360 | 0402 | 1 | no
R12 | 100k | Yageo | RC0402FR-07100KL | C60491 | 0402 | 1 | no
R13 | 100k | Yageo | RC0402FR-07100KL | C60491 | 0402 | 1 | no
R14 | 2.2k | Yageo | RC0402FR-072K2L | C114762 | 0402 | 1 | no
R15 | 2.2k | Yageo | RC0402FR-072K2L | C114762 | 0402 | 1 | no
R16 | 100k | Yageo | RC0402FR-07100KL | C60491 | 0402 | 1 | no
R18 | 1M | Yageo | RC0402FR-071ML | C138033 | 0402 | 1 | no
R20 | 316k | Yageo | RC0402FR-07316KL | C185427 | 0402 | 1 | no
R21 | 100k | Yageo | RC0402FR-07100KL | C60491 | 0402 | 1 | no
R22 | 1M | Yageo | RC0402FR-071ML | C138033 | 0402 | 1 | no
R23 | 316k | Yageo | RC0402FR-07316KL | C185427 | 0402 | 1 | no
R24 | 150k | Yageo | RC0402FR-07150KL | C93947 | 0402 | 1 | no
R25 | 1k | Yageo | RC0402FR-071KL | C106235 | 0402 | 1 | no
R26 | 12k | Yageo | RC0402FR-0712KL | C114760 | 0402 | 1 | no
R27 | 18k | Yageo | RC0402FR-0718KL | C138044 | 0402 | 1 | no
R28 | 27 | Yageo | RC0402FR-0727RL | C138021 | 0402 | 1 | no
R29 | 27 | Yageo | RC0402FR-0727RL | C138021 | 0402 | 1 | no
R30 | 10k | Yageo | RC0402FR-0710KL | C60490 | 0402 | 1 | no
R31 | 10k | Yageo | RC0402FR-0710KL | C60490 | 0402 | 1 | no
R32 | 10k | Yageo | RC0402FR-0710KL | C60490 | 0402 | 1 | no
R33 | 10k | Yageo | RC0402FR-0710KL | C60490 | 0402 | 1 | no
R34 | 10k | Yageo | RC0402FR-0710KL | C60490 | 0402 | 1 | no
R35 | 10k | Yageo | RC0402FR-0710KL | C60490 | 0402 | 1 | no
R36 | 100k | Yageo | RC0402FR-07100KL | C60491 | 0402 | 1 | no
R37 | 27 | Yageo | RC0402FR-0727RL | C138021 | 0402 | 1 | no
R38 | 27 | Yageo | RC0402FR-0727RL | C138021 | 0402 | 1 | no
R39 | 27 | Yageo | RC0402FR-0727RL | C138021 | 0402 | 1 | no
R40 | 100k | Yageo | RC0402FR-07100KL | C60491 | 0402 | 1 | no
R41 | 100k | Yageo | RC0402FR-07100KL | C60491 | 0402 | 1 | no
R42 | 750 | Yageo | RC0402FR-07750RL | C137936 | 0402 | 1 | no
R43 | 10k | Yageo | RC0402FR-0710KL | C60490 | 0402 | 1 | no
R44 | 10k | Yageo | RC0402FR-0710KL | C60490 | 0402 | 1 | no
R45 | 10k | Yageo | RC0402FR-0710KL | C60490 | 0402 | 1 | no
R46 | 5.23k | Yageo | RC0402FR-075K23L | C477746 | 0402 | 1 | no
R47 | 30.1k | Yageo | RC0402FR-0730K1L | C138009 | 0402 | 1 | no
R48 | 10k | Yageo | RC0402FR-0710KL | C60490 | 0402 | 1 | no
R49 | 10k | Yageo | RC0402FR-0710KL | C60490 | 0402 | 1 | no
R50 | 10k | Yageo | RC0402FR-0710KL | C60490 | 0402 | 1 | no
R51 | 330k | Yageo | RC0402FR-07330KL | C138006 | 0402 | 1 | no
R52 | 18.2k | Yageo | RC0402FR-0718K2L | C274351 | 0402 | 1 | no
R53 | 1k | Yageo | RC0402FR-071KL | C106235 | 0402 | 1 | no
R54 | 1M | Yageo | RC0402FR-071ML | C138033 | 0402 | 1 | no
R55 | 10 | Yageo | RC0402FR-0710RL | C138066 | 0402 | 1 | no
R56 | 330 | Uniroyal Electronics | 0402WGF3300TCE | C25104 | 0402 | 1 | no
R57 | 2.2k | Uniroyal Electronics | 0402WGF2201TCE | C25879 | 0402 | 1 | no
R58 | 33 | Yageo | RC0402FR-0733RL | C138002 | 0402 | 1 | no
R59 | 33 | Yageo | RC0402FR-0733RL | C138002 | 0402 | 1 | no
R60 | 33 | Yageo | RC0402FR-0733RL | C138002 | 0402 | 1 | no
R61 | 33 | Yageo | RC0402FR-0733RL | C138002 | 0402 | 1 | no
R62 | 5.1M | Uniroyal Electronics | 0402WGF5104TCE | C270595 | 0402 | 1 | no
R63 | 5.1M | Uniroyal Electronics | 0402WGF5104TCE | C270595 | 0402 | 1 | no
R64 | 1k | Yageo | RC0402FR-071KL | C106235 | 0402 | 1 | no
R65 | 1k | Yageo | RC0402FR-071KL | C106235 | 0402 | 1 | no
R66 | 100k | Yageo | RC0402FR-07100KL | C60491 | 0402 | 1 | no
R67 | 100k | Yageo | RC0402FR-07100KL | C60491 | 0402 | 1 | no
R68 | 100k | Yageo | RC0402FR-07100KL | C60491 | 0402 | 1 | no
R69 | 100k | Yageo | RC0402FR-07100KL | C60491 | 0402 | 1 | no
R70 | 10k | Yageo | RC0402FR-0710KL | C60490 | 0402 | 1 | no
R71 | 10k | Yageo | RC0402FR-0710KL | C60490 | 0402 | 1 | no
R72 | 10k | Yageo | RC0402FR-0710KL | C60490 | 0402 | 1 | no
R73 | 10k | Yageo | RC0402FR-0710KL | C60490 | 0402 | 1 | no
R74 | 10k | Yageo | RC0402FR-0710KL | C60490 | 0402 | 1 | no
R75 | 10k | Yageo | RC0402FR-0710KL | C60490 | 0402 | 1 | no
R76 | 10k | Yageo | RC0402FR-0710KL | C60490 | 0402 | 1 | no
R77 | 10k | Yageo | RC0402FR-0710KL | C60490 | 0402 | 1 | no
R78 | 10k | Yageo | RC0402FR-0710KL | C60490 | 0402 | 1 | no
R79 | 10k | Yageo | RC0402FR-0710KL | C60490 | 0402 | 1 | no
R80 | 10k | Yageo | RC0402FR-0710KL | C60490 | 0402 | 1 | no
R81 | 10k | Yageo | RC0402FR-0710KL | C60490 | 0402 | 1 | no
R82 | 10k | Yageo | RC0402FR-0710KL | C60490 | 0402 | 1 | no
R83 | 10k | Yageo | RC0402FR-0710KL | C60490 | 0402 | 1 | no
R84 | 10k | Yageo | RC0402FR-0710KL | C60490 | 0402 | 1 | no
R85 | 10k | Yageo | RC0402FR-0710KL | C60490 | 0402 | 1 | no
R86 | 10k | Yageo | RC0402FR-0710KL | C60490 | 0402 | 1 | no
R87 | 10k | Yageo | RC0402FR-0710KL | C60490 | 0402 | 1 | no
R88 | 10k | Yageo | RC0402FR-0710KL | C60490 | 0402 | 1 | no
R89 | 10k | Yageo | RC0402FR-0710KL | C60490 | 0402 | 1 | no
R90 | 10k | Yageo | RC0402FR-0710KL | C60490 | 0402 | 1 | no
R91 | 10k | Yageo | RC0402FR-0710KL | C60490 | 0402 | 1 | no
R92 | 10k | Yageo | RC0402FR-0710KL | C60490 | 0402 | 1 | no
R93 | 10k | Yageo | RC0402FR-0710KL | C60490 | 0402 | 1 | no
R94 | 10k | Yageo | RC0402FR-0710KL | C60490 | 0402 | 1 | no
R95 | 1k | Yageo | RC0402FR-071KL | C106235 | 0402 | 1 | no
R96 | 1k | Yageo | RC0402FR-071KL | C106235 | 0402 | 1 | no
R97 | 1k | Yageo | RC0402FR-071KL | C106235 | 0402 | 1 | no
R98 | 1k | Yageo | RC0402FR-071KL | C106235 | 0402 | 1 | no
R99 | 33 | Yageo | RC0402FR-0733RL | C138002 | 0402 | 1 | no
R100 | 33 | Yageo | RC0402FR-0733RL | C138002 | 0402 | 1 | no
R101 | 0 | Yageo | RC0402FR-070RL | C106231 | 0402 | 1 | no
R102 | 100 | Yageo | RC0402FR-07100RL | C106232 | 0402 | 1 | yes
R103 | 75 | Yageo | RC0603FR-0775RL | C112309 | 0603 | 1 | no
R104 | 10k | Yageo | RC0402FR-0710KL | C60490 | 0402 | 1 | no
C1 | 100n | Samsung Electro-Mechanics | CL05B104KO5NNNC | C1525 | 0402 | 1 | no
C2 | 10u | Samsung Electro-Mechanics | CL21A106KAYNNNE | C15850 | 0805 | 1 | no
C3 | 10u | Samsung Electro-Mechanics | CL21A106KAYNNNE | C15850 | 0805 | 1 | no
C4 | 100n | Samsung Electro-Mechanics | CL05B104KO5NNNC | C1525 | 0402 | 1 | no
C5 | 10u | Samsung Electro-Mechanics | CL21A106KAYNNNE | C15850 | 0805 | 1 | no
C6 | 470u | Lelon | VZH471M1ATR-1008 | C249929 | SMD-D10 | 1 | no
C7 | 100n | Samsung Electro-Mechanics | CL05B104KO5NNNC | C1525 | 0402 | 1 | no
C8 | 22n | Samsung Electro-Mechanics | CL05B223KB5NNNC | C337699 | 0402 | 1 | no
C9 | 100n | Samsung Electro-Mechanics | CL05B104KO5NNNC | C1525 | 0402 | 1 | no
C10 | 4.7u | Samsung Electro-Mechanics | CL10A475KP8NNNC | C1705 | 0603 | 1 | no
C11 | 4.7u | Samsung Electro-Mechanics | CL10A475KP8NNNC | C1705 | 0603 | 1 | no
C12 | 4.7u | Samsung Electro-Mechanics | CL10A475KP8NNNC | C1705 | 0603 | 1 | no
C15 | 33p C0G | Yageo | CC0402JRNPO9BN330 | C107005 | 0402 | 1 | no
C16 | 33p C0G | Yageo | CC0402JRNPO9BN330 | C107005 | 0402 | 1 | no
C17 | 100n | Samsung Electro-Mechanics | CL05B104KO5NNNC | C1525 | 0402 | 1 | no
C18 | 10u | Samsung Electro-Mechanics | CL21A106KAYNNNE | C15850 | 0805 | 1 | no
C19 | 10u | Samsung Electro-Mechanics | CL21A106KAYNNNE | C15850 | 0805 | 1 | no
C20 | 100n | Samsung Electro-Mechanics | CL05B104KO5NNNC | C1525 | 0402 | 1 | no
C21 | 10u | Samsung Electro-Mechanics | CL21A106KAYNNNE | C15850 | 0805 | 1 | no
C22 | 100n | Samsung Electro-Mechanics | CL05B104KO5NNNC | C1525 | 0402 | 1 | no
C23 | 10n | Samsung Electro-Mechanics | CL05B103KB5NNNC | C15195 | 0402 | 1 | no
C24 | 100n | Samsung Electro-Mechanics | CL05B104KO5NNNC | C1525 | 0402 | 1 | no
C25 | 10u | Samsung Electro-Mechanics | CL21A106KAYNNNE | C15850 | 0805 | 1 | no
C26 | 47u | Samsung Electro-Mechanics | CL31A476MPHNNNE | C96123 | 1206 | 1 | no
C27 | 1n | Samsung Electro-Mechanics | CL05B102KB5NNNC | C14442 | 0402 | 1 | no
C28 | 10u 25V | HRE | CGA0805X7R106K250MT | C6119932 | 0805 | 1 | no
C29 | 4.7u 10V | Fenghua Advanced | 0603B475K100NT | C108342 | 0603 | 1 | no
C30 | 47n 50V | Yageo | CC0402KRX7R9BB473 | C272875 | 0402 | 1 | no
C31 | 10u 25V | HRE | CGA0805X7R106K250MT | C6119932 | 0805 | 1 | no
C32 | 22u 10V | HRE | CGA0805X7R226M100MT | C23692981 | 0805 | 1 | no
C33 | 22u 10V | HRE | CGA0805X7R226M100MT | C23692981 | 0805 | 1 | no
C34 | 10u 25V | HRE | CGA0805X7R106K250MT | C6119932 | 0805 | 1 | no
C35 | 100n | Samsung Electro-Mechanics | CL05B104KO5NNNC | C1525 | 0402 | 1 | no
C36 | 10u | Samsung Electro-Mechanics | CL21A106KAYNNNE | C15850 | 0805 | 1 | no
C37 | 10u | Samsung Electro-Mechanics | CL21A106KAYNNNE | C15850 | 0805 | 1 | no
C38 | 22u 10V | HRE | CGA0805X7R226M100MT | C23692981 | 0805 | 1 | no
C39 | 22u 10V | HRE | CGA0805X7R226M100MT | C23692981 | 0805 | 1 | no
C40 | 2.2u | Samsung Electro-Mechanics | CL10A225KO8NNNC | C23630 | 0603 | 1 | no
C41 | 100n | Samsung Electro-Mechanics | CL05B104KO5NNNC | C1525 | 0402 | 1 | no
C42 | 47n 50V | Yageo | CC0402KRX7R9BB473 | C272875 | 0402 | 1 | no
C43 | 4.7n | Samsung Electro-Mechanics | CL05B472KB5NNNC | C84705 | 0402 | 1 | no
C44 | 2.2n | Samsung Electro-Mechanics | CL05B222KB5NNNC | C84703 | 0402 | 1 | no
C45 | 22u 10V | HRE | CGA0805X7R226M100MT | C23692981 | 0805 | 1 | no
C46 | 22u 10V | HRE | CGA0805X7R226M100MT | C23692981 | 0805 | 1 | no
C47 | 22u 10V | HRE | CGA0805X7R226M100MT | C23692981 | 0805 | 1 | no
C48 | 22u 10V | HRE | CGA0805X7R226M100MT | C23692981 | 0805 | 1 | no
C49 | 22u 10V | HRE | CGA0805X7R226M100MT | C23692981 | 0805 | 1 | no
C50 | 22u 10V | HRE | CGA0805X7R226M100MT | C23692981 | 0805 | 1 | no
C51 | 10u | Samsung Electro-Mechanics | CL21A106KAYNNNE | C15850 | 0805 | 1 | no
C52 | 22u 10V | HRE | CGA0805X7R226M100MT | C23692981 | 0805 | 1 | no
C53 | 4.7u 10V | Fenghua Advanced | 0603B475K100NT | C108342 | 0603 | 1 | no
C54 | 220n | Yageo | CC0402KRX7R8BB224 | C723566 | 0402 | 1 | no
C55 | 1u 50V | Yageo | CC0805KKX7R9BB105 | C91185 | 0805 | 1 | no
C56 | 1u 50V | Yageo | CC0805KKX7R9BB105 | C91185 | 0805 | 1 | no
C57 | 100n | Samsung Electro-Mechanics | CL05B104KO5NNNC | C1525 | 0402 | 1 | no
C58 | 100n | Samsung Electro-Mechanics | CL05B104KO5NNNC | C1525 | 0402 | 1 | no
C59 | 100n | Samsung Electro-Mechanics | CL05B104KO5NNNC | C1525 | 0402 | 1 | no
C60 | 10u | Samsung Electro-Mechanics | CL21A106KAYNNNE | C15850 | 0805 | 1 | no
C61 | 470n 16V | HRE | CGA0402X7R474K160GT | C22435970 | 0402 | 1 | no
C62 | 100n | Samsung Electro-Mechanics | CL05B104KO5NNNC | C1525 | 0402 | 1 | no
C63 | 4.7n | Samsung Electro-Mechanics | CL05B472KB5NNNC | C84705 | 0402 | 1 | no
C64 | 1n | Samsung Electro-Mechanics | CL05B102KB5NNNC | C14442 | 0402 | 1 | no
C65 | 1n | Samsung Electro-Mechanics | CL05B102KB5NNNC | C14442 | 0402 | 1 | no
C66 | 1n | Samsung Electro-Mechanics | CL05B102KB5NNNC | C14442 | 0402 | 1 | no
C67 | 100n | Samsung Electro-Mechanics | CL05B104KO5NNNC | C1525 | 0402 | 1 | no
C68 | 1u | Samsung Electro-Mechanics | CL05A105KA5NQNC | C52923 | 0402 | 1 | no
C69 | 100n | Samsung Electro-Mechanics | CL05B104KO5NNNC | C1525 | 0402 | 1 | no
C70 | 100n | Samsung Electro-Mechanics | CL05B104KO5NNNC | C1525 | 0402 | 1 | no
C71 | 100n | Samsung Electro-Mechanics | CL05B104KO5NNNC | C1525 | 0402 | 1 | no
C72 | 100n | Samsung Electro-Mechanics | CL05B104KO5NNNC | C1525 | 0402 | 1 | no
C73 | 100n | Samsung Electro-Mechanics | CL05B104KO5NNNC | C1525 | 0402 | 1 | no
C74 | 100n | Samsung Electro-Mechanics | CL05B104KO5NNNC | C1525 | 0402 | 1 | no
C75 | 10u | Samsung Electro-Mechanics | CL21A106KAYNNNE | C15850 | 0805 | 1 | no
C77 | 100n | Samsung Electro-Mechanics | CL05B104KO5NNNC | C1525 | 0402 | 1 | no
C78 | 100n | Samsung Electro-Mechanics | CL05B104KO5NNNC | C1525 | 0402 | 1 | no
C79 | 100n | Samsung Electro-Mechanics | CL05B104KO5NNNC | C1525 | 0402 | 1 | no
C80 | 100n | Samsung Electro-Mechanics | CL05B104KO5NNNC | C1525 | 0402 | 1 | no
C81 | 100n | Samsung Electro-Mechanics | CL05B104KO5NNNC | C1525 | 0402 | 1 | no
C82 | 100n | Samsung Electro-Mechanics | CL05B104KO5NNNC | C1525 | 0402 | 1 | no
C76 | 220u 10V | Panasonic | EEEFK1A221P | C401648 | SMD-D8 | 1 | yes
C83 | 10n | Samsung Electro-Mechanics | CL05B103KB5NNNC | C15195 | 0402 | 1 | yes
Y1 | 27.000MHz | Abracon | ABM8-27.000MHZ-B2-T | C1985251 | ABM8 | 1 | no
Y2 | 27.000MHz | Abracon | ABM8-27.000MHZ-B2-T | C1985251 | ABM8 | 1 | no
L1 | 2.2uH charger | Sunlord | SWPA4030S2R2MT | C36409 | L-4x4 | 1 | no
L2 | 1uH 3V3 | Sunlord | SWPA4020S1R0MT | C142484 | L-4x4 | 1 | no
L3 | 1.8uH 5V 10A | Coilcraft | XAL6030-182MEC | C19191693 | L-6.5x6.3 | 1 | no
L4 | 10uH backlight | Sunlord | SWPA4020S100MT | C82398 | L-4x4 | 1 | no
L5 | 2.2uH display buck | Sunlord | SWPA3015S2R2MT | C43389 | L-3x3 | 1 | no
D1 | 40V Schottky | Diodes Inc | B240A-13-F | C92506 | SMA | 1 | no
FB1 | video ferrite | Murata | BLM21PG221SN1D | C85840 | 0805 | 1 | no
FB2 | AMT analog ferrite | Murata | BLM18AG601SN1D | C19330 | 0603 | 1 | no
FB3 | AMT digital ferrite | Murata | BLM18AG601SN1D | C19330 | 0603 | 1 | no
FB4 | panel logic ferrite | Murata | BLM18AG601SN1D | C19330 | 0603 | 1 | no
JP1 | CVBS NORMAL/BYPASS | OpenPocket | SJ-DPDT | N/A | SOLDER-JUMPER-6 | 1 | yes | factory hand-bridge pads 1-2 and 4-5; bypass cuts both and bridges 5-6
TP7 | TP_CVBS2 test pad | OpenPocket | PCB-TEST-PAD-1.0MM | N/A | TEST-PAD-1.0MM | 1 | yes | bare ENIG copper test feature; not an assembled component
TP8 | TP_CVBS3 test pad | OpenPocket | PCB-TEST-PAD-1.0MM | N/A | TEST-PAD-1.0MM | 1 | yes | bare ENIG copper test feature; not an assembled component
TP9 | TP_AMT_P6 test pad | OpenPocket | PCB-TEST-PAD-1.0MM | N/A | TEST-PAD-1.0MM | 1 | yes | bare ENIG copper test feature; not an assembled component
TP10 | TP_AMT_P7 test pad | OpenPocket | PCB-TEST-PAD-1.0MM | N/A | TEST-PAD-1.0MM | 1 | yes | bare ENIG copper test feature; not an assembled component
TP11 | TP_AMT_P8 test pad | OpenPocket | PCB-TEST-PAD-1.0MM | N/A | TEST-PAD-1.0MM | 1 | yes | bare ENIG copper test feature; not an assembled component
TP12 | TP_AMT_P9 test pad | OpenPocket | PCB-TEST-PAD-1.0MM | N/A | TEST-PAD-1.0MM | 1 | yes | bare ENIG copper test feature; not an assembled component
TP13 | TP_AMT_DIAG test pad | OpenPocket | PCB-TEST-PAD-1.0MM | N/A | TEST-PAD-1.0MM | 1 | yes | bare ENIG copper test feature; not an assembled component
TP14 | TP_AMT_UART1 test pad | OpenPocket | PCB-TEST-PAD-1.0MM | N/A | TEST-PAD-1.0MM | 1 | yes | bare ENIG copper test feature; not an assembled component
TP15 | TP_AMT_UART0 test pad | OpenPocket | PCB-TEST-PAD-1.0MM | N/A | TEST-PAD-1.0MM | 1 | yes | bare ENIG copper test feature; not an assembled component
TP16 | TP_AMT_PWM1 test pad | OpenPocket | PCB-TEST-PAD-1.0MM | N/A | TEST-PAD-1.0MM | 1 | yes | bare ENIG copper test feature; not an assembled component
TP17 | TP_AMT_PWM0 test pad | OpenPocket | PCB-TEST-PAD-1.0MM | N/A | TEST-PAD-1.0MM | 1 | yes | bare ENIG copper test feature; not an assembled component
TP18 | RX_AUDIO_TP test pad | OpenPocket | PCB-TEST-PAD-1.0MM | N/A | TEST-PAD-1.0MM | 1 | yes | bare ENIG copper test feature; not an assembled component
TP19 | TP_OSD_CLK test pad | OpenPocket | PCB-TEST-PAD-1.0MM | N/A | TEST-PAD-1.0MM | 1 | yes | bare ENIG copper test feature; not an assembled component
TP20 | TP_OSD_HSYNC test pad | OpenPocket | PCB-TEST-PAD-1.0MM | N/A | TEST-PAD-1.0MM | 1 | yes | bare ENIG copper test feature; not an assembled component
TP21 | TP_OSD_VSYNC test pad | OpenPocket | PCB-TEST-PAD-1.0MM | N/A | TEST-PAD-1.0MM | 1 | yes | bare ENIG copper test feature; not an assembled component
TP22 | ELRS_BOOT test pad | OpenPocket | PCB-TEST-PAD-1.0MM | N/A | TEST-PAD-1.0MM | 1 | yes | bare ENIG copper test feature; not an assembled component
TP23 | ELRS_RESET test pad | OpenPocket | PCB-TEST-PAD-1.0MM | N/A | TEST-PAD-1.0MM | 1 | yes | bare ENIG copper test feature; not an assembled component
TP24 | SYS_ALWAYS test pad | OpenPocket | PCB-TEST-PAD-1.0MM | N/A | TEST-PAD-1.0MM | 1 | yes | bare ENIG copper test feature; not an assembled component
TP25 | SYS_SWITCHED test pad | OpenPocket | PCB-TEST-PAD-1.0MM | N/A | TEST-PAD-1.0MM | 1 | yes | bare ENIG copper test feature; not an assembled component
TP26 | POWER_GOOD test pad | OpenPocket | PCB-TEST-PAD-1.0MM | N/A | TEST-PAD-1.0MM | 1 | yes | bare ENIG copper test feature; not an assembled component
TP27 | 3V3_LOGIC test pad | OpenPocket | PCB-TEST-PAD-1.0MM | N/A | TEST-PAD-1.0MM | 1 | yes | bare ENIG copper test feature; not an assembled component
TP28 | SYS_SWITCHED_5V test pad | OpenPocket | PCB-TEST-PAD-1.0MM | N/A | TEST-PAD-1.0MM | 1 | yes | bare ENIG copper test feature; not an assembled component
TP29 | 5V_VIDEO test pad | OpenPocket | PCB-TEST-PAD-1.0MM | N/A | TEST-PAD-1.0MM | 1 | yes | bare ENIG copper test feature; not an assembled component
TP30 | 5V_DISPLAY test pad | OpenPocket | PCB-TEST-PAD-1.0MM | N/A | TEST-PAD-1.0MM | 1 | yes | bare ENIG copper test feature; not an assembled component
TP31 | 5V_ELRS test pad | OpenPocket | PCB-TEST-PAD-1.0MM | N/A | TEST-PAD-1.0MM | 1 | yes | bare ENIG copper test feature; not an assembled component
TP32 | DISPLAY_3V3 test pad | OpenPocket | PCB-TEST-PAD-1.0MM | N/A | TEST-PAD-1.0MM | 1 | yes | bare ENIG copper test feature; not an assembled component
TP33 | PANEL_3V3 test pad | OpenPocket | PCB-TEST-PAD-1.0MM | N/A | TEST-PAD-1.0MM | 1 | yes | bare ENIG copper test feature; not an assembled component
TP34 | VBUS_USB test pad | OpenPocket | PCB-TEST-PAD-1.0MM | N/A | TEST-PAD-1.0MM | 1 | yes | bare ENIG copper test feature; not an assembled component
TP35 | BAT_RAW test pad | OpenPocket | PCB-TEST-PAD-1.0MM | N/A | TEST-PAD-1.0MM | 1 | yes | bare ENIG copper test feature; not an assembled component
TP36 | RX_RSSI_RAW test pad | OpenPocket | PCB-TEST-PAD-1.0MM | N/A | TEST-PAD-1.0MM | 1 | yes | bare ENIG copper test feature; not an assembled component
TP37 | VRX_VIDEO_RAW test pad | OpenPocket | PCB-TEST-PAD-1.0MM | N/A | TEST-PAD-1.0MM | 1 | yes | bare ENIG copper test feature; not an assembled component
TP38 | OSD_VIDEO_RAW test pad | OpenPocket | PCB-TEST-PAD-1.0MM | N/A | TEST-PAD-1.0MM | 1 | yes | bare ENIG copper test feature; not an assembled component
TP39 | AMT_RESET test pad | OpenPocket | PCB-TEST-PAD-1.0MM | N/A | TEST-PAD-1.0MM | 1 | yes | bare ENIG copper test feature; not an assembled component
TP40 | AMT_FLASH_CS test pad | OpenPocket | PCB-TEST-PAD-1.0MM | N/A | TEST-PAD-1.0MM | 1 | yes | bare ENIG copper test feature; not an assembled component
TP41 | AMT_FLASH_CLK test pad | OpenPocket | PCB-TEST-PAD-1.0MM | N/A | TEST-PAD-1.0MM | 1 | yes | bare ENIG copper test feature; not an assembled component
TP42 | AMT_FLASH_MOSI test pad | OpenPocket | PCB-TEST-PAD-1.0MM | N/A | TEST-PAD-1.0MM | 1 | yes | bare ENIG copper test feature; not an assembled component
TP43 | AMT_FLASH_MISO test pad | OpenPocket | PCB-TEST-PAD-1.0MM | N/A | TEST-PAD-1.0MM | 1 | yes | bare ENIG copper test feature; not an assembled component
TP44 | BUZZER_PWM test pad | OpenPocket | PCB-TEST-PAD-1.0MM | N/A | TEST-PAD-1.0MM | 1 | yes | bare ENIG copper test feature; not an assembled component
TP45 | BUZZER_LOW test pad | OpenPocket | PCB-TEST-PAD-1.0MM | N/A | TEST-PAD-1.0MM | 1 | yes | bare ENIG copper test feature; not an assembled component
TP46 | AUDIO_I2S_BCLK test pad | OpenPocket | PCB-TEST-PAD-1.0MM | N/A | TEST-PAD-1.0MM | 1 | yes | bare ENIG copper test feature; not an assembled component
TP47 | AUDIO_I2S_WS test pad | OpenPocket | PCB-TEST-PAD-1.0MM | N/A | TEST-PAD-1.0MM | 1 | yes | bare ENIG copper test feature; not an assembled component
TP48 | AUDIO_I2S_DATA test pad | OpenPocket | PCB-TEST-PAD-1.0MM | N/A | TEST-PAD-1.0MM | 1 | yes | bare ENIG copper test feature; not an assembled component
TP49 | AUDIO_ENABLE test pad | OpenPocket | PCB-TEST-PAD-1.0MM | N/A | TEST-PAD-1.0MM | 1 | yes | bare ENIG copper test feature; not an assembled component
TP50 | SPK+ test pad | OpenPocket | PCB-TEST-PAD-1.0MM | N/A | TEST-PAD-1.0MM | 1 | yes | bare ENIG copper test feature; not an assembled component
TP51 | SPK- test pad | OpenPocket | PCB-TEST-PAD-1.0MM | N/A | TEST-PAD-1.0MM | 1 | yes | bare ENIG copper test feature; not an assembled component
TP52 | BL_LED_A test pad | OpenPocket | PCB-TEST-PAD-1.0MM | N/A | TEST-PAD-1.0MM | 1 | yes | bare ENIG copper test feature; not an assembled component
TP53 | BL_LED_K test pad | OpenPocket | PCB-TEST-PAD-1.0MM | N/A | TEST-PAD-1.0MM | 1 | yes | bare ENIG copper test feature; not an assembled component
TP54 | ESP_BOOT test pad | OpenPocket | PCB-TEST-PAD-1.0MM | N/A | TEST-PAD-1.0MM | 1 | yes | bare ENIG copper test feature; not an assembled component
TP55 | ESP_EN test pad | OpenPocket | PCB-TEST-PAD-1.0MM | N/A | TEST-PAD-1.0MM | 1 | yes | bare ENIG copper test feature; not an assembled component

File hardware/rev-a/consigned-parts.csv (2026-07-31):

Reference | Part | Quantity | Required revision | PCBWay operation | Acceptance criteria
MOD1 | RX5808 shielded receiver module | 1 | 20120322-style SPI-modifiable 28x23mm module | Remove selected RTC6715 SPI-enable pull-down before board assembly; restore shield; manually solder module | Correct supplier/revision; modification microscope inspection; shield seated; no bridges; DATA LE CLK tune test; RSSI and video functional

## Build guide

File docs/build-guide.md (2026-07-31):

# Bench prototype build guide

## 1. Build the power system without RF or video

1. Set the bench supply to 5.0 V with a conservative current limit.
2. Power only the ESP32-S3 board and verify 3.3 V, USB, and serial logging.
3. Add fused 5 V and 3.3 V rails with local decoupling.
4. Measure inrush, idle current, and temperature before adding another module.

## 2. Add controls

1. Connect the four gimbal axes to suitable ADC1 inputs.
2. Add UP, DOWN, ENTER, BACK, and the dedicated ARM switch.
3. Add AUX controls, trims, and the encoder only after the basic inputs work.
4. Verify every input in RivetTX and complete calibration.

## 3. Add ExpressLRS

1. Keep RF output locked and select the lowest power setting.
2. Connect full-duplex 3.3 V CRSF TX, RX, and ground.
3. Check model ID, telemetry, channel order, and CH5/ARM polarity.
4. Test module loss and recovery with the vehicle safe and propellers removed.

## 4. Test composite video without the OSD

1. Connect the matched TFT panel to the unpowered AMT630A snow-screen board,
   then inspect FFC orientation and locking.
2. Power the RX5808, AMT630A board, and backlight according to their exact
   specifications.
3. Temporarily connect RX5808 VIDEO OUT to the selected AMT630A CVBS input
   through the required coupling network.
4. Verify PAL and NTSC, noise floor, sync, and the single 75 Ω termination.
5. Remove the video transmitter or tune away from it. The display must show
   live snow instead of switching to a solid blue or black screen.
6. Measure loss-to-snow and recovery-to-picture timing, then remove the
   temporary direct connection.

## 5. Insert the AT7456E

1. Connect `RX5808 VIDEO OUT -> AT7456E VIN`.
2. Connect `AT7456E VOUT -> AMT630A CVBS IN`.
3. Connect level-shifted SCLK, MOSI, MISO, CS, and optional RESET.
4. Flash the OpenPocket profile and verify the interface in PAL and NTSC.
5. Remove the antenna or video source. Video loss must be reported while
   controls, CRSF, and telemetry continue uninterrupted.

## 6. Add RX5808 tuning

1. Verify DATA, LE, CLK, and RSSI on the exact RX5808 revision.
2. Start on one known frequency with a shielded or legally operated video
   transmitter.
3. Measure the programmed frequency and RSSI response.
4. Test the full scan table and video-loss recovery only after that succeeds.

## 7. Stop conditions

Stop immediately after any brownout, unexpected RF output, overheating,
broken common ground, GPIO overvoltage, missing failsafe, or unstable
composite sync. Correct the root cause before connecting the next subsystem.

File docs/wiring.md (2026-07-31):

# Wiring

This document uses **net names**, not universal pin numbers. RX5808 and
AT7456E breakout boards exist in several revisions. Record the exact module
markings and check continuity against the matching schematic before wiring.

## Complete signal overview

```text
5.8 GHz antenna
      |
   RX5808
 VIDEO OUT --------> AT7456E VIDEO IN / VIN
                      AT7456E VIDEO OUT / VOUT --------> AMT630A CVBS IN
                                                         |
                                                         +--> matched TFT FFC

RX5808 GND ----------+
AT7456E AGND/DGND ----+---- common video ground ---- AMT630A VIDEO GND
ESP32-S3 GND ---------+

ESP32-S3 DATA/LE/CLK -------------------------------> RX5808 tuning
ESP32-S3 ADC <--------------------------------------- RX5808 RSSI
ESP32-S3 SPI SCLK/MOSI/CS/RESET --------------------> AT7456E control
ESP32-S3 SPI MISO <---------------------------------- AT7456E status
ESP32-S3 CRSF TX/RX <-------------------------------> ExpressLRS TX
```

## Composite-video path

- Use one continuous composite route. Do not leave a second, parallel
  terminated RX5808-to-AMT630A path around the OSD.
- The AMT630A board is the final video load. Do not add a second 75 Ω
  termination without validating the complete source and coupling network.
- Use the AC-coupling and SAG/COUT components specified by the exact AT7456E
  module or relevant datasheet reference circuit.
- Keep video traces away from the ESP32 clock, switching-regulator inductor,
  CRSF lines, and ELRS antenna.

## RX5808 to ESP32-S3

| RX5808 signal | ESP32-S3 connection | Function |
|---|---|---|
| DATA | free output GPIO | serial programming data |
| LE / SELECT | free output GPIO | programming latch |
| CLK | free output GPIO | programming clock |
| RSSI | suitable ADC1 GPIO through scaling/filtering | scan strength |
| VIDEO OUT | no GPIO; connect to AT7456E VIN | composite picture |
| VCC | validated module supply | use the requirement of the exact module |
| GND | common video ground | reference for RSSI and video |

Do not use an ESP32 boot strap, flash/PSRAM pin, or USB D+/D- for RX5808
control. The final firmware driver must not bit-bang DATA/LE/CLK from the
250 Hz control task. Tuning and scanning belong in a service task.

## AT7456E to ESP32-S3

| AT7456E signal | ESP32-S3 / configuration | Requirement |
|---|---|---|
| SCLK | `RIVETTX_AT7456E_SCLK_GPIO` | SPI mode 0, 8 MHz default |
| SDIN / MOSI | `RIVETTX_AT7456E_MOSI_GPIO` | ESP32 to OSD |
| SDOUT / MISO | `RIVETTX_AT7456E_MISO_GPIO` | OSD to ESP32; maximum 3.3 V at ESP pin |
| CS | `RIVETTX_AT7456E_CS_GPIO` | active-low with pull-up during reset |
| RESET | `RIVETTX_AT7456E_RESET_GPIO` | optional active-low; `-1` selects software reset |
| VIN | RX5808 VIDEO OUT | composite input |
| VOUT | selected AMT630A CVBS input | composite output with overlay |
| AGND / DGND | common ground | short, low-impedance connection |

A bare AT7456E normally operates in a 5 V video domain. Use suitable buffers
between 3.3 V and 5 V for a bare IC. Never connect SDOUT directly to an
ESP32-S3 if that line can rise above 3.3 V. A breakout module may already
provide translation; verify its schematic rather than assuming it does.

## AMT630A board and TFT panel

| AMT630A board net | Connection | Requirement |
|---|---|---|
| selected CVBS input | AT7456E VOUT | use the input enabled by the board firmware |
| VIDEO GND | common RX5808/AT7456E ground | short return alongside the video signal |
| board power input | validated display rail | use the exact PCB rating, not the AMT630A IC voltage |
| TFT FFC | matched panel only | verify pin 1, RGB format, timing, and connector orientation |
| backlight output | matched panel backlight | verify current regulation and thermal load |
| key-board input | matching button board/network | optional; preserve known-good factory values |

The first OpenPocket revision treats the AMT630A board as an autonomous
composite-to-TFT stage. Do not connect its internal SPI flash, I2C, UART, or
factory-programming signals to the ESP32-S3. OpenPocket menus remain on the
AT7456E; the AMT630A internal OSD may be used only for display setup.

Before final wiring, prove that this exact board, flash image, and panel show
RF snow when sync is missing and recover quickly when video returns. Many
visually similar AMT630A boards intentionally replace weak video with a blue
screen and therefore do not meet the OpenPocket requirement.

## ExpressLRS and controls

| Function | Connection |
|---|---|
| ESP32 CRSF TX | ExpressLRS module RX |
| ESP32 CRSF RX | ExpressLRS module TX |
| gimbals | suitable ADC1 inputs through appropriate conditioning |
| buttons and switches | GPIO to ground with internal or external pull-up |
| trims and encoder | separate digital GPIOs |

Create a pin-allocation table for the selected ESP32-S3 board before wiring.
RivetTX rejects duplicate or invalid GPIO assignments, but it cannot detect an
electrical conflict with a module function that is not exposed at the header.

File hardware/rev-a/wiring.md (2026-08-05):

# Revision-A wiring and signal paths

## Internal PCB connections

These connections are routed entirely on the PCB and are not user wiring:

```text
RX5808 VIDEO OUT
  -> TP_VRX_VIDEO
  -> NORMAL/BYPASS solder-jumper input
  -> AT7456E VIN
  -> AT7456E VOUT
  -> TP_OSD_VIDEO
  -> AMT630A CVBS1
```

The manufactured jumper state is **NORMAL**. BYPASS connects RX5808 video
directly to AMT630A CVBS1 for diagnosis. It must never connect both drivers or
create a second 75 ohm termination.

The AMT630A drives 24-bit RGB plus DCLK, DISP, HSYNC, VSYNC, and DE directly to
the edge-mounted Hirose FH12-40S-0.5SH(55). The design is specific to the
Innolux AT050TN33 V.1 or a clone verified pin-for-pin and electrically. It is
not a universal 40-pin TFT interface.

| TFT pin | Net |
|---:|---|
| 1 | VLED- |
| 2 | VLED+ (approximately 19.8 V, 40 mA total) |
| 3 | GND |
| 4 | clean display 3.3 V |
| 5–12 | R0–R7 |
| 13–20 | G0–G7 |
| 21–28 | B0–B7 |
| 29 | GND |
| 30 | DCLK |
| 31 | DISP |
| 32 | HSYNC |
| 33 | VSYNC |
| 34 | DE |
| 35 | NC |
| 36 | GND |
| 37–40 | isolated unpopulated test pads only |

Panel pin 1 and bottom-contact flex orientation are release blockers until
checked against the exact panel datasheet and final mechanical stack.

## RX5808 module

Selected form factor: shielded 28 mm × 23 mm × approximately 3 mm module.

| Module pin | Board connection |
|---:|---|
| 1 | GND |
| 2 | 50 ohm 5.8 GHz antenna feed |
| 3 | RF ground |
| 4 | DATA / CH1 to GPIO7 |
| 5 | LE / CH2 to GPIO8 |
| 6 | CLK / CH3 to GPIO9 |
| 7 | digital ground |
| 8 | filtered switched 5V_VIDEO |
| 9 | RSSI to protected ADC1 GPIO5 |
| 10 | AUDIO test pad only |
| 11 | VIDEO to TP_VRX_VIDEO |
| 12 | analog/video ground |

The consigned module must be the selected SPI-capable 20120322-style revision.
PCBWay must remove the RTC6715 SPI-enable pull-down resistor before module
installation, inspect the modification under magnification, replace the
shield, and verify DATA/LE/CLK tuning. This is never an end-user modification.

Place 100 nF, 10 uF, and 330–470 uF low-ESR bulk capacitance after the local
ferrite/LC filter. Keep RSSI and video short and referenced to uninterrupted
ground. Common digital, analog-video, and module grounds join through the
continuous L2/L7 planes; do not create a floating video ground.

## User-installed connections

- Insert the exact supported TFT flex into the edge ZIF connector.
- Solder gimbals to labeled X/Y/3V3/GND groups.
- Solder switches, menu buttons, trims, encoder, and power switch to their
  labeled edge groups and strain-relief holes.
- Solder welded battery leads to BAT+ and BAT-. Connect a compatible 10 k NTC
  to NTC/NTC_GND. Never solder directly to an 18650 cell can.
- Press a 50-ohm U.FL/MHF1-to-SMA-female bulkhead cable vertically onto the
  bottom-side J11 receptacle. Fasten the SMA bulkhead to the enclosure before
  attaching the 5.8 GHz antenna; never let cable strain reach J11. Match SMA
  versus RP-SMA to the selected antenna. Install the separate 2.4 GHz ELRS and
  ESP32 Wi-Fi antennas in their marked RF regions.
- Connect a pre-flashed ExpressLRS nano receiver using four normal wires:
  ELRS_5V, ELRS_GND, ELRS_RX, ELRS_TX. From the ESP32 perspective GPIO17 TX
  connects to receiver RX; receiver TX connects to GPIO18 RX. ELRS_BOOT and
  ELRS_RESET are optional service pads.

The external ELRS rail is switched and designed for a 500 mA peak. Firmware
starts at 10 mW and exposes at most 100 mW. Controls and CRSF must remain safe
if any video-domain part is absent or faulted.

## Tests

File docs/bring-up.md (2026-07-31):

# Bring-up and acceptance tests

Complete this checklist for every physical revision. Keep measurements,
photographs, and the firmware commit with the test report.

## Electrical

- [ ] Every supply rail is correct both unloaded and loaded.
- [ ] No ESP32 GPIO is exposed to more than 3.3 V.
- [ ] Current limiting, a fuse, and local bulk capacitance are present.
- [ ] AMT630A/backlight startup, ELRS transmission, and video lock cause no brownout.
- [ ] AT7456E clock and SPI mode 0 have been checked with a logic analyzer.
- [ ] The composite path has exactly one correct 75 Ω termination.

## Controls and RF

- [ ] All gimbals are calibrated and move in the correct direction.
- [ ] CH5 is low at boot, during faults, after module loss, and in maintenance.
- [ ] ARM and AUX functions use only their assigned switches.
- [ ] CRSF continues at 250 Hz during OSD redraw and menu use.
- [ ] ExpressLRS binding, model ID, telemetry, and failsafe are verified.

## Video and OSD

- [ ] PAL lock shows all 30×16 cells without clipped edges.
- [ ] NTSC lock keeps all essential information inside rows 0–12.
- [ ] Menus, selection, edit mode, and warnings are readable.
- [ ] A one-character change does not trigger a full-screen redraw.
- [ ] PAL-to-NTSC and NTSC-to-PAL changes recover without a reboot.
- [ ] Video loss shows a warning and recovery causes a clean redraw.
- [ ] An absent or disconnected AT7456E leaves control responsive and safe.
- [ ] Lost or weak video produces snow, never a persistent blue/black fallback.
- [ ] Loss-to-snow and snow-to-picture recovery times are measured and accepted.
- [ ] PAL and NTSC both fill the intended TFT area without wrong scaling.
- [ ] The AMT630A board adds no unacceptable camera-to-photon latency.

## Endurance

- [ ] At least two hours of simultaneous control, telemetry, and video.
- [ ] Repeated power cycles and controlled brownout injection.
- [ ] Thermal check at the maximum selected RF, AMT630A, and backlight load.
- [ ] No character-NVM upload on every boot.
- [ ] No control deadlines missed by SPI, logging, USB, or UI activity.

A successful bench test is not permission to test with fitted propellers.
Perform separate vehicle, range, and failsafe tests afterward.

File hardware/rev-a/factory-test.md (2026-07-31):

# Revision-A factory test protocol

Factory firmware emits one newline-delimited JSON object per check over native
USB CDC. Every object contains `fixture`, `serial`, `firmware_commit`, `test`,
`passed`, `measurement`, `units`, and `limit`. The final record is
`{"test":"summary","passed":true}` only when all mandatory checks pass.

## Safe sequence

1. Visual/microscope inspection and resistance-to-ground checks with no cell,
   TFT, ELRS, or antennas attached.
2. Apply current-limited USB 5 V. Confirm 3.3 V, charger power path, USB
   enumeration, BOOT, RESET, and safe-off 5 V enables/backlight.
3. Check BQ25895 identity/status, MAX17048 absent-battery behavior, VBUS sense,
   both TCA9535 devices, and every control input with fixture switches.
4. Test gimbal ADC stimulus and verify monotonic calibrated readings.
5. Loop back CRSF UART and verify no transmission while simulator mode is
   active. ARM/CH5 must remain low.
6. Enable each switched 5 V domain separately and measure rise time, steady
   voltage, inrush, and off leakage.
7. With no card installed, verify active-high card detect and `3V3_SD` below
   0.20 V. Insert the fixture FAT32 card, require detect below 0.30 V after
   80 ms, rail 3.135–3.465 V with less than 100 mV excursion, then read/write/
   readback a 512-byte pseudorandom block at 400 kHz and 20 MHz. Remove it
   during a bounded logging run and require zero control or CRSF deadline
   misses. The JSON tests are `sd_detect`, `sd_power`, `sd_rw`, and
   `sd_hot_remove`.
8. Identify, erase, program, read back, and SHA-256 verify W25X05 while AMT630A
   reset is asserted and the isolated bus belongs to ESP32. Release ownership
   before AMT630A reset.
9. Verify AT7456E SPI identity/activity, reset, custom glyph upload, PAL/NTSC
   status, and independent sync-loss reporting.
10. Tune RX5808 through all 48 table entries. Record exact RTC6715 frames, RSSI
   ADC baseline, and video output at TP_VRX_VIDEO. Cancel a scan during dwell
   and verify the saved channel is restored.
11. Apply fixture PAL and NTSC composite sources through the NORMAL chain.
    Verify TP_OSD_VIDEO, OSD overlay, AMT630A automatic recovery, snow/no-blue
    behavior, panel timings, and colour bars.
12. Ramp backlight PWM while measuring VLED+, total LED current, switch-node
    waveform, inductor/diode temperature, and default-off restart.
13. Attach a protected fixture cell and NTC. Verify conservative charge current,
    thermal/current reduction, gauge voltage/SOC, operation while charging,
    USB-only operation, and low-battery shutdown.

Composite test points are oscilloscope/fixture measurements, not user wiring.
No propeller or powered aircraft mechanism is permitted during factory test.

First articles additionally require thermal imaging, RF coexistence, ELRS at
10 mW and 100 mW, antenna-region validation, multi-hour endurance, and a
propeller-off HIL report. Until those pass, the board remains an engineering
prototype.

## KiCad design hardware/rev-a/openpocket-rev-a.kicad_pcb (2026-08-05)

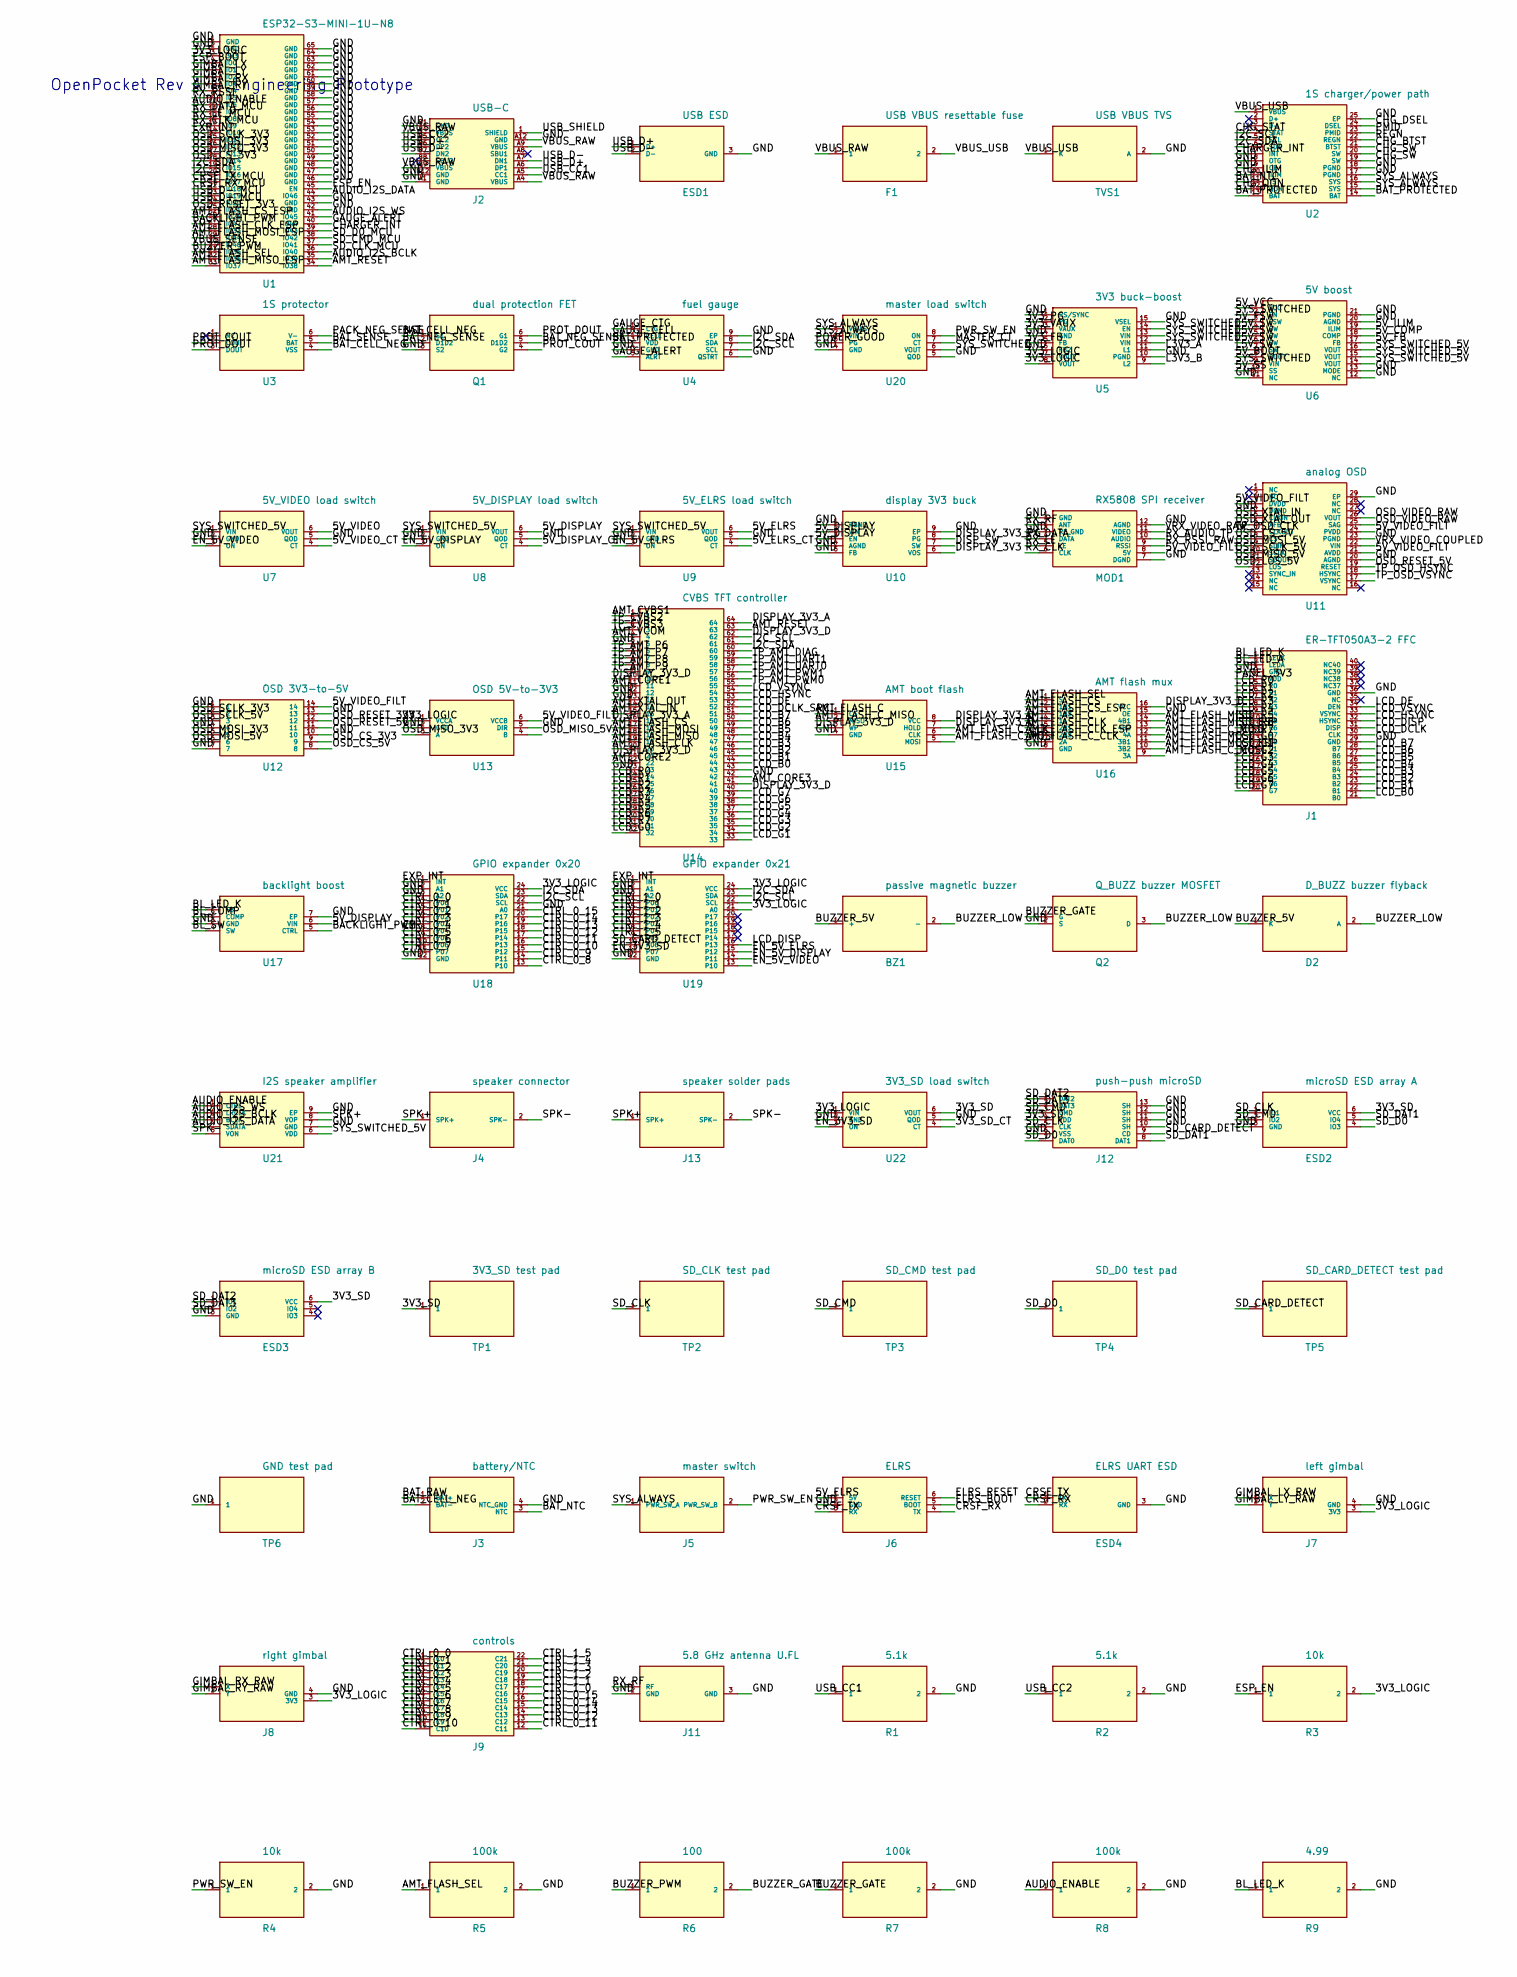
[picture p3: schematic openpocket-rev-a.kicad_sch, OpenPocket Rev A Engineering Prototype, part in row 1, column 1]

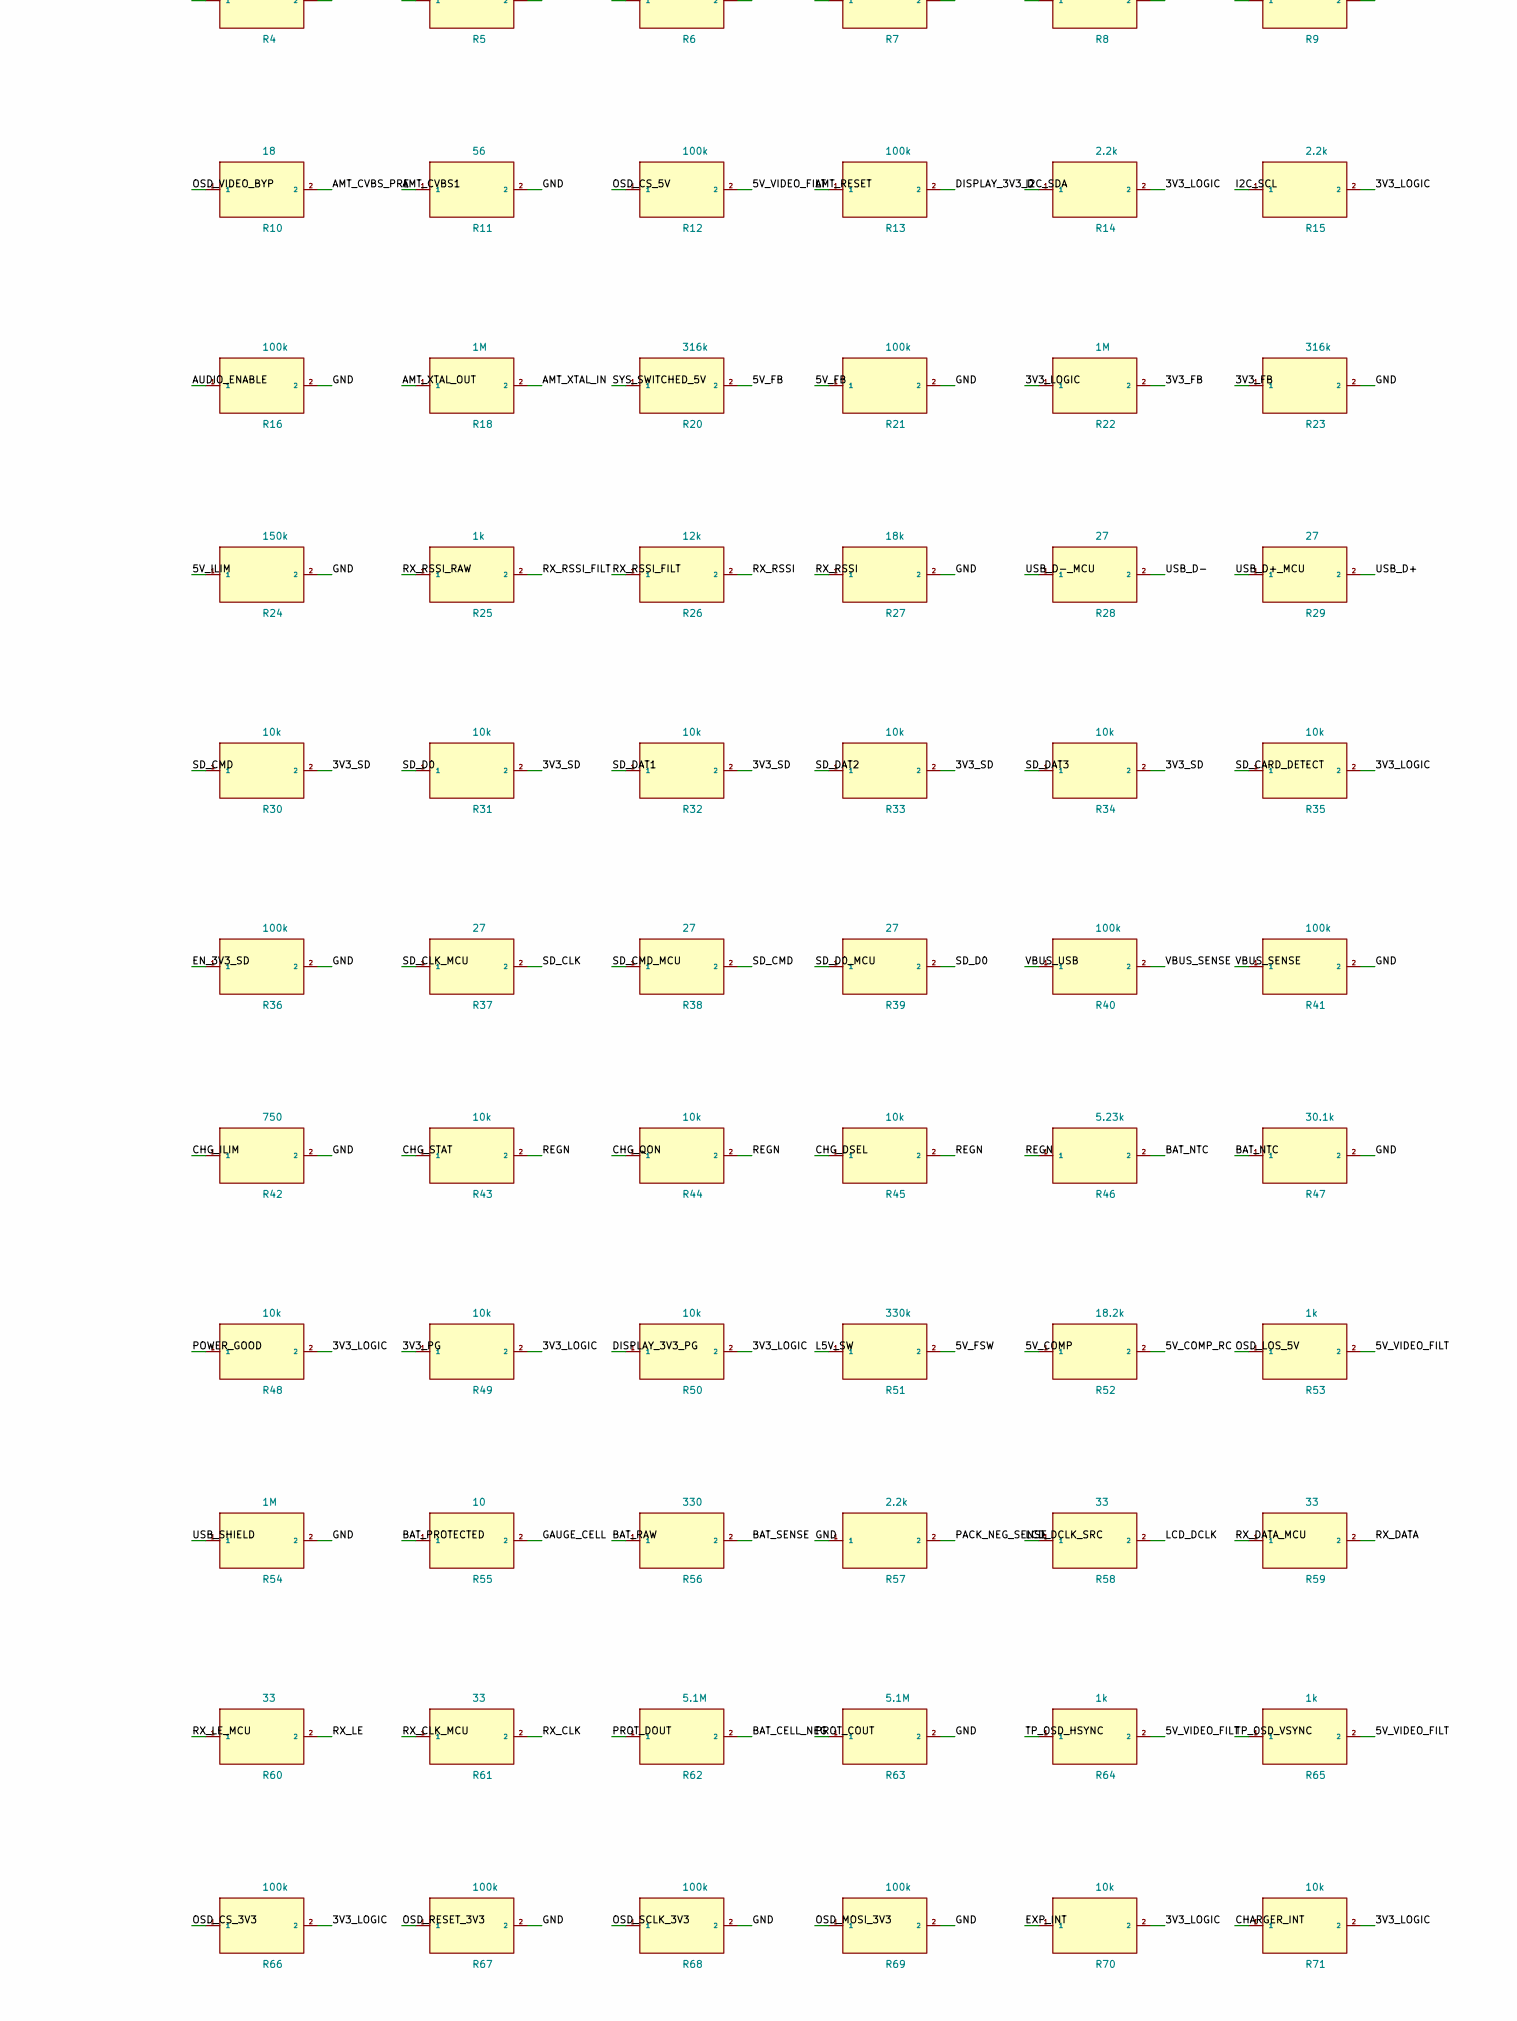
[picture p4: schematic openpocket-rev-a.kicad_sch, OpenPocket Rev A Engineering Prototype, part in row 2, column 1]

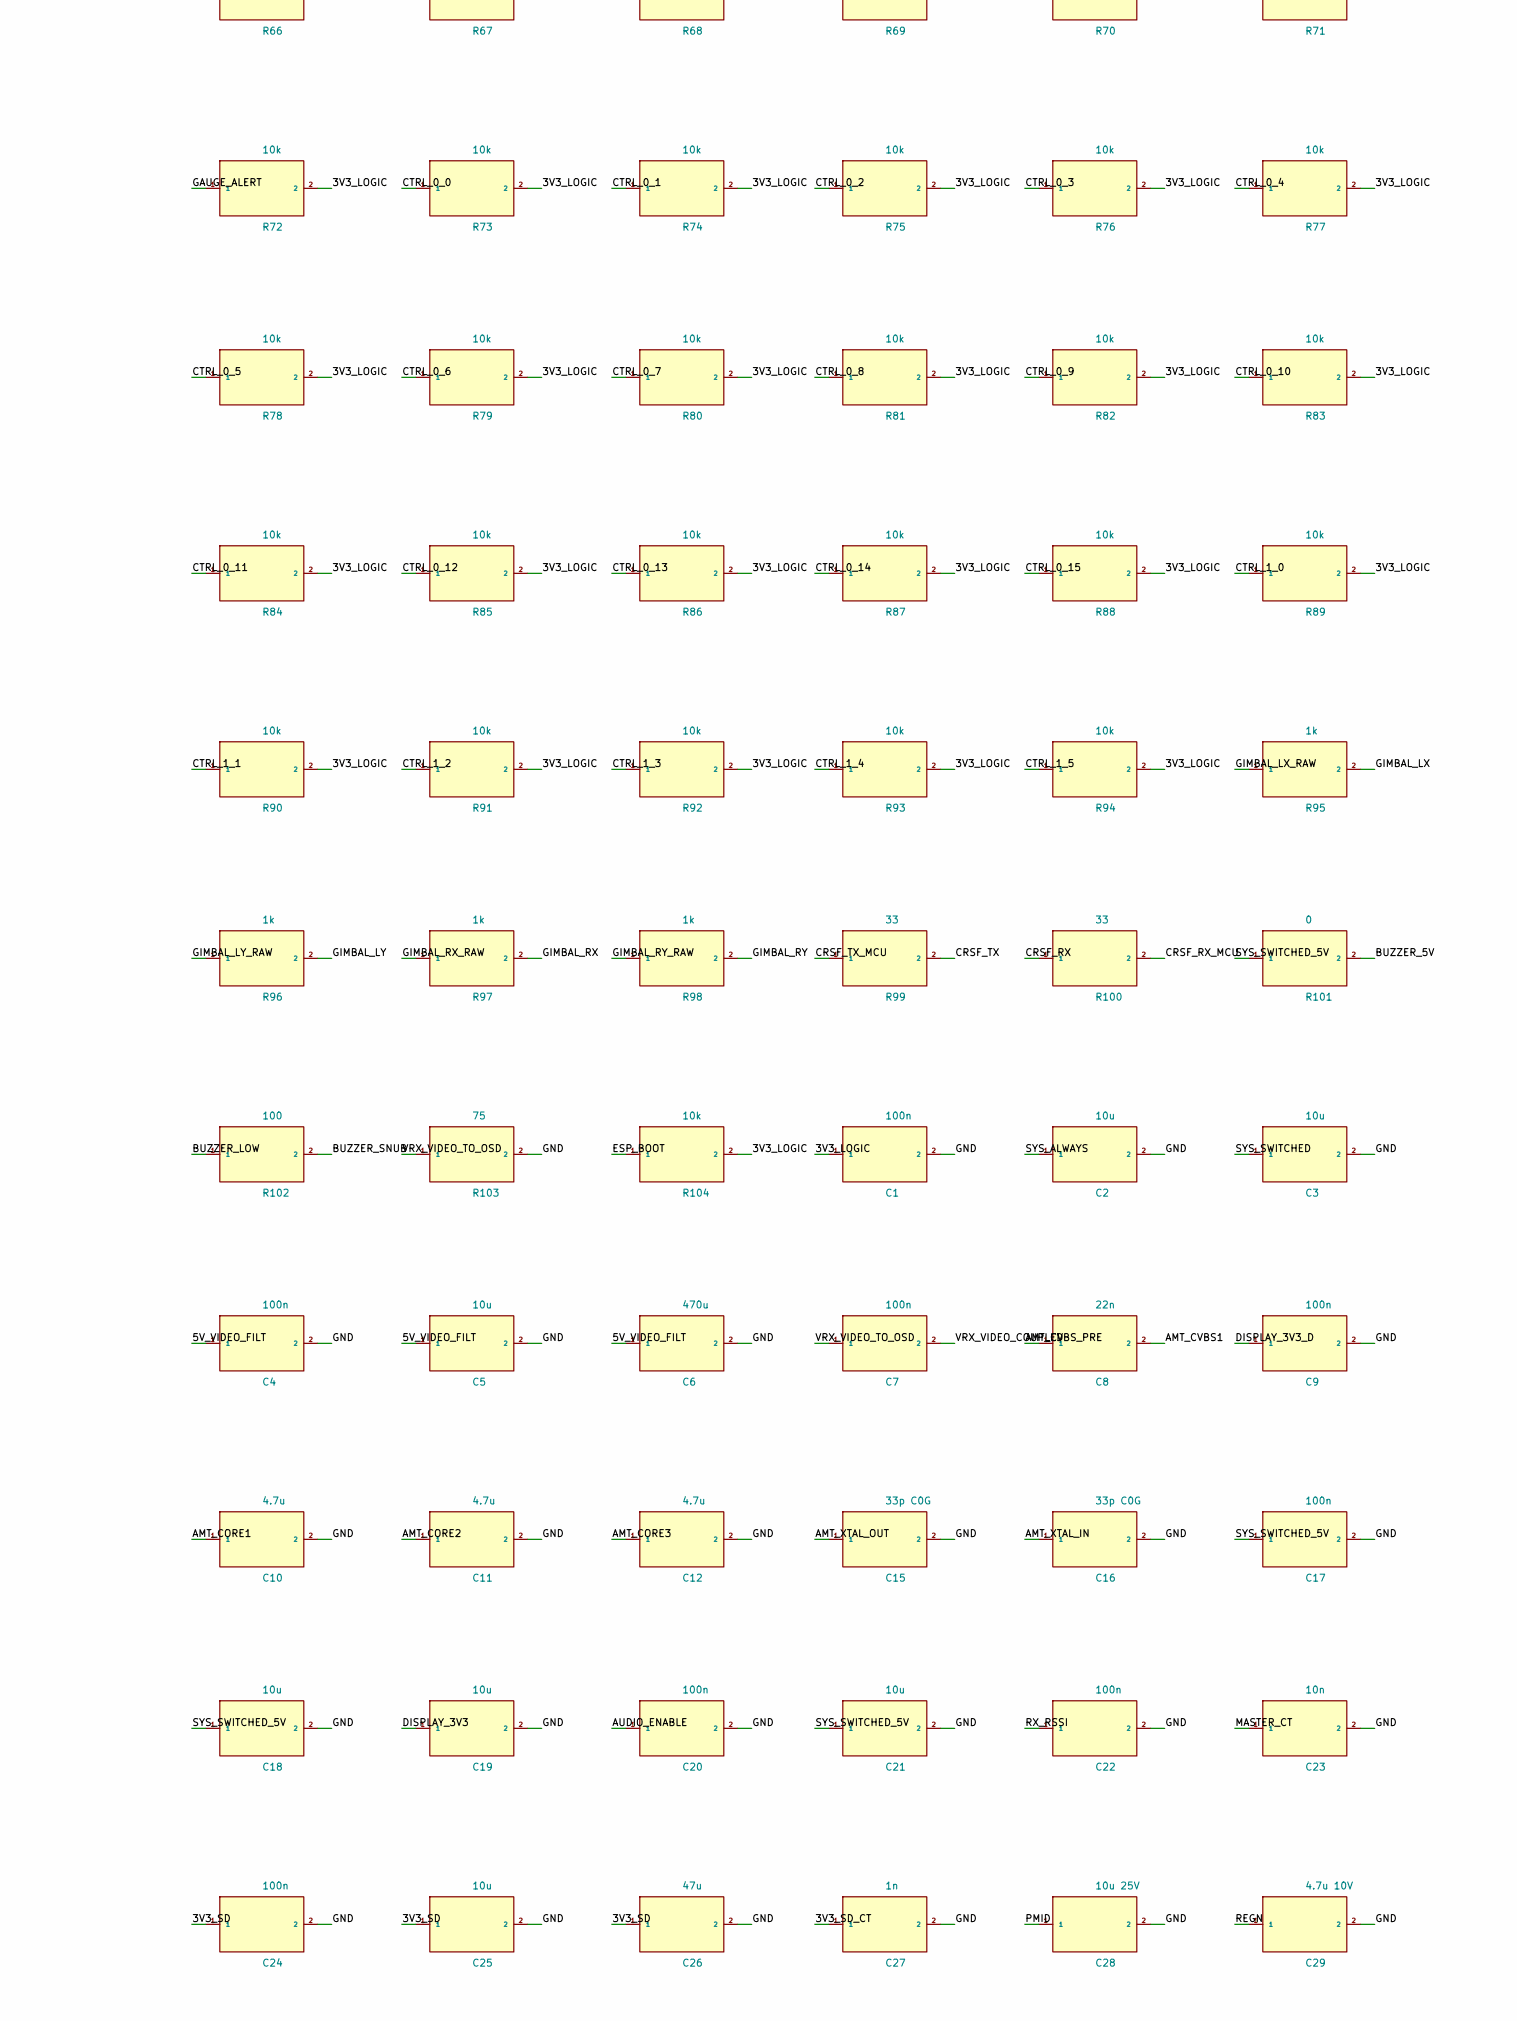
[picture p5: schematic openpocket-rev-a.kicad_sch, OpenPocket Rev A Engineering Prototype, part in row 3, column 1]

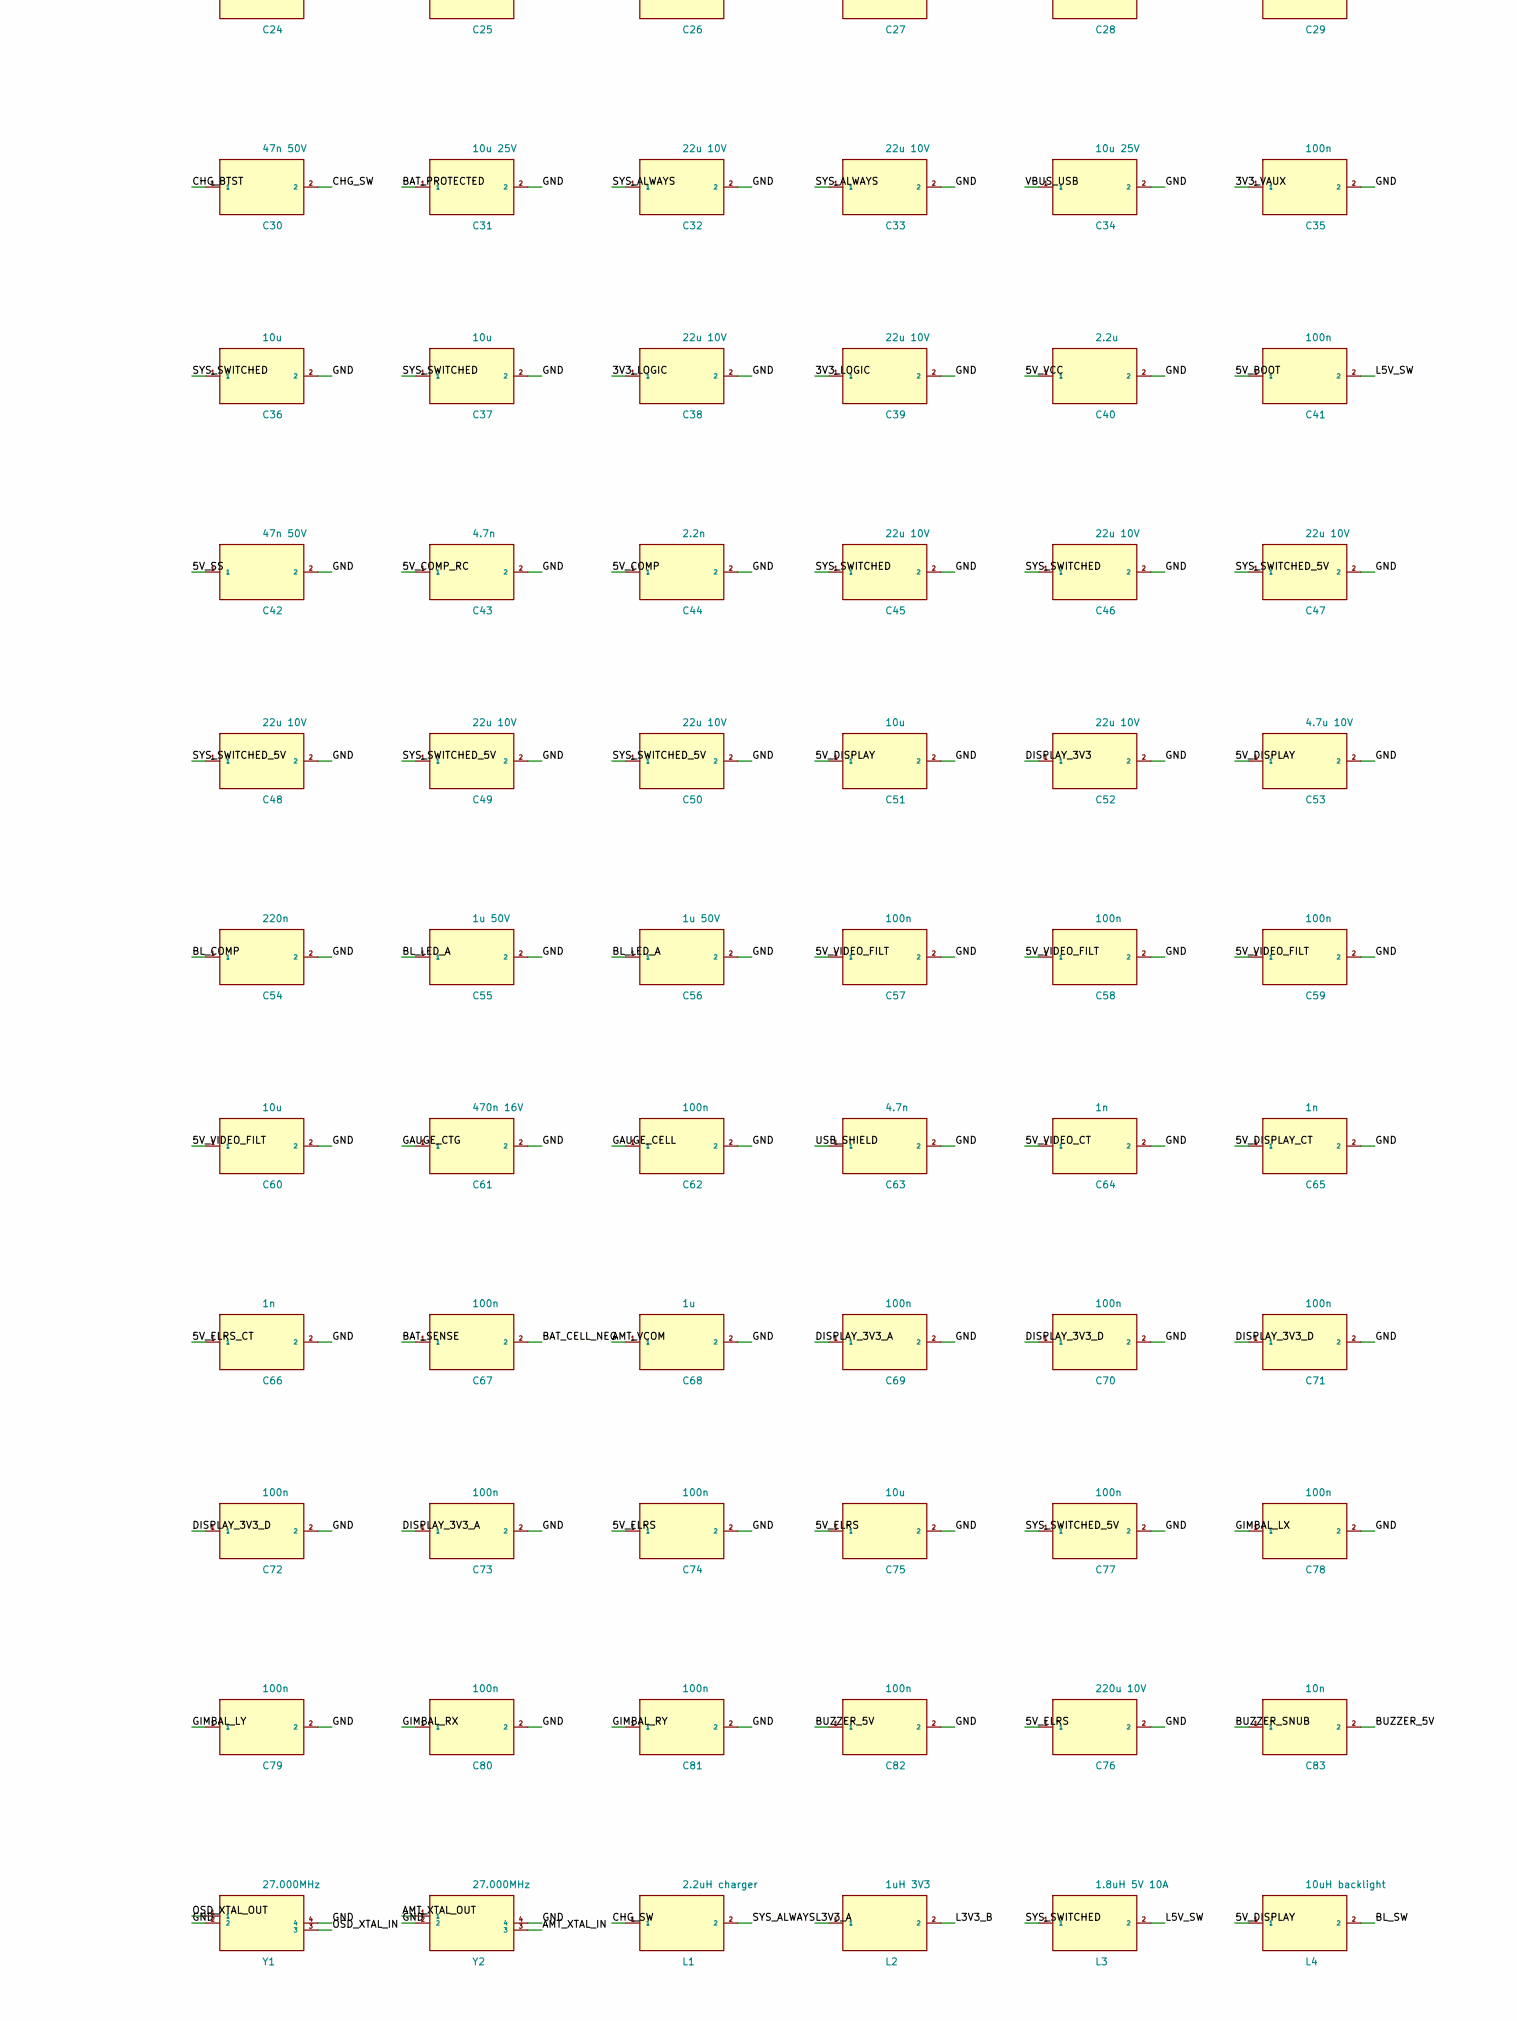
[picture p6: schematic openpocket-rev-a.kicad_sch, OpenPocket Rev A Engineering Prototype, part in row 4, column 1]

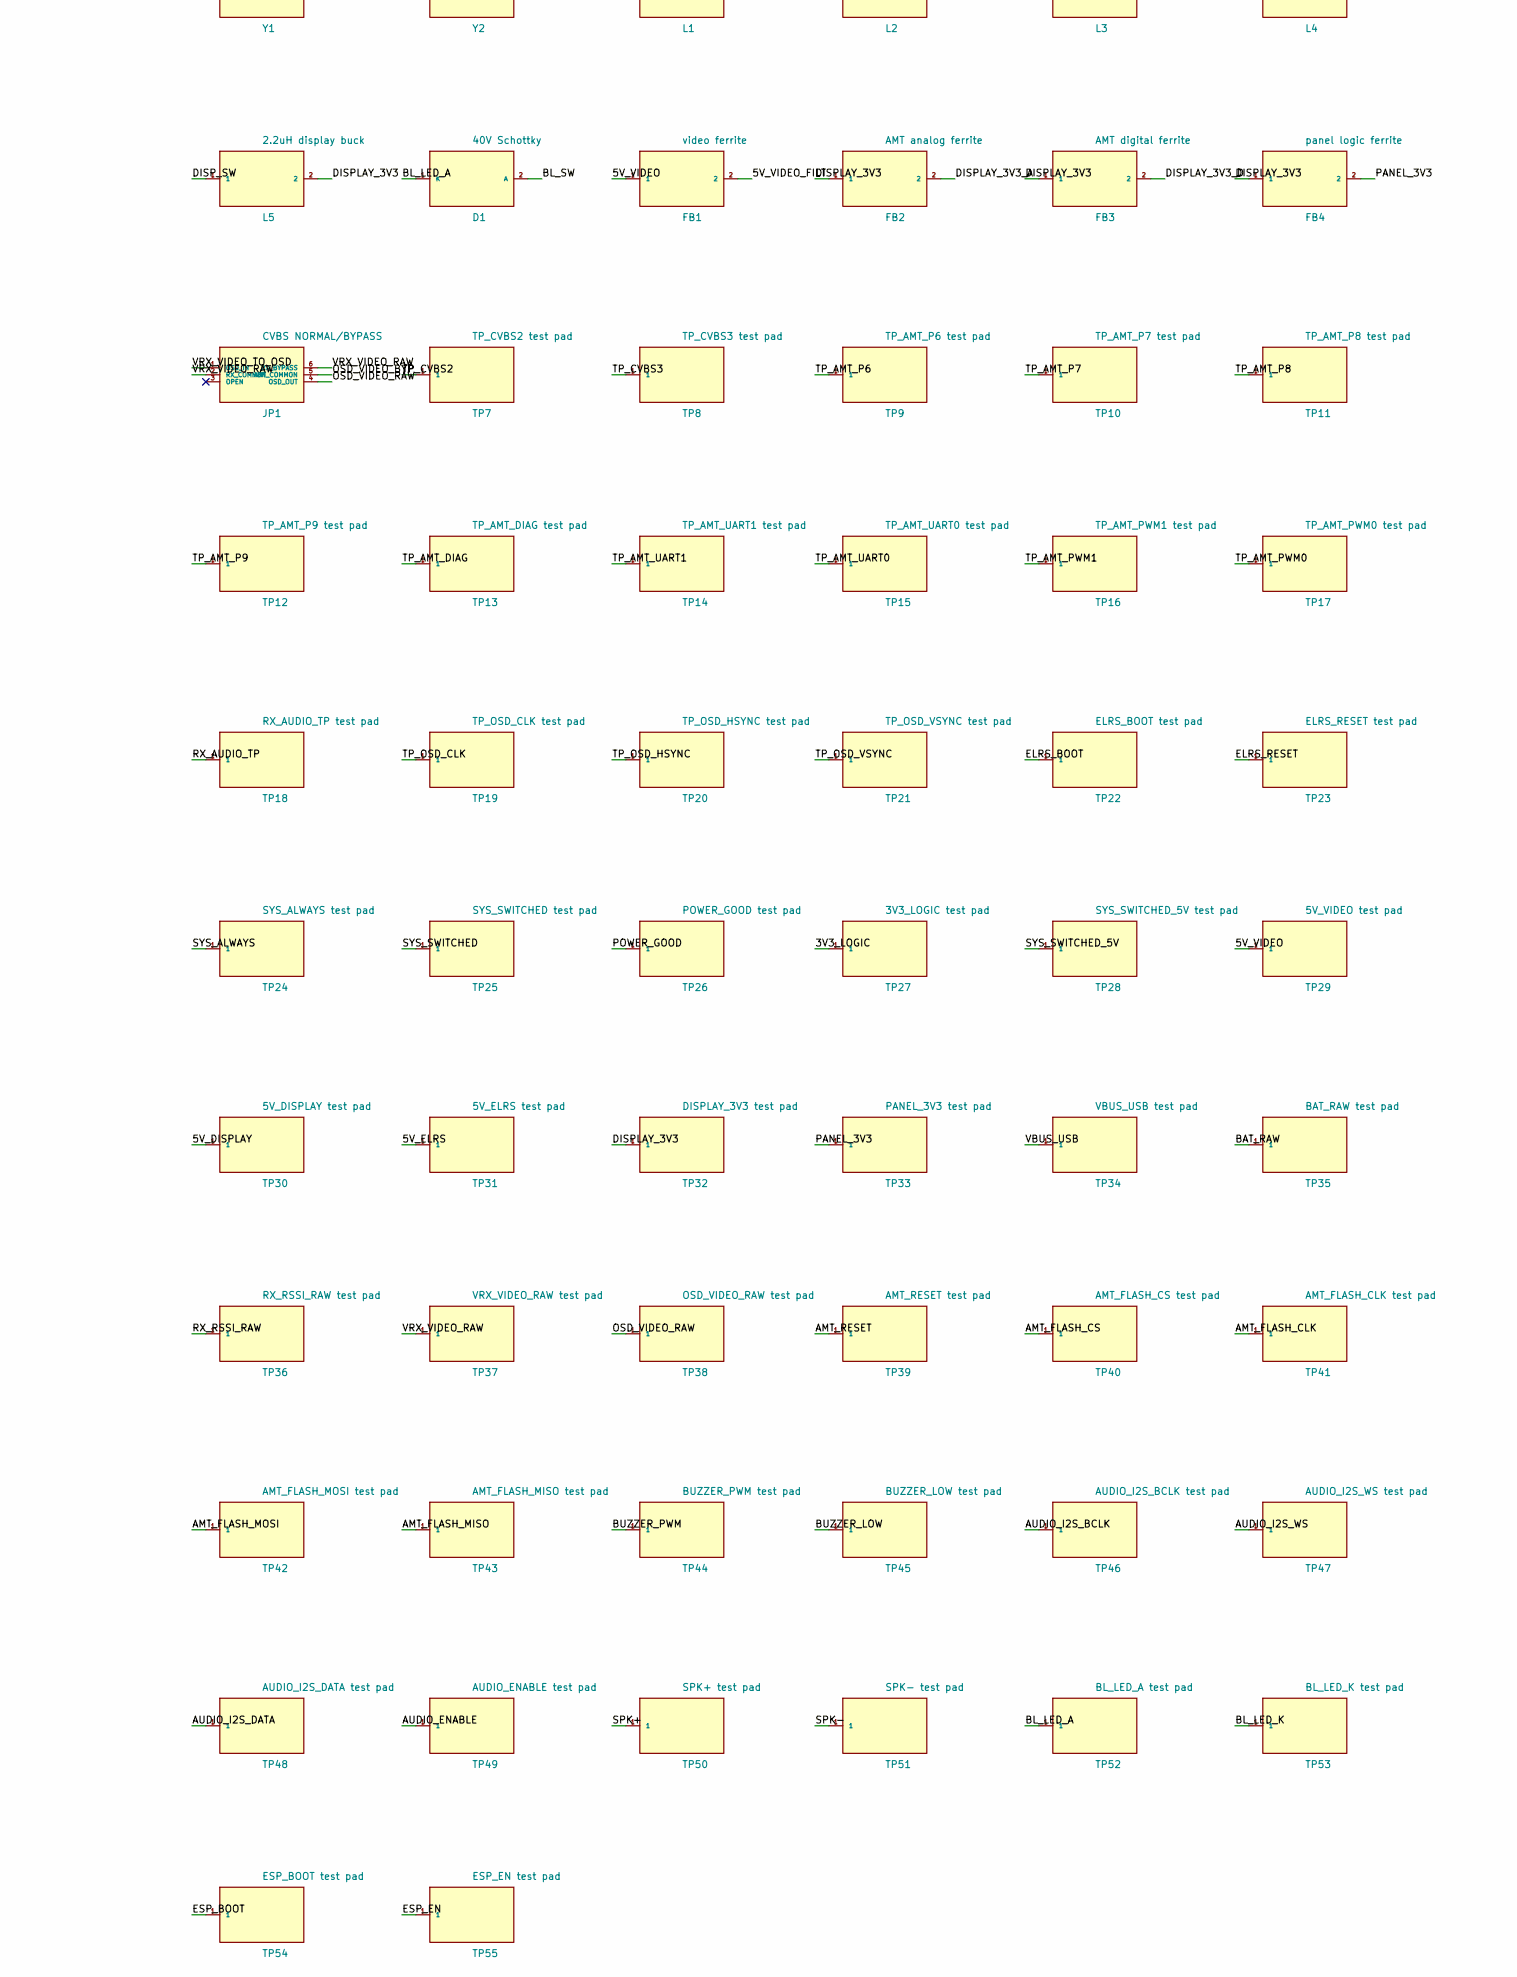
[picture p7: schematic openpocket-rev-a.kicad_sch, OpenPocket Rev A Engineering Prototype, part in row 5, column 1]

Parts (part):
BZ1: passive magnetic buzzer; SMD-7.5x7.5; MPN YS-SBZ7525C05R30; LCSC C7421675
C1, C4, C7, C9, C17, C20, C22, C24, C35, C41, C57, C58, C59, C62, C67, C69, C70, C71, C72, C73, C74, C77, C78, C79, C80, C81, C82: 100n; C0402; MPN CL05B104KO5NNNC; LCSC C1525
C2, C3, C5, C18, C19, C21, C25, C36, C37, C51, C60, C75: 10u; C0805; MPN CL21A106KAYNNNE; LCSC C15850
C6: 470u; SMD-D10; MPN VZH471M1ATR-1008; LCSC C249929
C8: 22n; C0402; MPN CL05B223KB5NNNC; LCSC C337699
C10, C11, C12: 4.7u; C0603; MPN CL10A475KP8NNNC; LCSC C1705
C15, C16: 33p C0G; C0402; MPN CC0402JRNPO9BN330; LCSC C107005
C23, C83: 10n; C0402; MPN CL05B103KB5NNNC; LCSC C15195
C26: 47u; C1206; MPN CL31A476MPHNNNE; LCSC C96123
C27, C64, C65, C66: 1n; C0402; MPN CL05B102KB5NNNC; LCSC C14442
C28, C31, C34: 10u 25V; C0805; MPN CGA0805X7R106K250MT; LCSC C6119932
C29, C53: 4.7u 10V; 0603; MPN 0603B475K100NT; LCSC C108342
C30, C42: 47n 50V; C0402; MPN CC0402KRX7R9BB473; LCSC C272875
C32, C33, C38, C39, C45, C46, C47, C48, C49, C50, C52: 22u 10V; C0805; MPN CGA0805X7R226M100MT; LCSC C23692981
C40: 2.2u; C0603; MPN CL10A225KO8NNNC; LCSC C23630
C43, C63: 4.7n; C0402; MPN CL05B472KB5NNNC; LCSC C84705
C44: 2.2n; C0402; MPN CL05B222KB5NNNC; LCSC C84703
C54: 220n; C0402; MPN CC0402KRX7R8BB224; LCSC C723566
C55, C56: 1u 50V; C0805; MPN CC0805KKX7R9BB105; LCSC C91185
C61: 470n 16V; 0402; MPN CGA0402X7R474K160GT; LCSC C22435970
C68: 1u; C0402; MPN CL05A105KA5NQNC; LCSC C52923
C76: 220u 10V; CAP-SMD_BD8.0-L8.3-W8.3-FD; MPN EEEFK1A221P; LCSC C401648
D1: 40V Schottky; SMA_L4.3-W2.6-LS5.2-RD; MPN B240A-13-F; LCSC C92506
D2: D_BUZZ buzzer flyback; SOD-123F_L2.7-W1.6-LS3.8-RD; MPN 1N4148W; LCSC C81598
ESD1: USB ESD; SOT-9X3-3_L1.0-W0.8-P0.35-LS1.0-BR; MPN TPD2EUSB30DRTR; LCSC C97502
ESD2: microSD ESD array A; SOT-563_L1.6-W1.2-P0.50-LS1.6-BL; MPN TPD4E001DRLR; LCSC C527516
ESD3: microSD ESD array B; SOT-563_L1.6-W1.2-P0.50-LS1.6-BL; MPN TPD4E001DRLR; LCSC C527516
ESD4: ELRS UART ESD; SOT-9X3-3_L1.0-W0.8-P0.35-LS1.0-BR; MPN TPD2EUSB30DRTR; LCSC C97502
F1: USB VBUS resettable fuse; F1206; MPN 1206L200PR; LCSC C151163
FB1: video ferrite; L0805; MPN BLM21PG221SN1D; LCSC C85840
FB2: AMT analog ferrite; L0603; MPN BLM18AG601SN1D; LCSC C19330
FB3: AMT digital ferrite; L0603; MPN BLM18AG601SN1D; LCSC C19330
FB4: panel logic ferrite; L0603; MPN BLM18AG601SN1D; LCSC C19330
J1: ER-TFT050A3-2 FFC; FPC-SMD_FH12-40S-0.5SH-55; MPN FH12-40S-0.5SH(55); LCSC C202114
J2: USB-C; TYPE-C-SMD_SBC-160S1A-20-S412; MPN USB4105-GF-A; LCSC C3020560
J3: battery/NTC; EDGE-PADS-4; MPN SOLDER-PADS-4; LCSC CONS
J4: speaker connector; CONN-SMD_P2.00_S2B-PH-SM4-TB-LF-SN; MPN S2B-PH-SM4-TB(LF)(SN); LCSC C295747
J5: master switch; EDGE-PADS-2; MPN SOLDER-PADS-2; LCSC CONS
J6: ELRS; EDGE-PADS-6; MPN SOLDER-PADS-6; LCSC CONS
J7: left gimbal; EDGE-PADS-4; MPN SOLDER-PADS-4; LCSC CONS
J8: right gimbal; EDGE-PADS-4; MPN SOLDER-PADS-4; LCSC CONS
J9: controls; EDGE-PADS-22; MPN SOLDER-PADS-22; LCSC CONS
J11: 5.8 GHz antenna U.FL; RF-SMD_FRF05002-JSS103M; MPN U.FL-R-SMT-1(10); LCSC C88373
J12: push-push microSD; TF-001A-P3; MPN TF-001A-P3; LCSC C3021282
J13: speaker solder pads; EDGE-PADS-2; MPN SOLDER-PADS-2; LCSC CONS
JP1: CVBS NORMAL/BYPASS; SOLDER-JUMPER-6; MPN SJ-DPDT; LCSC N/A
L1: 2.2uH charger; IND-SMD_L4.0-W4.0_LQH44PN2R2MP0L; MPN SWPA4030S2R2MT; LCSC C36409
L2: 1uH 3V3; IND-SMD_L4.0-W4.0_SWPA40XXS; MPN SWPA4020S1R0MT; LCSC C142484
L3: 1.8uH 5V 10A; IND-SMD_L6.6-W6.4-P4.04_XAL6030-182MEC; MPN XAL6030-182MEC; LCSC C19191693
L4: 10uH backlight; IND-SMD_L4.0-W4.0_SLW4010S; MPN SWPA4020S100MT; LCSC C82398
L5: 2.2uH display buck; IND-SMD_L3.0-W3.0; MPN SWPA3015S2R2MT; LCSC C43389
MOD1: RX5808 SPI receiver; COMM-SMD_12P_RX5808; MPN RX5808 SPI-modified; LCSC C2908157
Q1: dual protection FET; SOT-23-6_L2.9-W1.6-P0.95-LS2.8-BR; MPN FS8205A; LCSC C908265
Q2: Q_BUZZ buzzer MOSFET; SOT-23-3_L2.9-W1.3-P1.90-LS2.4-BR; MPN AO3400A; LCSC C20917
R1, R2: 5.1k; R0402; MPN RC0402FR-075K1L; LCSC C105872
R3, R4, R30, R31, R32, R33, R34, R35, R43, R44, R45, R48, R49, R50, R70, R71, R72, R73, R74, R75, R76, R77, R78, R79, R80, R81, R82, R83, R84, R85, R86, R87, R88, R89, R90, R91, R92, R93, R94, R104: 10k; R0402; MPN RC0402FR-0710KL; LCSC C60490
R5, R7, R8, R12, R13, R16, R21, R36, R40, R41, R66, R67, R68, R69: 100k; R0402; MPN RC0402FR-07100KL; LCSC C60491
R6, R102: 100; R0402; MPN RC0402FR-07100RL; LCSC C106232
R9: 4.99; R0603; MPN RC0603FR-074R99L; LCSC C137704
R10: 18; R0603; MPN RC0603FR-0718RL; LCSC C245924
R11: 56; R0603; MPN RC0603FR-0756RL; LCSC C126360
R14, R15: 2.2k; R0402; MPN RC0402FR-072K2L; LCSC C114762
R18, R22, R54: 1M; R0402; MPN RC0402FR-071ML; LCSC C138033
R20, R23: 316k; R0402; MPN RC0402FR-07316KL; LCSC C185427
R24: 150k; R0402; MPN RC0402FR-07150KL; LCSC C93947
R25, R53, R64, R65, R95, R96, R97, R98: 1k; R0402; MPN RC0402FR-071KL; LCSC C106235
R26: 12k; R0402; MPN RC0402FR-0712KL; LCSC C114760
R27: 18k; R0402; MPN RC0402FR-0718KL; LCSC C138044
R28, R29, R37, R38, R39: 27; R0402; MPN RC0402FR-0727RL; LCSC C138021
R42: 750; R0402; MPN RC0402FR-07750RL; LCSC C137936
R46: 5.23k; R0402; MPN RC0402FR-075K23L; LCSC C477746
R47: 30.1k; R0402; MPN RC0402FR-0730K1L; LCSC C138009
R51: 330k; R0402; MPN RC0402FR-07330KL; LCSC C138006
R52: 18.2k; R0402; MPN RC0402FR-0718K2L; LCSC C274351
R55: 10; R0402; MPN RC0402FR-0710RL; LCSC C138066
R56: 330; R0402; MPN 0402WGF3300TCE; LCSC C25104
R57: 2.2k; R0402; MPN 0402WGF2201TCE; LCSC C25879
R58, R59, R60, R61, R99, R100: 33; R0402; MPN RC0402FR-0733RL; LCSC C138002
R62, R63: 5.1M; 0402; MPN 0402WGF5104TCE; LCSC C270595
R101: 0; R0402; MPN RC0402FR-070RL; LCSC C106231
R103: 75; R0603; MPN RC0603FR-0775RL; LCSC C112309
TP1: 3V3_SD test pad; TEST-PAD-1.0MM; MPN PCB-TEST-PAD-1.0MM; LCSC N/A
TP2: SD_CLK test pad; TEST-PAD-1.0MM; MPN PCB-TEST-PAD-1.0MM; LCSC N/A
TP3: SD_CMD test pad; TEST-PAD-1.0MM; MPN PCB-TEST-PAD-1.0MM; LCSC N/A
TP4: SD_D0 test pad; TEST-PAD-1.0MM; MPN PCB-TEST-PAD-1.0MM; LCSC N/A
TP5: SD_CARD_DETECT test pad; TEST-PAD-1.0MM; MPN PCB-TEST-PAD-1.0MM; LCSC N/A
TP6: GND test pad; TEST-PAD-1.0MM; MPN PCB-TEST-PAD-1.0MM; LCSC N/A
TP7: TP_CVBS2 test pad; TEST-PAD-1.0MM; MPN PCB-TEST-PAD-1.0MM; LCSC N/A
TP8: TP_CVBS3 test pad; TEST-PAD-1.0MM; MPN PCB-TEST-PAD-1.0MM; LCSC N/A
TP9: TP_AMT_P6 test pad; TEST-PAD-1.0MM; MPN PCB-TEST-PAD-1.0MM; LCSC N/A
TP10: TP_AMT_P7 test pad; TEST-PAD-1.0MM; MPN PCB-TEST-PAD-1.0MM; LCSC N/A
TP11: TP_AMT_P8 test pad; TEST-PAD-1.0MM; MPN PCB-TEST-PAD-1.0MM; LCSC N/A
TP12: TP_AMT_P9 test pad; TEST-PAD-1.0MM; MPN PCB-TEST-PAD-1.0MM; LCSC N/A
TP13: TP_AMT_DIAG test pad; TEST-PAD-1.0MM; MPN PCB-TEST-PAD-1.0MM; LCSC N/A
TP14: TP_AMT_UART1 test pad; TEST-PAD-1.0MM; MPN PCB-TEST-PAD-1.0MM; LCSC N/A
TP15: TP_AMT_UART0 test pad; TEST-PAD-1.0MM; MPN PCB-TEST-PAD-1.0MM; LCSC N/A
TP16: TP_AMT_PWM1 test pad; TEST-PAD-1.0MM; MPN PCB-TEST-PAD-1.0MM; LCSC N/A
TP17: TP_AMT_PWM0 test pad; TEST-PAD-1.0MM; MPN PCB-TEST-PAD-1.0MM; LCSC N/A
TP18: RX_AUDIO_TP test pad; TEST-PAD-1.0MM; MPN PCB-TEST-PAD-1.0MM; LCSC N/A
TP19: TP_OSD_CLK test pad; TEST-PAD-1.0MM; MPN PCB-TEST-PAD-1.0MM; LCSC N/A
TP20: TP_OSD_HSYNC test pad; TEST-PAD-1.0MM; MPN PCB-TEST-PAD-1.0MM; LCSC N/A
TP21: TP_OSD_VSYNC test pad; TEST-PAD-1.0MM; MPN PCB-TEST-PAD-1.0MM; LCSC N/A
TP22: ELRS_BOOT test pad; TEST-PAD-1.0MM; MPN PCB-TEST-PAD-1.0MM; LCSC N/A
TP23: ELRS_RESET test pad; TEST-PAD-1.0MM; MPN PCB-TEST-PAD-1.0MM; LCSC N/A
TP24: SYS_ALWAYS test pad; TEST-PAD-1.0MM; MPN PCB-TEST-PAD-1.0MM; LCSC N/A
TP25: SYS_SWITCHED test pad; TEST-PAD-1.0MM; MPN PCB-TEST-PAD-1.0MM; LCSC N/A
TP26: POWER_GOOD test pad; TEST-PAD-1.0MM; MPN PCB-TEST-PAD-1.0MM; LCSC N/A
TP27: 3V3_LOGIC test pad; TEST-PAD-1.0MM; MPN PCB-TEST-PAD-1.0MM; LCSC N/A
TP28: SYS_SWITCHED_5V test pad; TEST-PAD-1.0MM; MPN PCB-TEST-PAD-1.0MM; LCSC N/A
TP29: 5V_VIDEO test pad; TEST-PAD-1.0MM; MPN PCB-TEST-PAD-1.0MM; LCSC N/A
TP30: 5V_DISPLAY test pad; TEST-PAD-1.0MM; MPN PCB-TEST-PAD-1.0MM; LCSC N/A
TP31: 5V_ELRS test pad; TEST-PAD-1.0MM; MPN PCB-TEST-PAD-1.0MM; LCSC N/A
TP32: DISPLAY_3V3 test pad; TEST-PAD-1.0MM; MPN PCB-TEST-PAD-1.0MM; LCSC N/A
TP33: PANEL_3V3 test pad; TEST-PAD-1.0MM; MPN PCB-TEST-PAD-1.0MM; LCSC N/A
TP34: VBUS_USB test pad; TEST-PAD-1.0MM; MPN PCB-TEST-PAD-1.0MM; LCSC N/A
TP35: BAT_RAW test pad; TEST-PAD-1.0MM; MPN PCB-TEST-PAD-1.0MM; LCSC N/A
TP36: RX_RSSI_RAW test pad; TEST-PAD-1.0MM; MPN PCB-TEST-PAD-1.0MM; LCSC N/A
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

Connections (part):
3V3_FB: R22.2, R23.1, U5.5 (FB)
3V3_LOGIC: C1.1, C38.1, C39.1, J7.3 (3V3), J8.3 (3V3), R3.2, R14.2, R15.2, R22.1, R35.2, R48.2, R49.2, R50.2, R66.2, R70.2, R71.2, R72.2, R73.2, R74.2, R75.2, R76.2, R77.2, R78.2, R79.2, R80.2, R81.2, R82.2, R83.2, R84.2, R85.2, R86.2, R87.2, R88.2, R89.2, R90.2, R91.2, R92.2, R93.2, R94.2, R104.2, TP27.1, U1.3 (3V3), U5.7 (VOUT), U5.8 (VOUT), U13.1 (VCCA), U18.24 (VCC), U19.21 (A0), U19.24 (VCC), U22.1 (VIN)
3V3_PG: R49.1, U5.2 (PG)
3V3_SD: C24.1, C25.1, C26.1, ESD2.6 (VCC), ESD3.6 (VCC), J12.4 (VDD), R30.2, R31.2, R32.2, R33.2, R34.2, TP1.1, U22.6 (VOUT)
3V3_SD_CT: C27.1, U22.4 (CT)
3V3_VAUX: C35.1, U5.3 (VAUX)
5V_BOOT: C41.1, U6.8 (BOOT)
5V_COMP: C44.1, R52.1, U6.18 (COMP)
5V_COMP_RC: C43.1, R52.2
5V_DISPLAY: C51.1, C53.1, L4.1, TP30.1, U8.6 (VOUT), U10.2 (VIN), U10.3 (EN), U17.6 (VIN)
5V_DISPLAY_CT: C65.1, U8.4 (CT)
5V_ELRS: C74.1, C75.1, C76.1, J6.1 (5V), TP31.1, U9.6 (VOUT)
5V_ELRS_CT: C66.1, U9.4 (CT)
5V_FB: R20.2, R21.1, U6.17 (FB)
5V_FSW: R51.2, U6.3 (FSW)
5V_ILIM: R24.1, U6.19 (ILIM)
5V_SS: C42.1, U6.10 (SS)
5V_VCC: C40.1, U6.1 (VCC)
5V_VIDEO: FB1.1, TP29.1, U7.6 (VOUT)
5V_VIDEO_CT: C64.1, U7.4 (CT)
5V_VIDEO_FILT: C4.1, C5.1, C6.1, C57.1, C58.1, C59.1, C60.1, FB1.2, MOD1.8 (5V), R12.2, R53.2, R64.2, R65.2, U11.3 (DVDD), U11.21 (AVDD), U11.24 (PVDD), U12.14, U13.6 (VCCB)
AMT_CORE1: C10.1, U14.11
AMT_CORE2: C11.1, U14.22
AMT_CORE3: C12.1, U14.41
AMT_CVBS1: C8.2, R11.1, U14.1
AMT_CVBS_PRE: C8.1, R10.2
AMT_FLASH_C: U15.1 (CS), U16.4 (1A)
AMT_FLASH_CLK: TP41.1, U14.20, U16.5 (2B1)
AMT_FLASH_CLK_ESP: U1.28 (IO33), U16.6 (2B2)
AMT_FLASH_CS: TP40.1, U14.17, U16.2 (1B1)
AMT_FLASH_CS_ESP: U1.26 (IO26), U16.3 (1B2)
AMT_FLASH_C_CLK: U15.6 (CLK), U16.7 (2A)
AMT_FLASH_C_MISO: U15.2 (MISO), U16.12 (4A)
AMT_FLASH_C_MOSI: U15.5 (MOSI), U16.9 (3A)
AMT_FLASH_MISO: TP43.1, U14.19, U16.14 (4B1)
AMT_FLASH_MISO_ESP: U1.33 (IO37), U16.13 (4B2)
AMT_FLASH_MOSI: TP42.1, U14.18, U16.11 (3B1)
AMT_FLASH_MOSI_ESP: U1.29 (IO34), U16.10 (3B2)
AMT_FLASH_SEL: R5.1, U1.32 (IO36), U16.1 (S)
AMT_RESET: R13.1, TP39.1, U1.34 (IO38), U14.63
AMT_VCOM: C68.1, U14.4
AMT_XTAL_IN: C16.1, R18.2, U14.15, Y2.3
AMT_XTAL_OUT: C15.1, R18.1, U14.14, Y2.1
AUDIO_ENABLE: C20.1, R8.1, R16.1, TP49.1, U1.10 (IO6), U21.1 (CTRL)
AUDIO_I2S_BCLK: TP46.1, U1.35 (IO39), U21.3 (BCLK)
AUDIO_I2S_DATA: TP48.1, U1.44 (IO46), U21.4 (SDATA)
AUDIO_I2S_WS: TP47.1, U1.41 (IO45), U21.2 (LRCLK)
BACKLIGHT_PWM: U1.27 (IO47), U17.5 (CTRL)
BAT_CELL_NEG: C67.2, J3.2 (BAT-), Q1.1 (S1), R62.2, U3.4 (VSS)
BAT_NEG_SENSE: Q1.2 (D1D2), Q1.5 (D1D2)
BAT_NTC: J3.3 (NTC), R46.2, R47.1, U2.11 (TS)
BAT_PROTECTED: C31.1, R55.1, U2.13 (BAT), U2.14 (BAT), U4.3 (VDD)
BAT_RAW: J3.1 (BAT+), R56.1, TP35.1
BAT_SENSE: C67.1, R56.2, U3.5 (BAT)
BL_COMP: C54.1, U17.2 (COMP)
BL_LED_A: C55.1, C56.1, D1.1 (K), J1.2 (LEDA), TP52.1
BL_LED_K: J1.1 (LEDK), R9.1, TP53.1, U17.1 (FB)
BL_SW: D1.2 (A), L4.2, U17.4 (SW)
BUZZER_5V: BZ1.1 (+), C82.1, C83.2, D2.1 (K), R101.2
BUZZER_GATE: Q2.1 (G), R6.2, R7.1
BUZZER_LOW: BZ1.2 (-), D2.2 (A), Q2.3 (D), R102.1, TP45.1
BUZZER_PWM: R6.1, TP44.1, U1.31 (IO35)
BUZZER_SNUB: C83.1, R102.2
CHARGER_INT: R71.1, U1.39 (IO43), U2.7 (INT)
CHG_BTST: C30.1, U2.21 (BTST)
CHG_DSEL: R45.1, U2.24 (DSEL)
CHG_ILIM: R42.1, U2.10 (ILIM)
CHG_QON: R44.1, U2.12 (QON)
CHG_STAT: R43.1, U2.4 (STAT)
CHG_SW: C30.2, L1.1, U2.19 (SW), U2.20 (SW)
CRSF_RX: ESD4.2 (RX), J6.4 (TX), R100.1
CRSF_RX_MCU: R100.2, U1.22 (IO18)
CRSF_TX: ESD4.1 (TX), J6.3 (RX), R99.2
CRSF_TX_MCU: R99.1, U1.21 (IO17)
CTRL_0_0: J9.1 (C0), R73.1, U18.4 (P00)
CTRL_0_1: J9.2 (C1), R74.1, U18.5 (P01)
CTRL_0_2: J9.3 (C2), R75.1, U18.6 (P02)
CTRL_0_3: J9.4 (C3), R76.1, U18.7 (P03)
CTRL_0_4: J9.5 (C4), R77.1, U18.8 (P04)
CTRL_0_5: J9.6 (C5), R78.1, U18.9 (P05)
CTRL_0_6: J9.7 (C6), R79.1, U18.10 (P06)
CTRL_0_7: J9.8 (C7), R80.1, U18.11 (P07)
CTRL_0_8: J9.9 (C8), R81.1, U18.13 (P10)
CTRL_0_9: J9.10 (C9), R82.1, U18.14 (P11)
CTRL_0_10: J9.11 (C10), R83.1, U18.15 (P12)
CTRL_0_11: J9.12 (C11), R84.1, U18.16 (P13)
CTRL_0_12: J9.13 (C12), R85.1, U18.17 (P14)
CTRL_0_13: J9.14 (C13), R86.1, U18.18 (P15)
CTRL_0_14: J9.15 (C14), R87.1, U18.19 (P16)
CTRL_0_15: J9.16 (C15), R88.1, U18.20 (P17)
CTRL_1_0: J9.17 (C16), R89.1, U19.4 (P00)
CTRL_1_1: J9.18 (C17), R90.1, U19.5 (P01)
CTRL_1_2: J9.19 (C18), R91.1, U19.6 (P02)
CTRL_1_3: J9.20 (C19), R92.1, U19.7 (P03)
CTRL_1_4: J9.21 (C20), R93.1, U19.8 (P04)
CTRL_1_5: J9.22 (C21), R94.1, U19.9 (P05)
DISPLAY_3V3: C19.1, C52.1, FB2.1, FB3.1, FB4.1, L5.2, TP32.1, U10.6 (VOS)
DISPLAY_3V3_A: C69.1, C73.1, FB2.2, U14.16, U14.64
DISPLAY_3V3_D: C9.1, C70.1, C71.1, C72.1, FB3.2, R13.2, U14.10, U14.21, U14.40, U14.62, U15.3 (WP), U15.7 (HOLD), U15.8 (VCC), U16.16 (VCC)
DISPLAY_3V3_PG: R50.1, U10.8 (PG)
DISP_SW: L5.1, U10.7 (SW)
ELRS_BOOT: J6.5 (BOOT), TP22.1
ELRS_RESET: J6.6 (RESET), TP23.1
EN_3V3_SD: R36.1, U19.11 (P07), U22.3 (ON)
EN_5V_DISPLAY: U8.3 (ON), U19.14 (P11)
EN_5V_ELRS: U9.3 (ON), U19.15 (P12)
EN_5V_VIDEO: U7.3 (ON), U19.13 (P10)
ESP_BOOT: R104.1, TP54.1, U1.4 (IO0)
ESP_EN: R3.1, TP55.1, U1.45 (EN)
EXP_INT: R70.1, U1.14 (IO10), U18.1 (INT), U19.1 (INT)
GAUGE_ALERT: R72.1, U1.40 (IO44), U4.5 (ALRT)
GAUGE_CELL: C62.1, R55.2, U4.2 (CELL)
GAUGE_CTG: C61.1, U4.1 (CTG)
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

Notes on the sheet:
OpenPocket Rev A — Engineering Prototype

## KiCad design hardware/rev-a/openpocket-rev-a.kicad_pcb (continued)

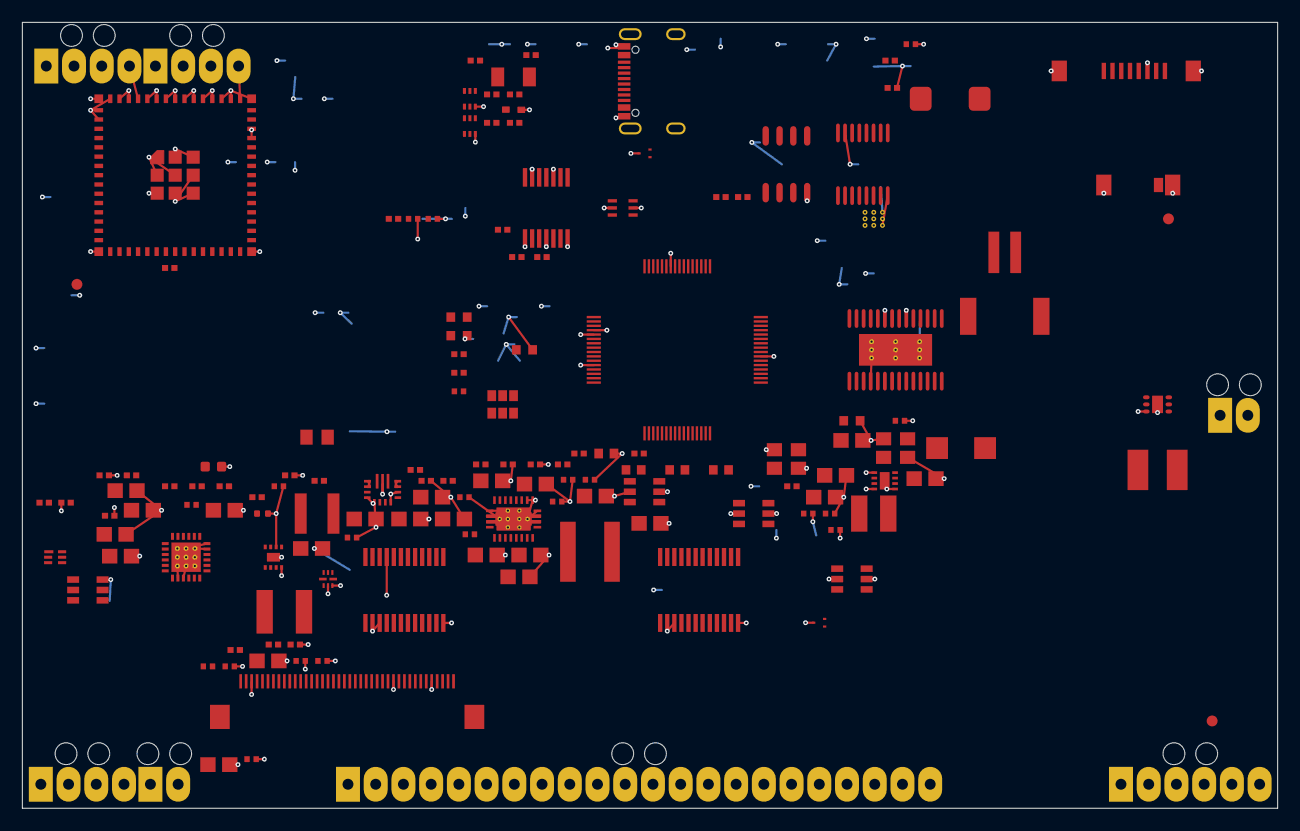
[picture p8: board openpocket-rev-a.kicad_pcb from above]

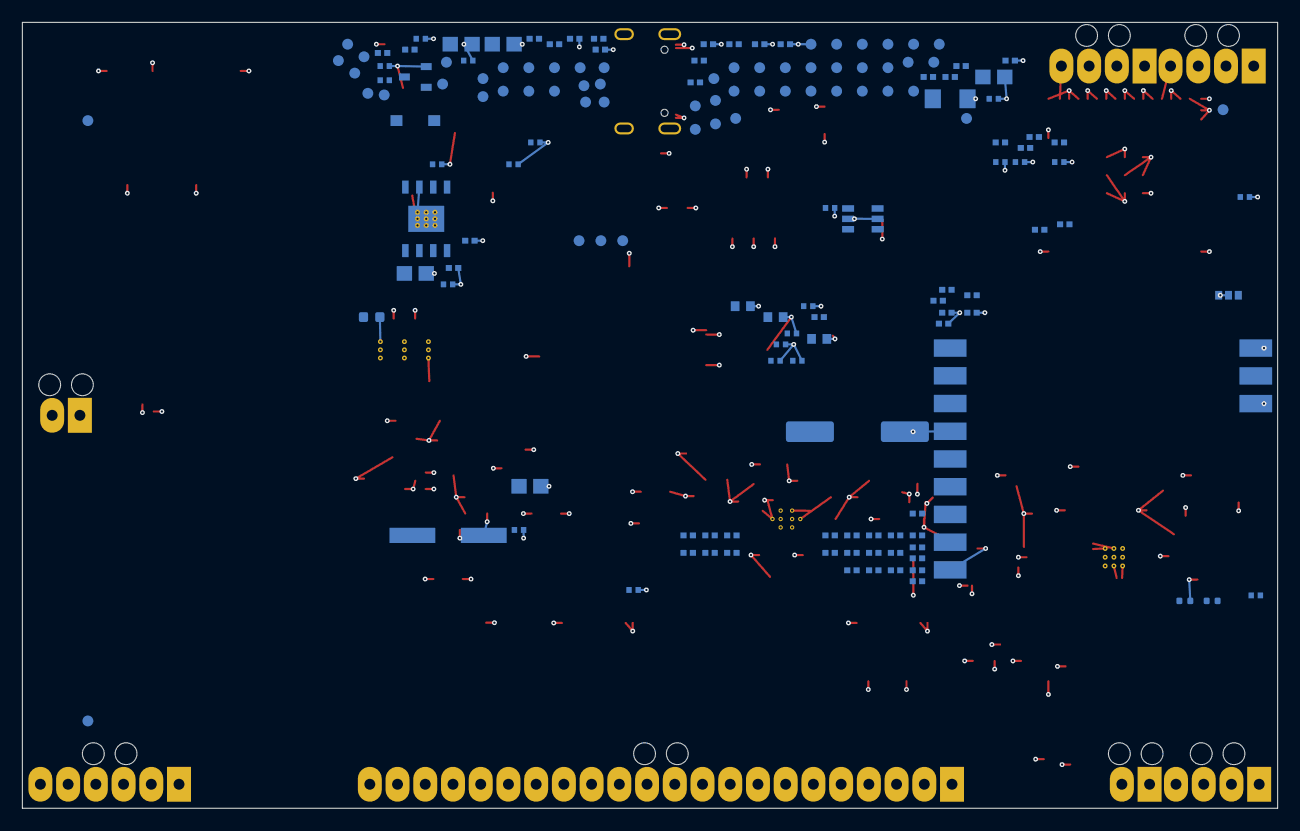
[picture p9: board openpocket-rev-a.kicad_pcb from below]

Board: 8 copper layers, 115.0 x 72.0 mm, 302 parts (155 on the bottom side), 234 nets.

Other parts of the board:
FID1, FID2, FID3, FID4, FID5, FID6: Fiducial_1mm_Mask2mm

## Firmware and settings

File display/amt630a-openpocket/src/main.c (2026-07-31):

#include "amt630a.h"

void register_write(uint16_t address, uint8_t value)
{
  *((volatile __xdata uint8_t*)address) = value;
}

uint8_t register_read(uint16_t address)
{
  return *((volatile __xdata uint8_t*)address);
}

void delay_cycles(uint16_t cycles)
{
  volatile uint16_t index;
  for (index = 0; index < cycles; ++index) {
    __asm nop __endasm;
  }
}

void main(void)
{
  uint16_t index;
  uint8_t stable = 0;
  uint8_t prior_standard = 0xff;

  // Power and PLL settling occurs with panel backlight held off externally.
  delay_cycles(60000);
  for (index = 0; index < openpocket_register_count; ++index) {
    register_write(openpocket_registers[index].address,
                   openpocket_registers[index].value);
  }
  status_i2c_initialize();
  status_update(0x03, 0);

  for (;;) {
    const uint8_t detect = register_read(0xfe2a);
    const uint8_t current_standard =
        (detect & 0x10u) == 0 ? 0u :
        ((register_read(0xfe28) & 0x04u) != 0 ? 2u : 1u);
    if (current_standard == prior_standard) {
      if (stable != 0xffu) ++stable;
    } else {
      stable = 0;
      prior_standard = current_standard;
    }
    if (current_standard == 0) {
      // Keep the TCON running; periodically request decoder resynchronization.
      register_write(0xfea0, 0x01);
      delay_cycles(256);
      register_write(0xfea0, 0x00);
      status_update(0x03, 0);
    } else if (stable >= 4) {
      status_update(0x07, current_standard);
    } else {
      status_update(0x03, 4);
    }
    delay_cycles(12000);
  }
}

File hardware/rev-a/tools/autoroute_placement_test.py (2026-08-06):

#!/usr/bin/env python3
"""Build an autoroute-feasibility placement from the reviewed Rev-A PCB.

This is deliberately a test harness, not a production-layout generator.
Mechanical connectors remain fixed. Major electrical blocks are moved to a
connectivity-oriented floorplan, small parts follow their most likely owner,
and the project's own ground-fanout implementation is then reapplied.
"""

from __future__ import annotations

import argparse
import importlib.util
import json
import math
from pathlib import Path
import sys

import pcbnew


BOARD_W = 115.0
BOARD_H = 72.0
GND_NAMES = {"", "GND", "NC"}

FIXED_REFS = {
    "J1", "J2", "J3", "J4", "J5", "J6", "J7", "J8", "J9",
    "J11", "J12", "J13",
    "FID1", "FID2", "FID3", "FID4", "FID5", "FID6",
}

# Corrected for the *actual committed board*: J1 is fixed at (29.75, 26.00).
# Coordinates are desired centres; the legalizer may nudge a part locally.
PROPOSED = {
    "U1": (70.0, 25.0),
    "U2": (16.0, 60.0),
    "U3": (3.0, 58.0),
    "Q1": (7.0, 62.0),
    "U4": (25.0, 59.0),
    "U20": (31.0, 61.0),
    "U5": (54.0, 54.0),
    "U6": (67.0, 52.0),
    "U7": (46.0, 52.0),
    "U8": (80.0, 49.0),
    "U9": (99.0, 58.0),
    "U10": (86.0, 44.0),
    "MOD1": (16.0, 40.0),
    "U11": (35.0, 51.0),
    "U12": (53.0, 47.0),
    "U13": (58.0, 43.0),
    "U14": (35.0, 38.0),
    "U15": (48.0, 33.0),
    "U16": (55.0, 35.0),
    "U17": (18.0, 34.0),
    "U18": (45.0, 62.0),
    "U19": (74.0, 62.0),
    "U21": (92.0, 25.0),
    "U22": (90.0, 19.0),
    "BZ1": (89.0, 35.0),
    "Q2": (84.0, 39.0),
    "D2": (87.0, 39.0),
    "ESD1": (60.0, 12.0),
    "ESD2": (98.0, 18.0),
    "ESD3": (102.0, 18.0),
    "ESD4": (105.0, 65.0),
    "F1": (52.0, 11.0),
    "TVS1": (55.0, 11.0),
    "JP1": (31.0, 43.0),
    "Y1": (36.0, 57.0),
    "Y2": (45.0, 42.0),
    "L1": (20.0, 63.0),
    "L2": (58.0, 57.0),
    "L3": (73.0, 55.0),
    "L4": (12.0, 34.0),
    "L5": (90.0, 48.0),
    "D1": (12.0, 39.0),
    "FB1": (41.0, 51.0),
    "FB2": (45.0, 46.0),
    "FB3": (48.0, 46.0),
    "FB4": (39.0, 32.0),
}

OWNER_ANCHORS = {
    *(f"U{i}" for i in range(1, 23)),
    "MOD1", "J1", "J2", "J3", "J4", "J5", "J6", "J7", "J8",
    "J9", "J11", "J12", "J13", "BZ1",
}

CRITICAL_PREFIXES = (
    "LCD_", "USB_", "SD_", "VRX_", "OSD_", "AMT_", "RX_", "BL_",
    "CHG_", "L3V3_", "L5V_", "AUDIO_", "SPK", "CRSF_",
)

# Keep the broad RGB escape between the fixed FFC and U14 free of components.
KEEP_OUTS = {
    "F": [(18.0, 29.0, 45.0, 32.5)],
    "B": [(18.0, 29.0, 45.0, 32.5)],
}


def pos_mm(fp: pcbnew.FOOTPRINT) -> tuple[float, float]:
    p = fp.GetPosition()
    return pcbnew.ToMM(p.x), pcbnew.ToMM(p.y)


def pad_nets(fp: pcbnew.FOOTPRINT) -> set[str]:
    return {
        pad.GetNetname()
        for pad in fp.Pads()
        if pad.GetNetname() not in GND_NAMES
    }


def has_pth(fp: pcbnew.FOOTPRINT) -> bool:
    return any(
        pad.GetAttribute() in (pcbnew.PAD_ATTRIB_PTH, pcbnew.PAD_ATTRIB_NPTH)
        for pad in fp.Pads()
    )


def side_keys(fp: pcbnew.FOOTPRINT) -> tuple[str, ...]:
    if has_pth(fp):
        return ("F", "B")
    return ("B",) if fp.GetLayer() == pcbnew.B_Cu else ("F",)


def fp_box_mm(fp: pcbnew.FOOTPRINT, side: str, margin_mm: float = 0.20) -> tuple[float, float, float, float]:
    layer = pcbnew.B_CrtYd if side == "B" else pcbnew.F_CrtYd
    courtyard = fp.GetCourtyard(layer)
    merged = None
    for pad in fp.Pads():
        pb = pad.GetBoundingBox()
        if merged is None:
            merged = pcbnew.BOX2I(pb.GetOrigin(), pb.GetSize())
        else:
            merged.Merge(pb)
    if merged is None:
        bb = fp.GetBoundingBox()
        merged = pcbnew.BOX2I(bb.GetOrigin(), bb.GetSize())
    if not courtyard.IsEmpty():
        merged.Merge(courtyard.BBox())
    merged = merged.GetInflated(pcbnew.FromMM(margin_mm))
    return (
        pcbnew.ToMM(merged.GetLeft()),
        pcbnew.ToMM(merged.GetTop()),
        pcbnew.ToMM(merged.GetRight()),
        pcbnew.ToMM(merged.GetBottom()),
    )


def intersects(a: tuple[float, float, float, float],
               b: tuple[float, float, float, float]) -> bool:
    return not (
        a[2] <= b[0] or b[2] <= a[0] or
        a[3] <= b[1] or b[3] <= a[1]
    )


def in_bounds(bb: tuple[float, float, float, float]) -> bool:
    return bb[0] >= 0.8 and bb[1] >= 0.8 and bb[2] <= BOARD_W - 0.8 and bb[3] <= BOARD_H - 0.8


def candidate_offsets(max_radius: float, step: float = 0.5):
    yield (0.0, 0.0)
    rings = int(max_radius / step)
    for ring in range(1, rings + 1):
        r = ring * step
        for index in range(-ring, ring + 1):
            v = index * step
            yield (v, -r)
            yield (v, r)
            yield (-r, v)
            yield (r, v)


def legal_place(
    fp: pcbnew.FOOTPRINT,
    desired: tuple[float, float],
    occupied: dict[str, list[tuple[float, float, float, float]]],
    max_radius: float,
) -> tuple[float, float]:
    for dx, dy in candidate_offsets(max_radius):
        x, y = desired[0] + dx, desired[1] + dy
        fp.SetPosition(pcbnew.VECTOR2I_MM(x, y))
        boxes = [(side, fp_box_mm(fp, side)) for side in side_keys(fp)]
        if any(not in_bounds(bb) for _, bb in boxes):
            continue
        blocked = False
        for side, bb in boxes:
            if any(intersects(bb, other) for other in occupied[side]):
                blocked = True
                break
            if any(intersects(bb, ko) for ko in KEEP_OUTS[side]):
                blocked = True
                break
        if blocked:
            continue
        for side, bb in boxes:
            occupied[side].append(bb)
        return x, y
    raise RuntimeError(
        f"{fp.GetReference()}: no legal placement within {max_radius:.1f} mm "
        f"of {desired[0]:.1f},{desired[1]:.1f}"
    )
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

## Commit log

2026-07-31 Add OpenPocket Rev-A engineering release gates
    [bom.csv, consigned-parts.csv, dnp.csv]
2026-07-31 docs(hardware): specify Revision-A microSD subsystem
    [microsd-pin-audit.csv]
2026-08-05 feat(hardware): add Revision-A KiCad engineering draft
    [amt630a-pin-audit.csv, bom-generic.csv, bom-jlcpcb.csv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]
2026-08-05 feat(hardware): harden Revision-A preproduction design
    [bom-generic.csv, bom-jlcpcb.csv, bom.csv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]
2026-08-05 feat(hardware): add deterministic ground fanout
    [openpocket-rev-a.kicad_pcb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]
2026-08-05 hardware: establish reviewed eight-layer Rev A basis
    [bom-generic.csv, bom-jlcpcb.csv, bom.csv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]
2026-08-05 hardware: finalize bottom-side U.FL sourcing
    [bom-generic.csv, bom-jlcpcb.csv, bom.csv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]
2026-08-05 hardware: place display FFC for bottom insertion
    [openpocket-rev-a.kicad_pcb]
2026-08-06 test: work around KiCad SWIG proxy invalidation
2026-08-06 test: isolate track stripping from placement process
2026-08-06 test: defer ground fanout until after routing
2026-08-06 routing: exclude plane-connected GND pins from signal autorouter
2026-08-06 ci: route signals without plane-connected GND ratsnest
2026-08-06 routing: add generic staged DSN preparation tool
2026-08-06 ci: add staged power-first autoroute
2026-08-06 ci: import partial power route and report remaining pads
2026-08-06 ci: rerun power diagnosis with placement restore
2026-08-06 routing: seed remaining local power escapes
2026-08-06 ci: rerun power stage with completed local escapes
2026-08-06 ci: test power routing with legal clearances and small escapes
2026-08-06 routing: complete three local power escapes
2026-08-06 ci: complete and gate clean power routing
